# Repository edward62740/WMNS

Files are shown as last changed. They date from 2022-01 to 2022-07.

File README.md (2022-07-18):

# Wireless Mesh Network System (WMNS)

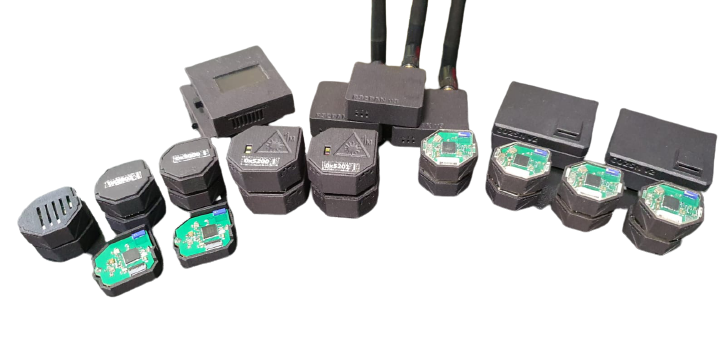
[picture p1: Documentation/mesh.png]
Mesh Devices


## Overview

This is a wireless sensor network system as a part of an ongoing project for smart home sensing and security. The intent is to create easily deployable, low-maintenance (thereby low-power) sensors for real-time collection of non-sensitive data. The various sensors have a battery life typically between 1-4 years off a CR2032 (excl. CO2SN - 4 months, Li-ion).
The data is collected in InfluxDB and can be viewed graphically in Grafana.
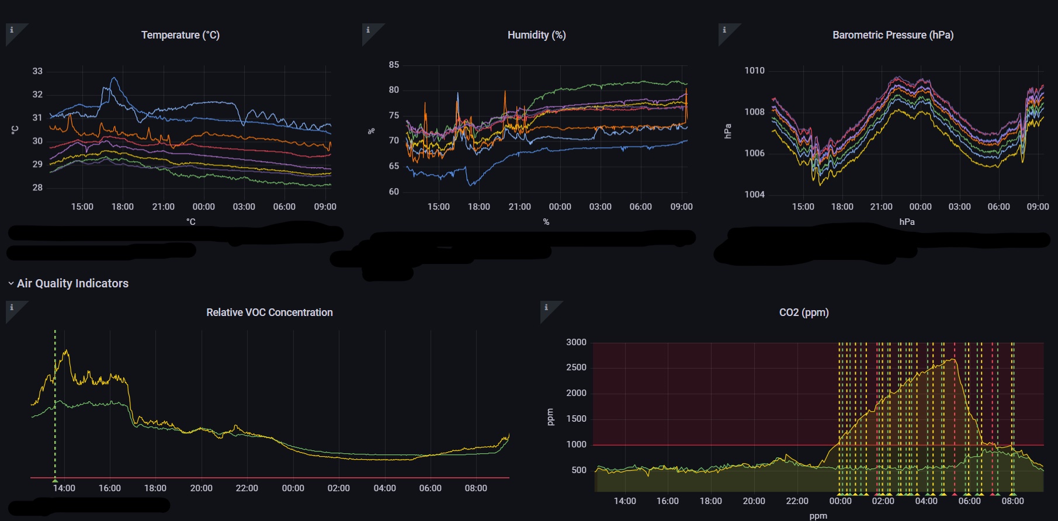
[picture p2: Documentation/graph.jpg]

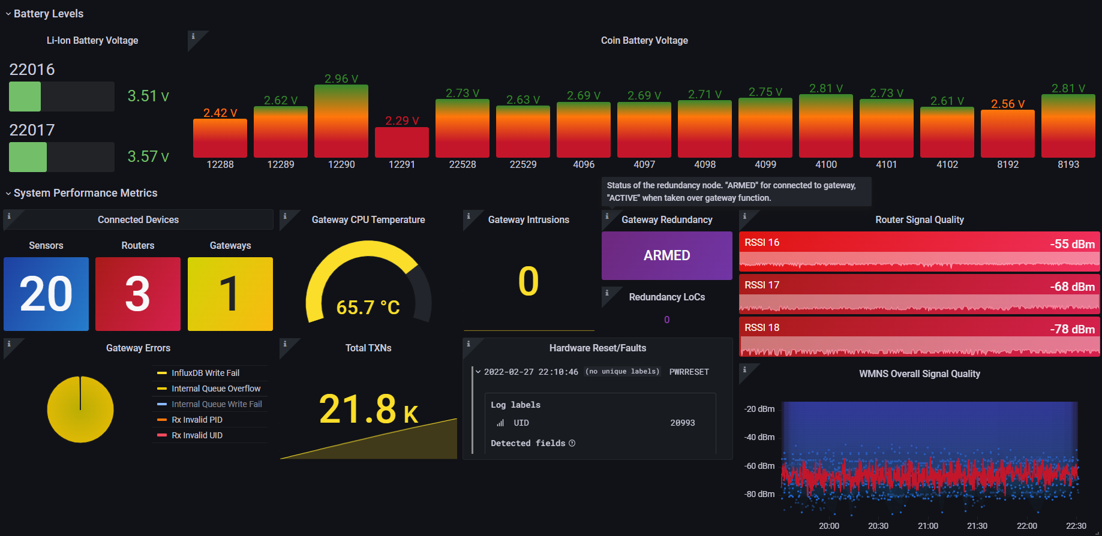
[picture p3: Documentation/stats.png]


## Related Development
_These devices either contribute to the WMNS database or utilize it for their functions._<br>
[PMS](https://github.com/edward62740/wmns-pms) - Particulate matter sensor.<br>
[IN-16 Display](https://github.com/edward62740/wmns-in16) - IN-16 tubes for displaying database information.<br>
[E-Paper Display](https://github.com/edward62740/wmns-epd) - Simple Wi-Fi/BLE enabled e-paper display. Designed for displaying real-time sensor data.<br>
[Lamp](https://github.com/edward62740/wmns-epd) - Mood lamp simulating candle flicker.<br>
[Transposer](https://github.com/edward62740/wmns-transposer) - Python script to transfer data from InfluxDB to Firebase RTDB.<br>

## Network Structure
This wireless mesh network is a proprietary, decentralized flood type network. The network consists of three distinct node types: routers (R), gateways (GT) and low-power end devices (LP).\
Routers retransmit received data to form the backbone of the network.\
Gateways are similar to routers and forward mesh network data to a server/cloud.\
End devices are low-power nodes that sleep for most of the time, periodically transmitting data.

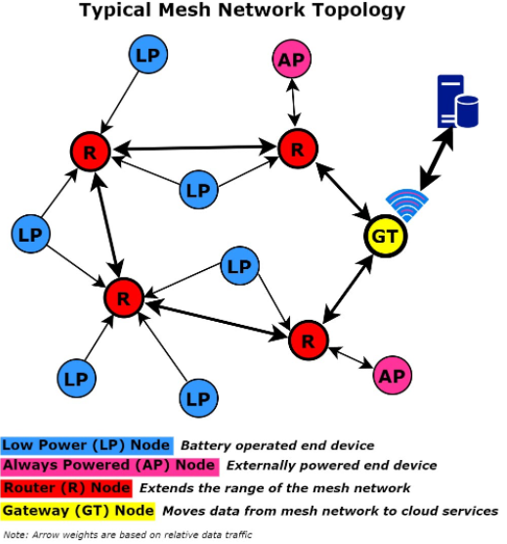
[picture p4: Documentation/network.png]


## Measured data
Currently, the following data is collected by the system through multiple sensor types (sensors in brackets, not necessarily utilized as such):
* Temperature (BME280, BME680, Si7021, SCD41, BMA400, mcu_internal)
* Relative humidity (BME280, BME680, Si7021, SCD41)
* Barometric pressure (BME280, BME680)
* Illuminance (OPT3001, VEML6030, Si1133/5)
* UV levels (Si1133/5)
* Sudden/discontinous motion (BMA400)
* Person counter (VL53L1X)
* CO2 concentration (SCD41)
* VOC concentration (BME680)
* Battery levels (ADC)
* Signal strength (radio)

## Custom Hardware Devices
GPSN             |  LRSN      |  CO2SN  | ALSN
:-------------------------:|:-------------------------:|:-------------------------:|:-------------------------:
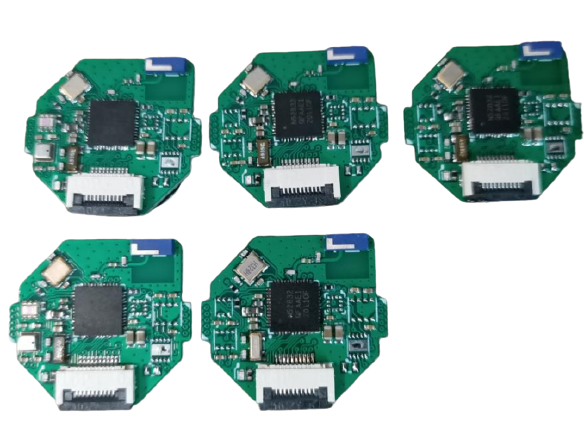
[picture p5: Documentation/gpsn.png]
GPSN
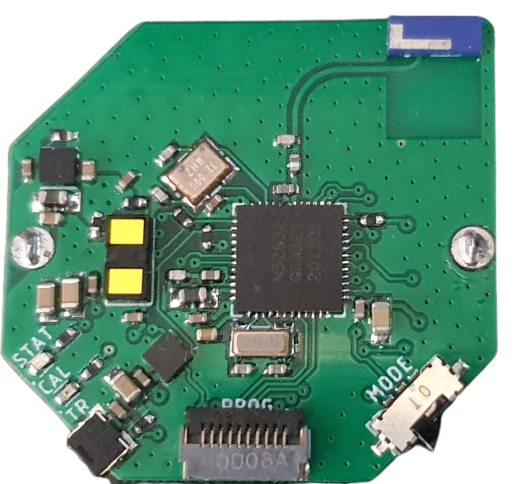
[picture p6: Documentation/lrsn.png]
LRSN
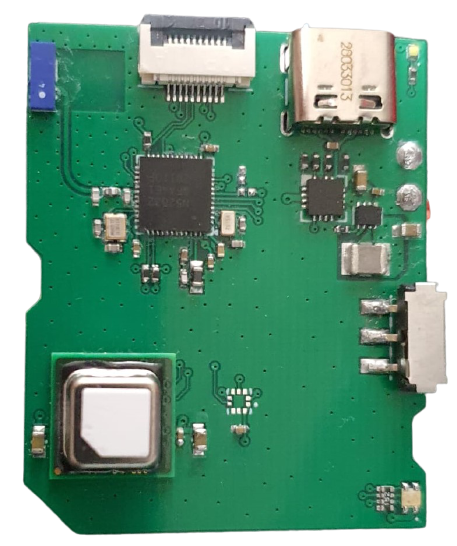
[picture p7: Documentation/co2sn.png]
CO2SN
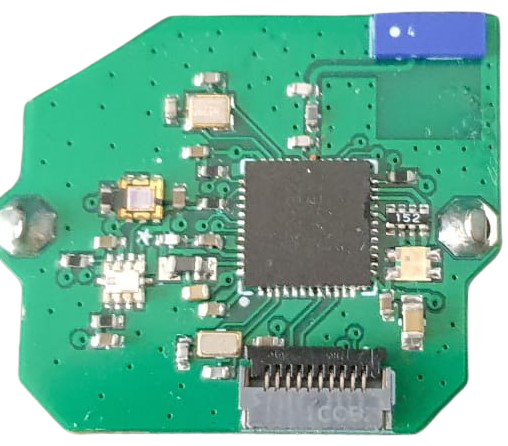
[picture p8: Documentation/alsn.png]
ALSN
<br />General-purpose configurable sensor for: temperature, humidity, air pressure, light, VOCs, motion|<br />Person counter sensor |  <br />Carbon dioxide concentration sensor | <br />Specialized light sensor for visible, UV, IR

GATEWAY             |  ROUTER32PA      |  ROUTER40  | LTSN | TERMINAL
:-------------------------:|:-------------------------:|:-------------------------:|:-------------------------:|:-------------------------:
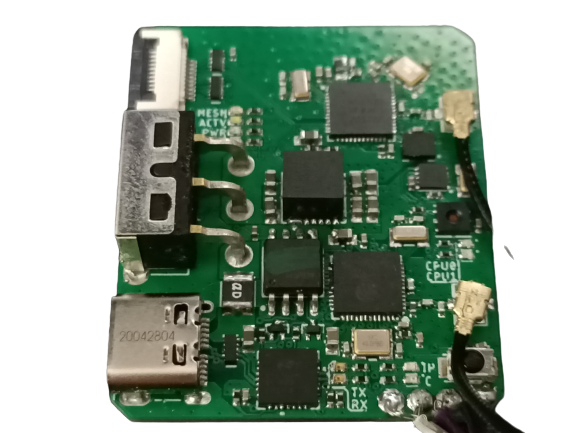
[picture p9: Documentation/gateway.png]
GATEWAY
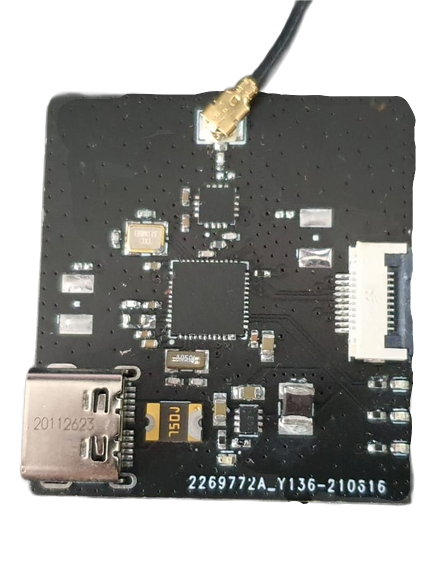
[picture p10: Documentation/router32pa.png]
ROUTER32PA
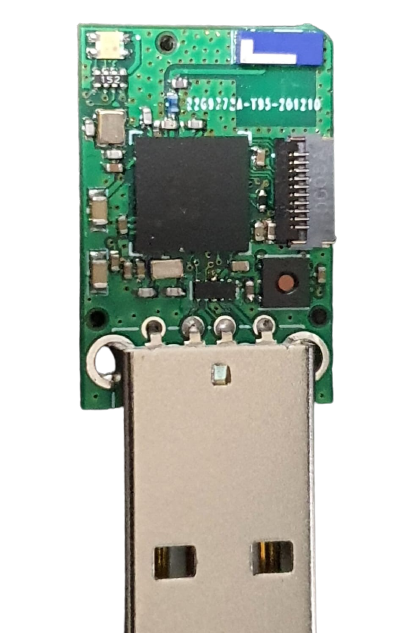
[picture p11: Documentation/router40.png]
ROUTER40
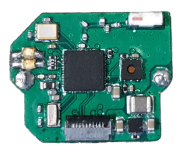
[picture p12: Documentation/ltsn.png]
LTSN
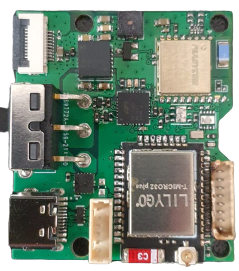
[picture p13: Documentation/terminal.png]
TERMINAL
<br />Internet gateway node  |<br />Power amplified router node |  <br />USB-powered router node |<br />Specialized temp sensor for sub-zero|<br />Security node and gateway redundancy.

## Performance

The following performance factors were considered during the design of the WMNS:
* Low maintenance - essentially long battery life and reliability
</br> _Low power circuit and software design from bottom up. Certain sensors (i.e those expected to face harsher conditions) are conformally coated to increase reliability._
</br> _Network has no central "coordinator" type node which is required to sustain the network. Packets can take multiple paths to the gateway. Gateways can be configured as redundancies._
</br> _Connectionless protocol. No risk of runtime disconnections, failed acks etc. Sensors only need initial positioning in an area with good RSSI and reasonable packet loss from multipath fading._
* Ease of use - able to easily add more sensors (and more types), and modify configurations.
</br> _Easy plug-and-play to add more sensors. Only the gateway needs modifications to add new sensor types (for database side processing)._
</br> _Sensors can easily be configured for different sample rates._
* Range - good wireless range vs power consumption compromise
</br> _Tuned internal antennas allow for lower tx power (and less power consumption)._ 
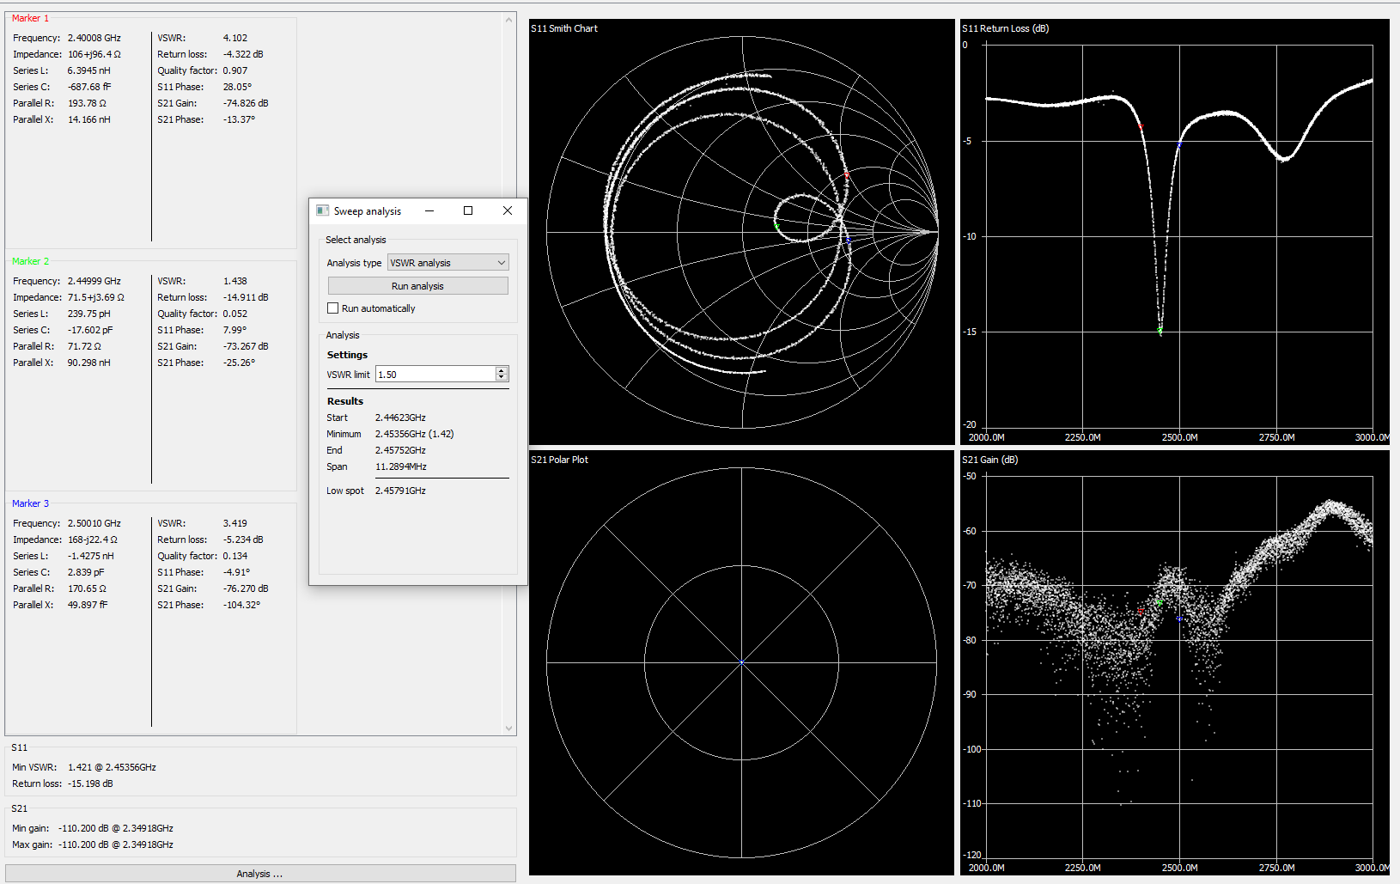
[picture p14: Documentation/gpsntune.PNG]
GPSN Return Loss
</br>
* Low-cost - cheap sensors
</br> _Runs off comparatively low-cost and widely used nRF52 series SoCs. Same design template was used across sensors to drop development time and costs._
</br> _No protocol overhead or IP costs involved._

## Deployment

This system has been deployed in stages since Q1 21 with zero system failures (e.g gateway restarts, sensor malfunctions and drops out of network, hardware failure).
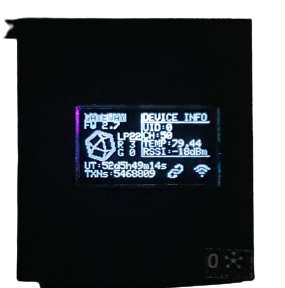
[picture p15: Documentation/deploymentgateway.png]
Gateway Deployment v3.0.1
</br>
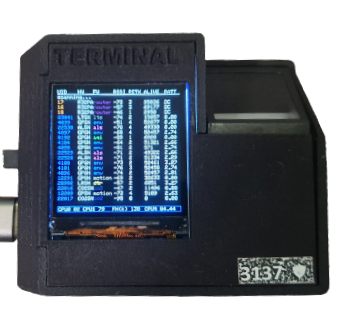
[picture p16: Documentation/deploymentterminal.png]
Terminal Deployment v3.0.1

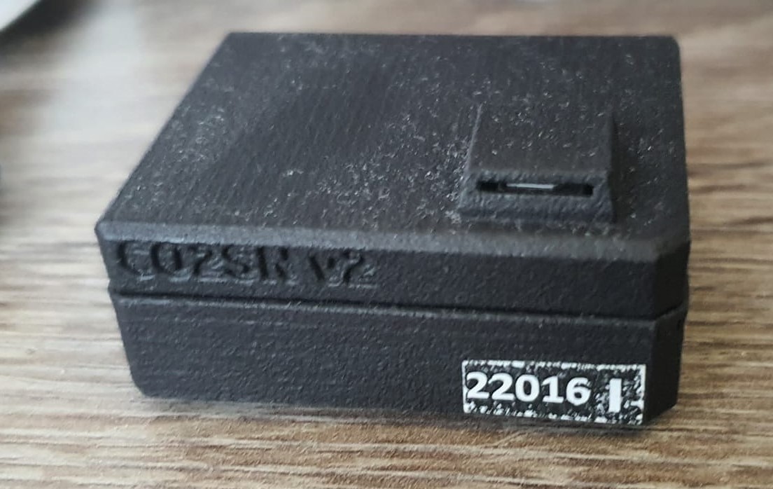
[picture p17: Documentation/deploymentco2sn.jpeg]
CO2SN Deployment v3.0.1

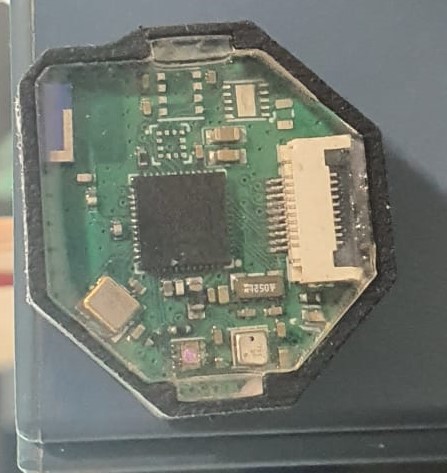
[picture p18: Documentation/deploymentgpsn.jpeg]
GPSN Deployment v3.0.1

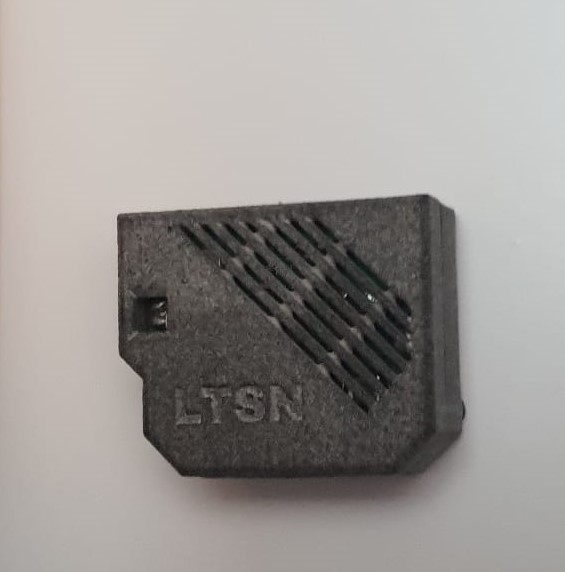
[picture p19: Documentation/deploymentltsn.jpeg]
LTSN Deployment v3.0.1

</br>
Deployed devices: 28

<br>
This repo is released under the GPL-2.0 License. Related repos DO NOT INHERIT licenses.

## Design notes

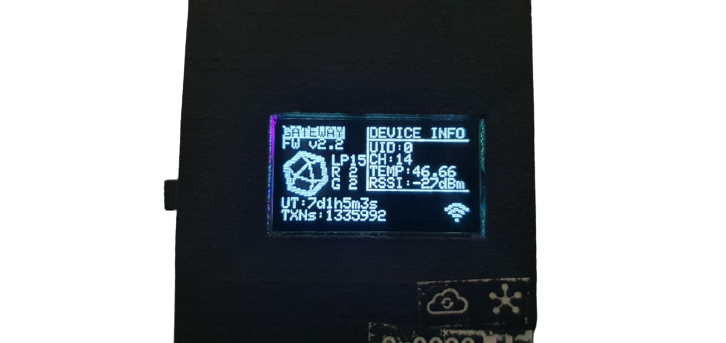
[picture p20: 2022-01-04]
Documentation/gatewayui.png

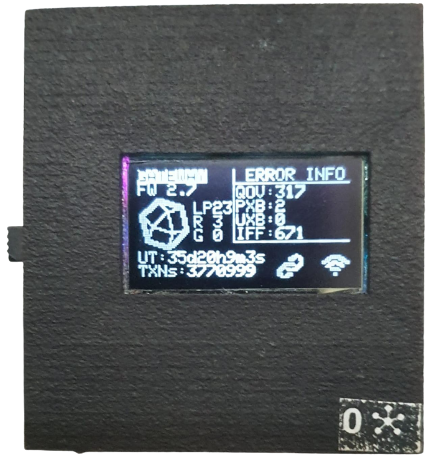
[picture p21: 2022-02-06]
Documentation/deployment.png

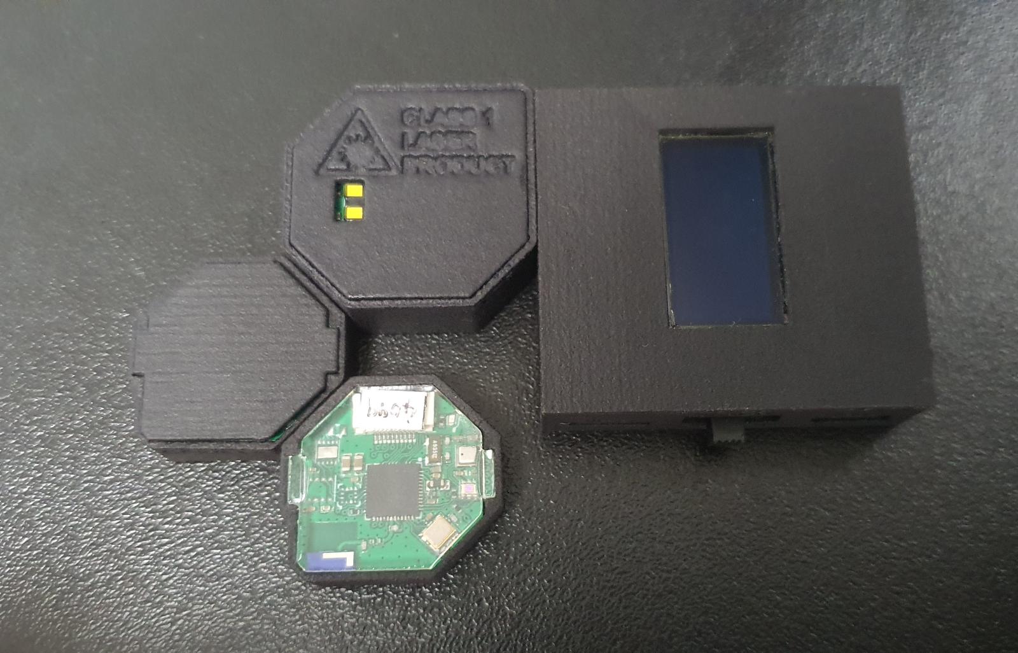
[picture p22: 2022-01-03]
Software Files/nrf_firmware/docu/meshsensorspartial.jpeg

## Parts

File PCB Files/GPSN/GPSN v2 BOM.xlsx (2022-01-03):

Comment | Designator | Footprint
22p | C1 | C0402
22p | C2 | C0402
12p | C3 | C0402
12p | C4 | C0402
10u | C5 | C0402
4.7u | C6 | C0402
100n | C7 | C0603R
0.8p | C8 | C0402
1.2p | C9 | C0402
1u | C10 | C0402
100n | C11 | C0402
1u | C12 | C0402
100n | C13 | C0402
100u | C14 | C0402
100n | C15 | C0402
1u | C16 | C0603R
100n | C17 | C0402
100n | C18 | C0402
100n | C19 | C0402
1u | C29 | C0402
VLMG1500-GS08 | D7 | LEDC1005X35N
3.9u | L1 | INDC0402X26N
10u | L2 | L0603
2.2u | L3 | INDC0402X26N
2.0X1.2 | Q1
10K | R1 | R0402
4.7k | R2 | R0402
4.7k | R3 | R0402
1.5k | R7 | R0402
NRF52832 | U$1 | QFN40P600X600X90-48_N
TI-OPT3001 | U$3 | TI-OPT3001
CHIPANTENNAL2 | U$4 | CHIPANTENNAL2
PCF85063ATL | U1 | SOT1197-1
BME280 | U2 | PSON65P250X250X100-8N
BMA400 | U3 | XDCR_BMA400
52892-1095 | U5 | MOLEX_52892-1095
BME680 | U6 | PSON80P300X300X100-8N
32.768kHz | X1 | ABS07-32.768KHZ-T
32MHz | Y1 | CRYSTAL-SMD-3.2X2.5MM

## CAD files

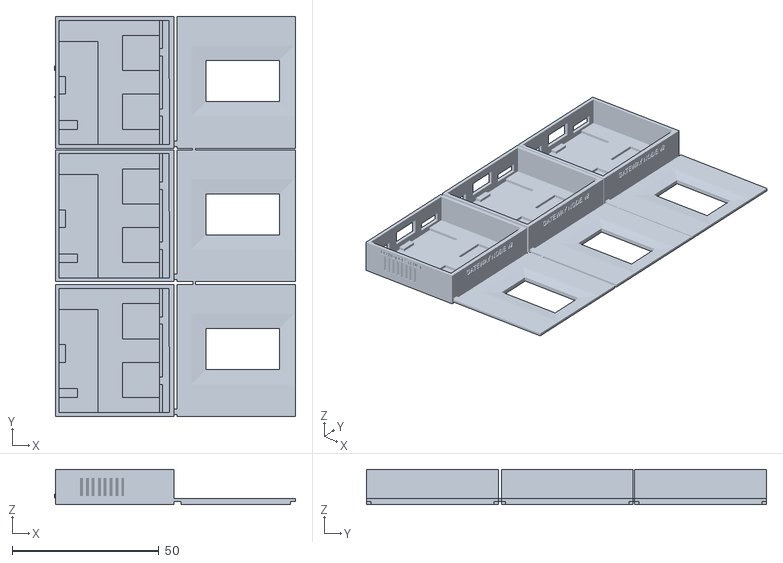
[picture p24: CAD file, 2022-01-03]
Mechanical Files/GATEWAY.stl
82.3 x 136.5 x 12.0

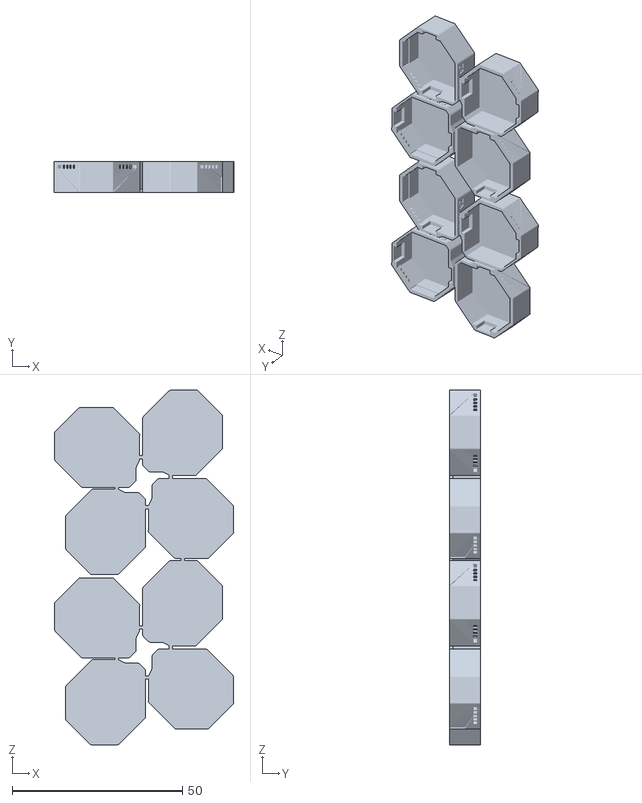
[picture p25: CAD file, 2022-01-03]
Mechanical Files/Final GPSN Enclosure v4.stl
52.7 x 9.00 x 104.2

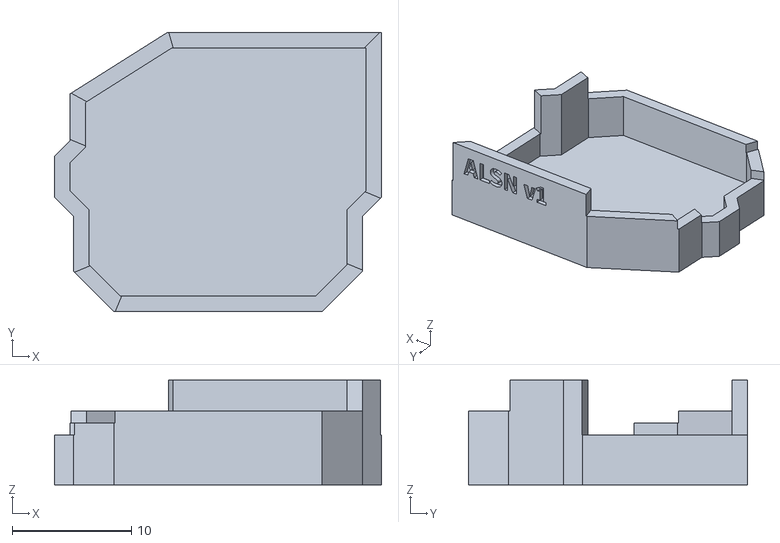
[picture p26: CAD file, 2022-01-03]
Mechanical Files/ALSN BOTTOM.stl
27.4 x 23.4 x 8.79

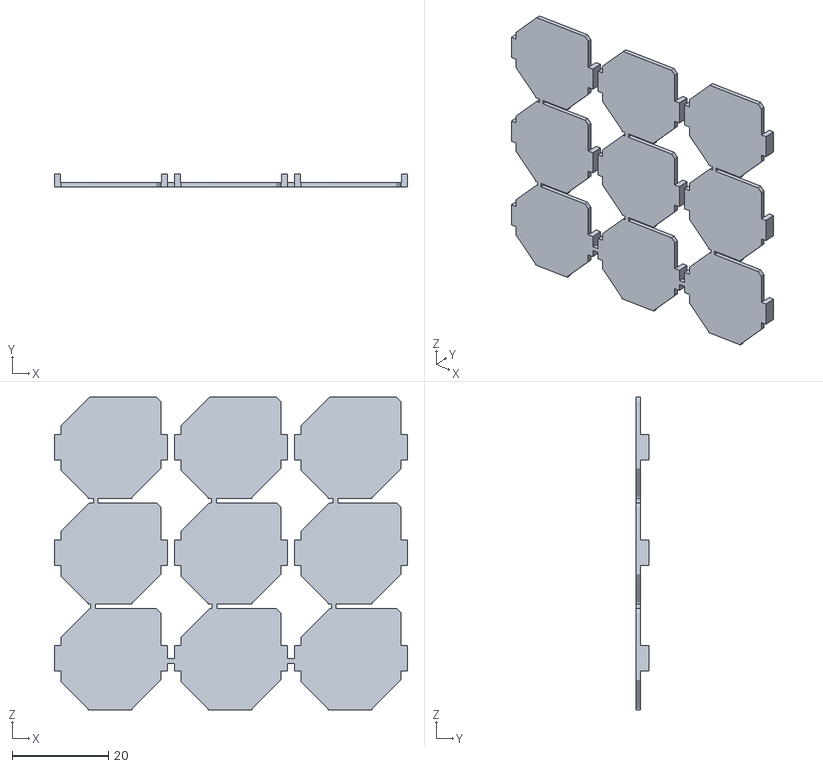
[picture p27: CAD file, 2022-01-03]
Mechanical Files/GPSN TOP.stl
73.5 x 2.80 x 65.1

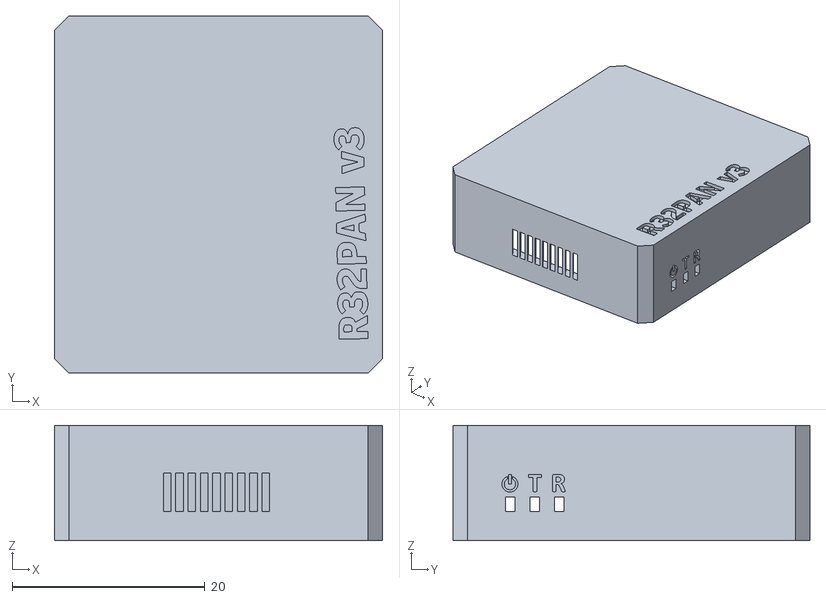
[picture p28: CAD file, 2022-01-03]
Mechanical Files/R32PAN TOP.stl
34.0 x 37.0 x 11.9

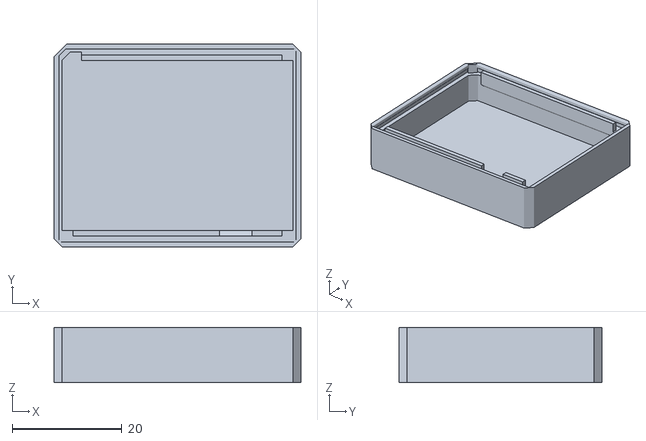
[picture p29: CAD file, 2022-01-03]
Mechanical Files/CO2SN BOTTOM.stl
45.0 x 37.0 x 10.1

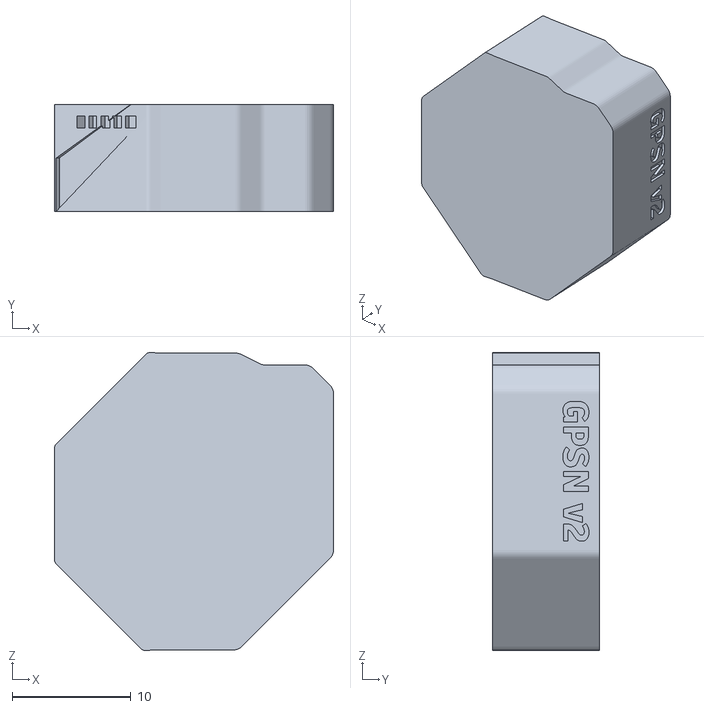
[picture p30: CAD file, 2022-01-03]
Mechanical Files/Final GPSN Enclosure x1.stl
23.5 x 9.00 x 25.1

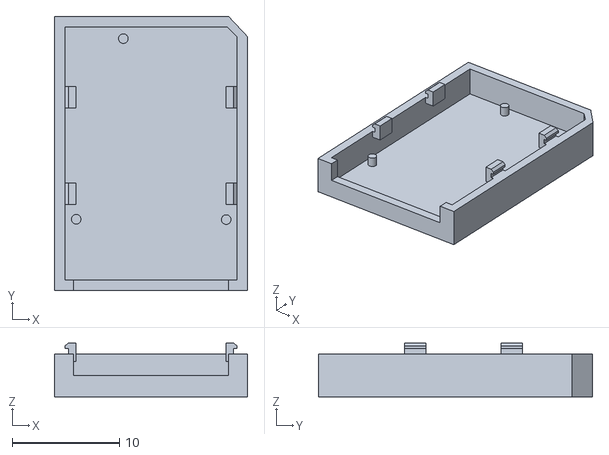
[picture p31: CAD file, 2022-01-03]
Mechanical Files/ROUTER40 BOTTOM.stl
18.0 x 25.5 x 5.00

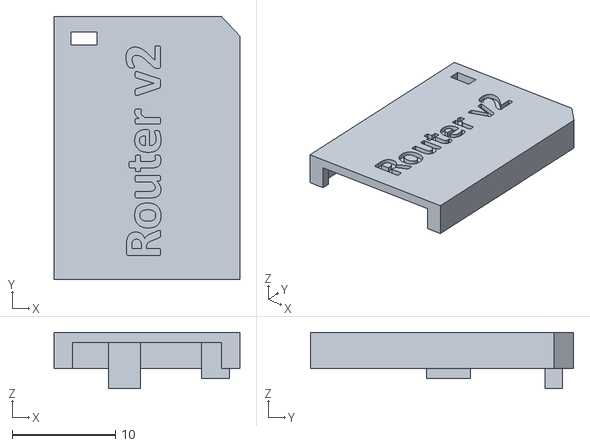
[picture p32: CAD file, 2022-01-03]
Mechanical Files/ROUTER40 TOP.stl
18.0 x 25.5 x 5.45

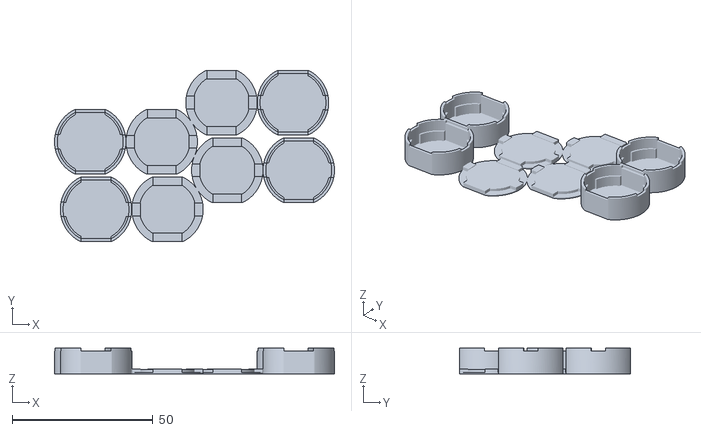
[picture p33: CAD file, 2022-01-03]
Mechanical Files/EFR32 Enclosure.stl
99.4 x 60.8 x 9.20

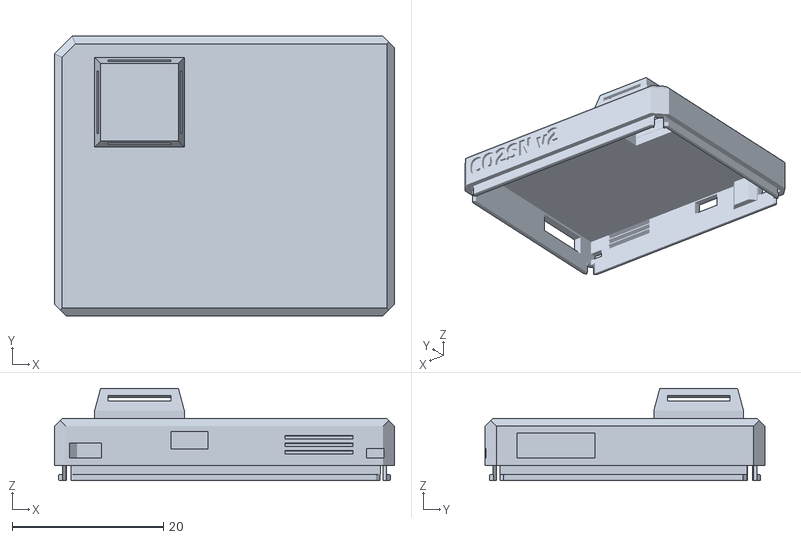
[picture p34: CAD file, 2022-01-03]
Mechanical Files/CO2SN TOP.stl
45.0 x 37.0 x 12.2

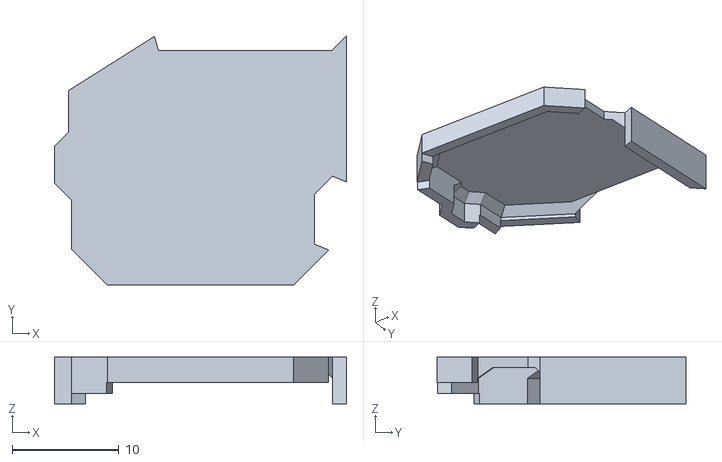
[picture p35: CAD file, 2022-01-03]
Mechanical Files/ALSN TOP.stl
27.4 x 23.4 x 4.41

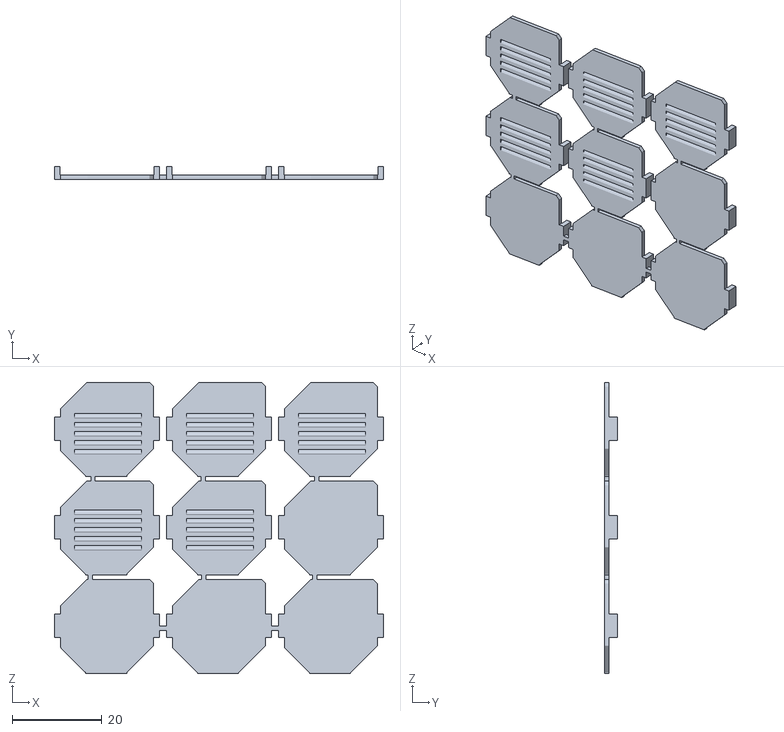
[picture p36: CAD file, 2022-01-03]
Mechanical Files/GPSN TOP VENTS.stl
73.5 x 2.80 x 65.1

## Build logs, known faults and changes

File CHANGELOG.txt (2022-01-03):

CHANGELOG FOR WMNS (nRF) FIRMWARE SINCE Q3 2021 [DEPLOYMENT PHASE]

v1
UNDOCUMENTED; FIRST REVISION OF FIRMWARE

v2.0.1 (15/6/2021)
Added (CO2SN, ALSN) firmware packages, associated board definitions and associated drivers (SCD41_API, lps22hb, si1133, veml6030).

v2.0.2 (29/6/2021)
Modified (CO2SN, ALSN) firmware packages
Cleaned unused/dereferenced.
Changed (ROUTER32PA) alive packet display tx power to 22dBm.
Added reset reason feature to mesh reset packet.
Changed mesh unicast packet function name to mesh_ucast_data().
Changed (GATEWAY) mesh tx power value to 4dBm.

v2.0.3 (8/7/2021)
Enabled mesh cmd function in (GATEWAY) firmware package.

v2.0.4 (14/7/2021)
Disabled (ROUTER32PA) rf-to-serial function.
Changed PID RESET printf value.

v2.0.5 (22/7/2021)
Deleted BME680 API packages.
Deleted (GPSN) airquality firmware, superceded by (GPSN) aqi firmware.
Added sleep mode function and corrections to drivers (bme680).
Modified delay functions in SCD41_API.

v2.0.6 (26/7/2021)
Added (CO2SN) battery voltage monitor.
Added (LRSN) continuous triggering workaround.
Modified (LRSN) packet to transmit warning byte to indicate continuous triggering.
Moved pin name declaration to board definition files.
Imported GATEWAY InfluxDB v2.4 firmware files into {root}/Software Files \.
Refactored (GPSN) iaq firmware to "voc".

v2.0.7 (02/8/2021)
Added TERMINAL v2.sch/.brd to {root}/PCB Files/Terminal \.
Added TERMINAL v1.0 to {root}/Software Files \.

v2.0.8 (14/8/2021)
Added reinitialization for bme280 to reduce power consumption of (GPSN) environment.
Added reinitialization for bme680 to reduce power consumption of (GPSN) voc.
Added intervals.txt to {root}/Software Files/nrf_firmware \.
Refactored (ALSN) alsn firmware to "als".
Moved Gateway_Firebase_v3, Gateway_Firmware_v1.4, Gateway_InfluxDB from {root}/Software Files \ to {root}/Software Files/Depreciated \.
Moved GATEWAY InfluxDB v2.5, TERMINAL v1.0 from {root}/Software Files \ to {root}/Software Files/ESP32 Firmware \.
Modified all devices MESH_PID_xxxx intervals per {root}/Software Files/nrf_firmware/intervals.txt \.

v3.0.0
Changed g_ttl to 3.
Finalized all firmware to intervals.txt.
Changed RF channel from 14 to 50.

v3.0.1 (1/1/2022)
Added (LTSN) branch.

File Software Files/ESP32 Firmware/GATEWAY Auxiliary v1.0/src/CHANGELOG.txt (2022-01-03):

CHANGELOG FOR WMNS (GATEWAY AUXILIARY-ESP32) FIRMWARE SINCE Q3 2021 [DEPLOYMENT PHASE]

v1.0 (30/8/21)
Initial.

v1.1 (31/8/21)
Changed hostname from default to "WMNS GATEWAY AUX".

v1.2 (16/9/21)
Stability update.

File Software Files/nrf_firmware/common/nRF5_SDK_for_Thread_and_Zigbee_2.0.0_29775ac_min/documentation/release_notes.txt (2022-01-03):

nRF5 SDK for Thread and Zigbee v2.0.0
---------------------------
Release Date: Week 39, 2018

This release is the production-ready release of the Thread features available on the nRF52840 chip.
The nRF52840 running the OpenThread stack is Thread 1.1 Certified (https://www.threadgroup.org/What-is-Thread#certifiedproducts).

This release is the production-ready release of the Zigbee features available on the nRF52840 chip.
The nRF52840 running the Zigbee stack conforms to Zigbee PRO R21 + Green Power Proxy specifications. The Zigbee stack provided by the release has been succesfully tested in Zigbee Alliance Authorized Test Laboratory and is pending formal approval from Zigbee Alliance as a Zigbee Compliant Platform. 
The Nordic Zigbee software solution released as part of nRF5 SDK for Thread and Zigbee incorporates the Base Device Behavior 
specification and the latest of the ZCL specification (ver. 7). This enables to build, certify, and ship commercial Zigbee 3.0 Certified Products. 

Software components and application examples for MDK, peripherals, BLE, and NFC
have been inherited from nRF5 SDK v15.2.0. Minor changes to the SDK v15.2.0 are
summarized in the following section.

*** Changes to nRF5 SDK v15.2.0
********************************

- Introduced a new option FDS_VIRTUAL_PAGES_RESERVED to the FDS module to prevent overwriting of persistent data.
- Modified nrf_drv_power driver to prevent double initialization.
- Fixes in the background DFU module.

****** Multiprotocol limitations ******
- Interrupts with IRQ priority 2 and 3 must not be used for multiprotocol examples.
- Limitations of simultaneous operation of the SoftDevice frontend and the 802.15.4 frontend:
	- Do not use the PPI channels reserved by the SoftDevice (17, 18, 19).
	- The SoftDevice and the 802.15.4 driver must use separate sets of PPI channels, for example (1, 2) and (3, 4).
	- The SoftDevice and the 802.15.4 driver must use separate sets of GPIOTE channels, for example 4 and (6, 7).

****** Thread ******

The Thread examples in this SDK are built on top of the OpenThread stack: https://github.com/openthread/openthread.

*** New features
*****************

- Added new examples presenting multiprotocol BLE Scanner and Thread Sleepy End Devices.
- Added new features to the benchmark example: BLE connection and data exchange, and 802.15.4 CSL wake-up sequence simulator.
- Added a new PCA10059 (nRF52840 USB dongle) variant to CLI and NCP examples.

*** Changes
*****************

- Updated pre-built OpenThread libraries for all supported toolchains.
- Updated the Thread Border Router project based on OpenThread's border router project to support the updated OpenThread libraries.
- Updated nRF Thread Topology Monitor with new features, such as:
   - Improved management of serial port, for example adding support for PCA10059.
   - Added indication about number of nodes in the network and TTM node.
   - Added more options for polling time.

*** Limitations
*****************
- Thread initialization must be done outside of the FreeRTOS thread, that is before the FreeRTOS thread is created.

*** Known issues:
*****************
- Nordic OpenThread Border Router occasionally fails to initialize the access point service. Currently,
  a reboot is required in such situations.
- In order to use Ethernet connection on Nordic OpenThread Border Router, the Ethernet cable must be plugged in prior to boot.
- Download and Debug procedure fails under IAR Embedded Workbench with Thread/BLE Dynamic MTD CoAP Client and
  Bluetooth Low Energy Nordic UART Service (NUS) example. To resolve this issue, flash the firmware using nrfjprog directly,
  or proceed as follows:
    - Right-click the project name -> Options -> Linker -> Output -> uncheck "Include debug information in output".
    - Make the project (F7) and repeat the Download and Debug procedure.

*** Compatible tools:
*****************
- nrfutil-4.0.0 (available from https://github.com/NordicSemiconductor/pc-nrfutil)
- nRF Thread Topology Monitor (nRF TTM) v0.12.0-1.alpha
- RaspPi_OT_Border_Router_Demo_v2.0.0-1.alpha.img

These tools are available from https://www.nordicsemi.com/thread#Downloads and https://www.nordicsemi.com/eng/Products/nRF-Thread-Topology-monitor#Downloads

The following OpenThread commit has been used to generate pre-built Thread stack libraries, and for testing and verification:
- https://github.com/openthread/openthread/tree/704511c (with revert of 136a444)

The following nRF IEEE 802.15.4 radio driver has been included in pre-built Thread stack libraries, and used for testing
and verification:
- https://github.com/NordicSemiconductor/nRF-IEEE-802.15.4-radio-driver/tree/68a54db (v1.2.1)

The following wpantund and Border Router commits have been used as part of the
Nordic OpenThread Border Router solution, and for testing and verification:
-	https://github.com/openthread/wpantund/tree/2635e667202577499e04880ed450aae425c72ead
-	https://github.com/openthread/borderrouter/tree/3fd00c00f75c9e7e52f8ced54ddfc7b5fb398b6b

*** Certification
*****************

The OpenThread stack has been officially certified on nRF52840 as Thread Group Certified Component.

The included stack was internally tested using Thread V1.1 Test Harness 1.3.2 R48 and the complete Thread Test Bed.

The DUT device has been tested in the following combinations:

- PCA10056 v1.0.0 - GCC libraries
- PCA10056 v1.0.0 - IAR libraries

All 150 out of 150 tests passed.

The test Router_9_2_10 occasionally fails due to the incorrect test case definition in Thread V1.1 Test Harness 1.3.2 software.
In step 7, the test case checks if unicast MLE Data Response sent to SED includes non-stable data. This problem is being processed
by Thread Group: https://threadgroup.atlassian.net/browse/TSTBED-96. As a workaround, the incorrect step was removed as suggested.

Due to Thread Harness issue and non-compliant implementation of Golden Devices in the Thread Test Bed,
several certification tests fail (https://threadgroup.atlassian.net/browse/TESTPLAN-380) with the default topology config file.
For seven test cases, 5.6.4, 5.6.6, 5.6.9, 7.1.3, 7.1.5, 9.2.6, 9.2.18, an OpenThread device is used as a SED Golden Device.
The modified topology config is available in the release zip. Thread Authorized Test Laboratories
also use OpenThread devices as SED devices in those test cases. The modified topology configuration is available
in the directory \external\openthread\thread_harness\config. This modification is acceptable by Thread Authorized Test
Laboratories until Thread Harness and Golden Device vendors fix the non-compliance issue.

*** Environment
***************

The following toolchains have been used for testing and verification of the examples:
- GCC: GCC ARM Embedded 6.3 2017-q2-update
- IAR: IAR Workbench 7.80.4
- SES: SES 3.40
- ARM: MDK-ARM version 5.18a
- J-Link: 6.34f

Supported SoftDevices for multiprotocol support:
- S140 v6.0.0
- S140 v6.1.0

Supported boards:
- PCA10056 (from version 1.0.0)
- PCA10059

****** Zigbee ******
This release is the first production-ready release of the Zigbee features available on the nRF52840 chip.

*** New features
*****************
- Pre-built Zigbee 3.0 certified (pending formal aproval) stack provided as a library.
- Support for Keil and SES compilers. 
- Support for Zigbee Sleepy End Device role and a light switch example presenting the role.
- Support for Zigbee 3.0 Green Power Proxy feature.
- Support for dynamic memory configuration of the stack.
- Zigbee/Bluetooth LE multiprotocol examples:
  - an example of a Zigbee Sleepy End Device, acting as a BLE Central at the same time.
  - dynamic multiprotocol example template.
- Extended benchmark example with support for Zigbee.
- A Command Line Interface (CLI) example with a support for a subset of the Zigbee stack functionality.
- Added a new PCA10059 (nRF52840 USB dongle) variant to CLI, Zigbee light bulb, Zigbee light bulb + BLE Eddystone beacon, Zigbee Coordinator examples.
- An experimental Zigbee Over-the-Air Device Firmware Update (OTA DFU) example consisting of:
	- Zigbee 3.0/Bluetooth 5.0 multiprotocol Zigbee OTA Upgrade Server which disseminates Zigbee images received over Bluetooth Low Energy,
	- Zigbee OTA Upgrade Client which uses Secure DFU.

*** Changes
*****************
- Updated Zigbee stack pre-built libraries.
- Removed support for touchlink commissioning and associated examples.
- Examples have been power optimized.

*** Limitations
*****************

*** Known issues:
*****************
- Multiprotocol devices: Match Descriptor Response message might not be propagated to the application layer.
- Bluetooth Low Energy Central/Zigbee Sleepy End Device example: Long press of BSP_BUTTON_0 and BSP_BUTTON_1 might be ignored.
- Bluetooth Low Energy Central/Zigbee OTA Server: Self-upgrade might be unsuccessful. Bluetooth Low Energy connection is right after the DFU transfer.
- Bluetooth Low Energy Central/Zigbee OTA Server: Image transfer from iOS requires increasing NRF_FSTORAGE_SD_QUEUE_SIZE to 205.

*** Compatible tools:
*****************
- nrfutil-4.0.0 (available from https://github.com/NordicSemiconductor/pc-nrfutil)
- production config generator tool (available in the SDK package)

The following nRF IEEE 802.15.4 radio driver has been included in the pre-built Zigbee stack libraries, and used for testing
and verification:
- https://github.com/NordicSemiconductor/nRF-IEEE-802.15.4-radio-driver/tree/68a54db (v1.2.1)

*** Environment
***************

The following toolchains have been used for testing and verification of the examples:
- GCC: GCC ARM Embedded 6.3 2017-q2-update
- IAR: IAR Workbench 7.80.4
- SES: SES 3.40
- ARM: MDK-ARM version 5.18a
- J-Link: 6.34f

Supported SoftDevices for multiprotocol support:
- S140 v6.0.0
- S140 v6.1.0

Supported boards:
- PCA10056 (from version 1.0.0)
- PCA10059

========================================================

nRF5 SDK for Thread and Zigbee v1.0.0
---------------------------
Release Date: Week 16, 2018

This release is the first production-ready release of the Thread features available on the nRF52840 chip.
The nRF52840 running the OpenThread stack is Thread 1.1 Certified (https://www.threadgroup.org/What-is-Thread#certifiedproducts).

Zigbee features included in this release are experimental and should only be used to explore and try out on the nRF52840 chip.
The provided Zigbee solution is not Zigbee Alliance Certified. A production release of the Zigbee 3.0 certified stack is scheduled for mid-2018.

Software components and application examples for MDK, peripherals, BLE, and NFC
have been inherited from nRF5 SDK v15.0.0. Minor changes to the SDK v15.0.0 are
summarized in the following section.

*** Changes to nRF5 SDK v15.0.0
********************************
 - USBD BLE UART FreeRTOS example is not working when combined with Nordic UART Service Client example.

- Introduced a new option FDS_VIRTUAL_PAGES_RESERVED to the FDS module to prevent
  overwriting of persistent data.
- Modified the advertising interval of the BLE Eddystone Beacon Example to work with Timeslot API.
- Modified nrf_drv_power driver to prevent double initialization.
- Modified NFC HAL library to fix race condition in HFCLK requesting procedure.
- Modified the way of handling SoftDevice events in the nrf_sdh_freertos module.

****** Thread ******

The Thread examples in this SDK are built on top of the OpenThread stack: https://github.com/openthread/openthread

*** New features
*****************

- Added support for SPI as a transport for NCP.
- Added a new example for benchmarking the Thread network.
- Added new examples presenting MQTT-SN Sleepy End Devices.
- Added a new USB variant to multiprotocol BLE Proximity & Thread CoAP Server example.

*** Changes
*****************

- Updated pre-built OpenThread libraries for all supported toolchains.
- The Thread Border Router project based on OpenWRT and released in previous releases of nRF5 SDK for Thread was
  discontinued and replaced by Nordic OpenThread Border Router based on OpenThread's borderrouter project (Raspbian OS).
- Hardware acceleration using CryptoCell has become the default option in OpenThread repository.

Limitations:
- Interrupts with IRQ priority 2 and 3 should not be used for multiprotocol Thread/Bluetooth LE examples.
- Thread initialization should be done outside of FreeRTOS thread, i.e. before the FreeRTOS thread is created.
- Support for MDK-ARM should be considered as experimental.

Known issues:
- Nordic OpenThread Border Router occasionally fails to initialize access point service. Currently,
  a reboot is required in such situations.
- nRF IEEE 802.15.4 radio driver does not implement a workaround for Anomaly 78 (TIMER: High current consumption when
  using timer STOP task only). The fix has been applied in the SDK inside the thread_sleep() function.
- Download and Debug procedure fails under IAR Embedded Workbench with Thread/BLE Dynamic MTD CoAP Client and
  Bluetooth Low Energy Nordic UART Service (NUS) example. To resolve this issue, flash the firmware using nrfjprog directly,
  or proceed as follows:
    - Right-click the project name -> Options -> Linker -> Output -> uncheck "Include debug information in output".
    - Make the project (F7) and repeat Download and Debug procedure.
- Due to a bug detected in OpenThread libraries for Keil, they have been rebuilt with a specific patch applied
  to the OpenThread repository (it can be found in OpenThread project directory).

Compatible tools:
- nrfutil-3.5.0
- nRF Thread Topology Monitor (nRF TTM) v0.11.0-1.alpha
- RaspPi_OT_Border_Router_Demo_v1.0.0-1.alpha.img
These tools are available from https://www.nordicsemi.com/thread#Downloads

The following OpenThread commit has been used to generate pre-built Thread
stack libraries, and for testing and verification:
- https://github.com/openthread/openthread/commit/ec59d7e

The following nRF IEEE 802.15.4 radio driver has been included in pre-built
Thread stack libraries, and used for testing and verification:
- https://github.com/NordicSemiconductor/nRF-IEEE-802.15.4-radio-driver/commit/d6fc602 (v1.1.0)

The following wpantund and Border Router commits have been used as part of the
Nordic OpenThread Border Router solution, and for testing and verification:
-	https://github.com/openthread/wpantund/commit/1d3e127
-	https://github.com/openthread/borderrouter/commit/d8cb0f0c

*** Certification
*****************

The OpenThread stack has been officially certified on nRF52840 as Thread Group Certified Component.

The included stack was internally tested using Thread V1.1 Test Harness 1.3.0 R48 and the complete Thread Test Bed.

The DUT device has been tested in the following combinations:

- PCA10056 v0.11.0 and PCA10056 v0.9.0 - GCC libraries
- PCA10056 v0.11.0 - IAR libraries

All 150 out of 150 tests passed.

The test Router_9_2_10 occasionally fails due to the incorrect test case definition in Thread V1.1 Test Harness 1.3.0 software.
In step 7, the test case checks if unicast MLE Data Response sent to SED includes non-stable data.

Due to Thread Harness issue and non-compliant implementation of Golden Devices in the Thread Test Bed,
several certification tests fail (https://threadgroup.atlassian.net/browse/TESTPLAN-380) with default topology
config file. For seven test cases, 5.6.4, 5.6.6, 5.6.9, 7.1.3, 7.1.5, 9.2.6, 9.2.18, an OpenThread device is
used as a SED Golden Device. The modified topology config is available in the release zip. Thread Certification Laboratories
also use OpenThread devices as SED devices in those test cases. The modified topology configuration is available
in the directory \external\openthread\thread_harness\config. This modification is acceptable by Thread Certification
Laboratories until Thread Harness and Golden Device vendors fix the non-compliance issue.

*** Environment
***************

The following toolchains have been used for testing and verification of the examples:
- GCC: GCC ARM Embedded 6.3 2017-q2-update
- IAR: IAR Workbench 7.80.4
- SES: SES 3.34
- ARM: MDK-ARM version 5.18a (experimental)
- Jlink: 6.20i

Supported SoftDevices for multiprotocol support:
- S140 v6.0.0

Supported boards:
- PCA10056 (from version 0.9.0)

****** Zigbee ******

*** New features
*****************
- Pre-built Zigbee 3.0 stack provided as a library.
- A light control example demonstrating how to implement a basic Zigbee device
  using one of the three device types: Coordinator, Router, or End Device.
- A light control example with touchlink commissioning support.
- Zigbee/Bluetooth LE multiprotocol examples:
  - an example of a Zigbee Router, acting as a Zigbee dimmable light bulb and Eddystone beacon at the same time.
  - an example of a Zigbee End Device, acting as a light switch and Bluetooth Low Energy Nordic UART Service (NUS) at the same time.
    A variant of this example with support for touchlink Initiator role is also provided.

The following commit of nRF-IEEE-802.15.4-radio-driver has been used for
building the Zigbee stack radio driver:
- https://github.com/NordicSemiconductor/nRF-IEEE-802.15.4-radio-driver/commit/d6fc602 (v1.1.0)

Limitations:
- The provided examples are not power, speed, and size optimized.
- Touchlink support is not certification compliant and has the following limitations:
   - The current Zigbee stack is not resilient to sending out of order commands during touchlink commissioning.
   - Zigbee End Device can be a touchlink Initiator, but not a target.
   - The user callback for the touchlink identify request is not implemented.
   - There is no application signal between Scan Response and Network Start/Network Join Router. This also means that neither
     touchlink identify request nor reset to factory defaults can be sent during the commissioning process.
   - It is impossible to commission the target if it was already commissioned and put into factory default state afterwards.
     The Initiator remembers which devices are included in the network and ignores target responses.
   - It is impossible for the touchlink Initiator to commission devices if the device has joined a centralized network.
   - The touchlink target does not send direct join requests.
- Interrupts with IRQ priority 2 and 3 should not be used for multiprotocol Zigbee/Bluetooth LE examples.
- Zigbee Sleepy End Device role is not supported.
- Zigbee 3.0 Green Power Proxy feature is not supported.
- MDK-ARM IDE and SES IDE are not supported.

*** Environment
***************

The following toolchains have been used for testing and verification of the examples:
- IAR: IAR Workbench 7.80.2 (stack); 7.80.4 (examples)
- GCC: GCC ARM Embedded 6.3 2017-q2-update
- Jlink: 6.20i

Supported SoftDevices for multiprotocol support:
- S140 v6.0.0

Supported boards:
- PCA10056 (from version 0.11.0)

========================================================

nRF5 SDK for Thread v0.11.0
---------------------------
Release Date: Week 47, 2017

This release is an experimental release and should only be used to explore
and try out the Thread features available on the nRF52840 chip.

The Thread examples in this pack are built on top of the OpenThread stack:
https://github.com/openthread/openthread

Software components and application examples for MDK, peripherals, BLE and NFC
have been inherited from nRF5 SDK v14.1.0.

New features:
- Added Segger Embedded Studio (SES) IDE support.
- Added Keil MDK-ARM IDE support.
- Added new examples demonstrating:
  - MQTT-SN Publisher and Subscriber
  - Measurements of packet error rate (PER)
  - NFC pairing in BLE NUS (Nordic UART Service) with Thread MTD running CoAP Client
- Added support for Multicast DFU.
- Added USB transport for CLI and NCP examples.
- Added support for Thread Sleepy End Device role in dynamic multiprotocol solution.
- Added support for Thread sniffer using NCP software.

Changes:
- Updated SDK codebase to nRF5 SDK v14.1.0.
- Updated pre-built OpenThread libraries for all supported toolchains.
- Updated Thread Border Router.
- Introduced Thread and CoAP utils common for all examples.
- Power-optimized all Thread examples.
- Modified the advertising interval of the BLE Eddystone Beacon Example to work with Timeslot API.

Limitations:
- Interrupts with priority 0-4 shall not be used for multiprotocol Thread/BLE examples.
- Due to Thread Harness issue and non-compliant implementation of Golden Devices in the Thread Test Bed,
  several certification tests fail (https://threadgroup.atlassian.net/browse/TESTPLAN-380).
- MQTT-SN client does not support SED role.
- Multiprotocol example ble_thread_dyn_hrs_coap_srv_freertos does not work without optimization.
  For GCC, SES and Keil, the application running with no optimization has undefined behavior.

nRF5 SDK modification:
- Modified the nrf_drv_clock module to set HFCLK state correctly with the SoftDevice.
- Introduced a new option FDS_VIRTUAL_PAGES_RESERVED to the FDS module to prevent
  overwriting of OpenThread's persistent data.
- Added Block2 option support and minor fixes to the IoT CoAP library.
- Modified the Secure DFU library to enable compilation without linking to BLE transport.

Compatible tools:
- nrfutil-3.4.0
- nRF Thread Topology Monitor (nRF TTM) v0.11.0-1.alpha
- RaspPi-Thread-Border-Router-Demo v0.11.0-1.alpha
These tools are available from https://www.nordicsemi.com/thread#Downloads

Supported SoftDevices for multiprotocol support:
- S140 v5.0.0-2.alpha

The following OpenThread commit has been used to generate pre-built Thread
stack libraries, and for testing and verification:
- https://github.com/openthread/openthread/commit/a89eb887

The following wpantund commit has been used as part of the Thread
Border Router solution, and for testing and verification:
https://github.com/openthread/wpantund/commit/418ff17

Certification:
The OpenThread stack has been officially certified on nRF52840 as Thread Group Certified Component.

For certification, the following Thread Harness version has been used:
- Thread V1.1 Test Harness Release 1.1.0 R45

The following OpenThread commit has been used to generate stack libraries:
- https://github.com/openthread/openthread/commit/cfc84c02
- With revert of https://github.com/openthread/openthread/commit/9d66542e commit

The above commit has been reverted because of a known issue in Thread Harness and Thread Test Bed:
 - https://threadgroup.atlassian.net/browse/TESTPLAN-380

While performing Thread Certification tests for Nordic Semiconductor's nRF52840 multiprotocol SoC,
the chip was constantly connected as a Bluetooth low energy 5 peripheral device to a Bluetooth low energy central node,
in addition to performing the Device Under Test (DUT) role for Thread Test Bed. The Bluetooth low energy bit rate was 1 Mbit/s,
and the connection interval was 200 ms. Each node transmitted 18-19 ATT payload bytes to the peer in average 1 s interval.

The following toolchains have been used for testing and verification of the
Thread examples:
- SES: SES 3.30
- ARM: MDK-ARM version 5.18a
- GCC: GCC ARM Embedded 4.9 2015q3
- IAR: IAR Workbench 7.80.4

Supported boards:
- PCA10056

========================================================
nRF5 SDK for Thread v0.10.0
------------------------
Release Date: Week 27, 2017

This release is an experimental release and should only be used to explore
and try out the Thread features available on the nRF52840 chip.

The Thread examples in this pack are built on top of the OpenThread stack:
https://github.com/openthread/openthread

Software components and application examples for MDK, peripherals, BLE, and NFC
have been inherited from nRF5 SDK v.13.0.0.

New features:
- Initial release of Thread/BLE dynamic multiprotocol solution which allows for concurrent operation of
  Thread and BLE utilizing OpenThread and SoftDevice stacks.
- Examples demonstrating dynamic multiprotocol operation of Thread and BLE:
	- BLE NUS (Nordic UART Service) + Thread MTD running CoAP Client
	- BLE Proximity Profile + Thread FTD running CoAP Server
	- BLE Eddystone + Thread FTD running CoAP Server
	- BLE HRS Profile + Thread FTD running CoAP Server + FreeRTOS
	- BLE/Thread dynamic multiprotocol template application
- Example demonstrating the use of FreeRTOS with OpenThread.
- Support for IAR compiler for OpenThread stack and all example applications.

Changes:
- Updated pre-built OpenThread libraries. The update includes support for Thread/BLE dynamic multiprotocol solution and implements workaround for nRF52840 Anomaly no.110:  		  http://infocenter.nordicsemi.com/topic/com.nordic.infocenter.nrf52840.EngA.errata/anomaly_840_110.html
- Updated Thread Border Router.
- Advertising interval of BLE Eddystone Beacon Example has been modified to work with Timeslot API.

Limitations:
- Thread/BLE dynamic multiprotocol solution does not support Thread Sleepy End Device role.
- FreeRTOS does not support tickless mode.

Compatible tools:
- nrfutil-3.0.0 or newer
- nRF Thread Topology Monitor (nRF TTM) v0.8.0-1.alpha
- RaspPi-Thread-Border-Router-Demo v0.10.0-1.alpha
These tools are available from https://www.nordicsemi.com/thread#Downloads

Supported SoftDevices for multiprotocol support:
- S140 v5.0.0-2.alpha

The following OpenThread commit has been used to generate pre-built Thread
stack libraries, and for testing and verification:
- https://github.com/openthread/openthread/commit/6a15261b

The following wpantund commit has been used as part of the Thread
Border Router solution, and for testing and verification:
https://github.com/openthread/wpantund/commit/d8259642

The following toolchains have been used for testing and verification of the
Thread examples:
- GCC: GCC ARM Embedded 4.9 2015q3
- IAR: IAR Workbench 7.60.2

Supported boards:
- PCA10056

========================================================

nRF5 SDK for Thread v0.9.0
------------------------
Release Date: Week 19, 2017

This release is an experimental release and should only be used to explore
and try out the Thread features available on the nRF52840 chip.

The Thread examples in this pack are built on top of the OpenThread stack
https://github.com/openthread/openthread

Software components and application examples for MDK, peripherals, BLE, and NFC
have been inherited from nRF5 SDK v.13.0.0.

New features:
- Examples demonstrating multiprotocol support and switching between BLE peripheral
  and Thread FTD and MTD roles.
- Thread Border Router has been updated to support Wi-Fi link connectivity.
- Support for DNS64 in Thread Border Router.
- Support for DNSv6 client for Thread nodes.
- Added hardware acceleration for SHA256 and AES-ECB cryptographic procedures
  using ARM CryptoCell (hardware acceleration for ECC was already introduced in v0.8.0).

Changes:
- Updated Thread Cloud CoAP Client example to use DNS instead of hardcoded IPv6 address of the
  cloud.
- Updated pre-built OpenThread libraries.

Compatible tools:
- nrfutil-2.1.0dev2
- nRF Thread Topology Monitor (nRF TTM) v0.8.0-1.alpha
- RaspPi-Thread-Border-Router-Demo v0.9.0-1.alpha
These tools are available from https://www.nordicsemi.com/thread#Downloads

Supported SoftDevices for multiprotocol support:
- S140 v5.0.0-2.alpha

The following OpenThread commit has been used to generate pre-built Thread
stack libraries, and for testing and verification:
https://github.com/openthread/openthread/commit/030efba

The following wpantund commit has been used as part of the Thread
Border Router solution, and for testing and verification:
- https://github.com/openthread/wpantund/commit/c2cf75a

The following wpantund patch has been applied to add native commissioner
functionality:
- https://github.com/NordicSemiconductor/thread_border_router_feeds/blob/master/wpantund/patches

The following toolchains have been used for testing and verification of the
Thread examples:
- GCC: GCC ARM Embedded 4.9 2015q3

Supported boards:
- PCA10056

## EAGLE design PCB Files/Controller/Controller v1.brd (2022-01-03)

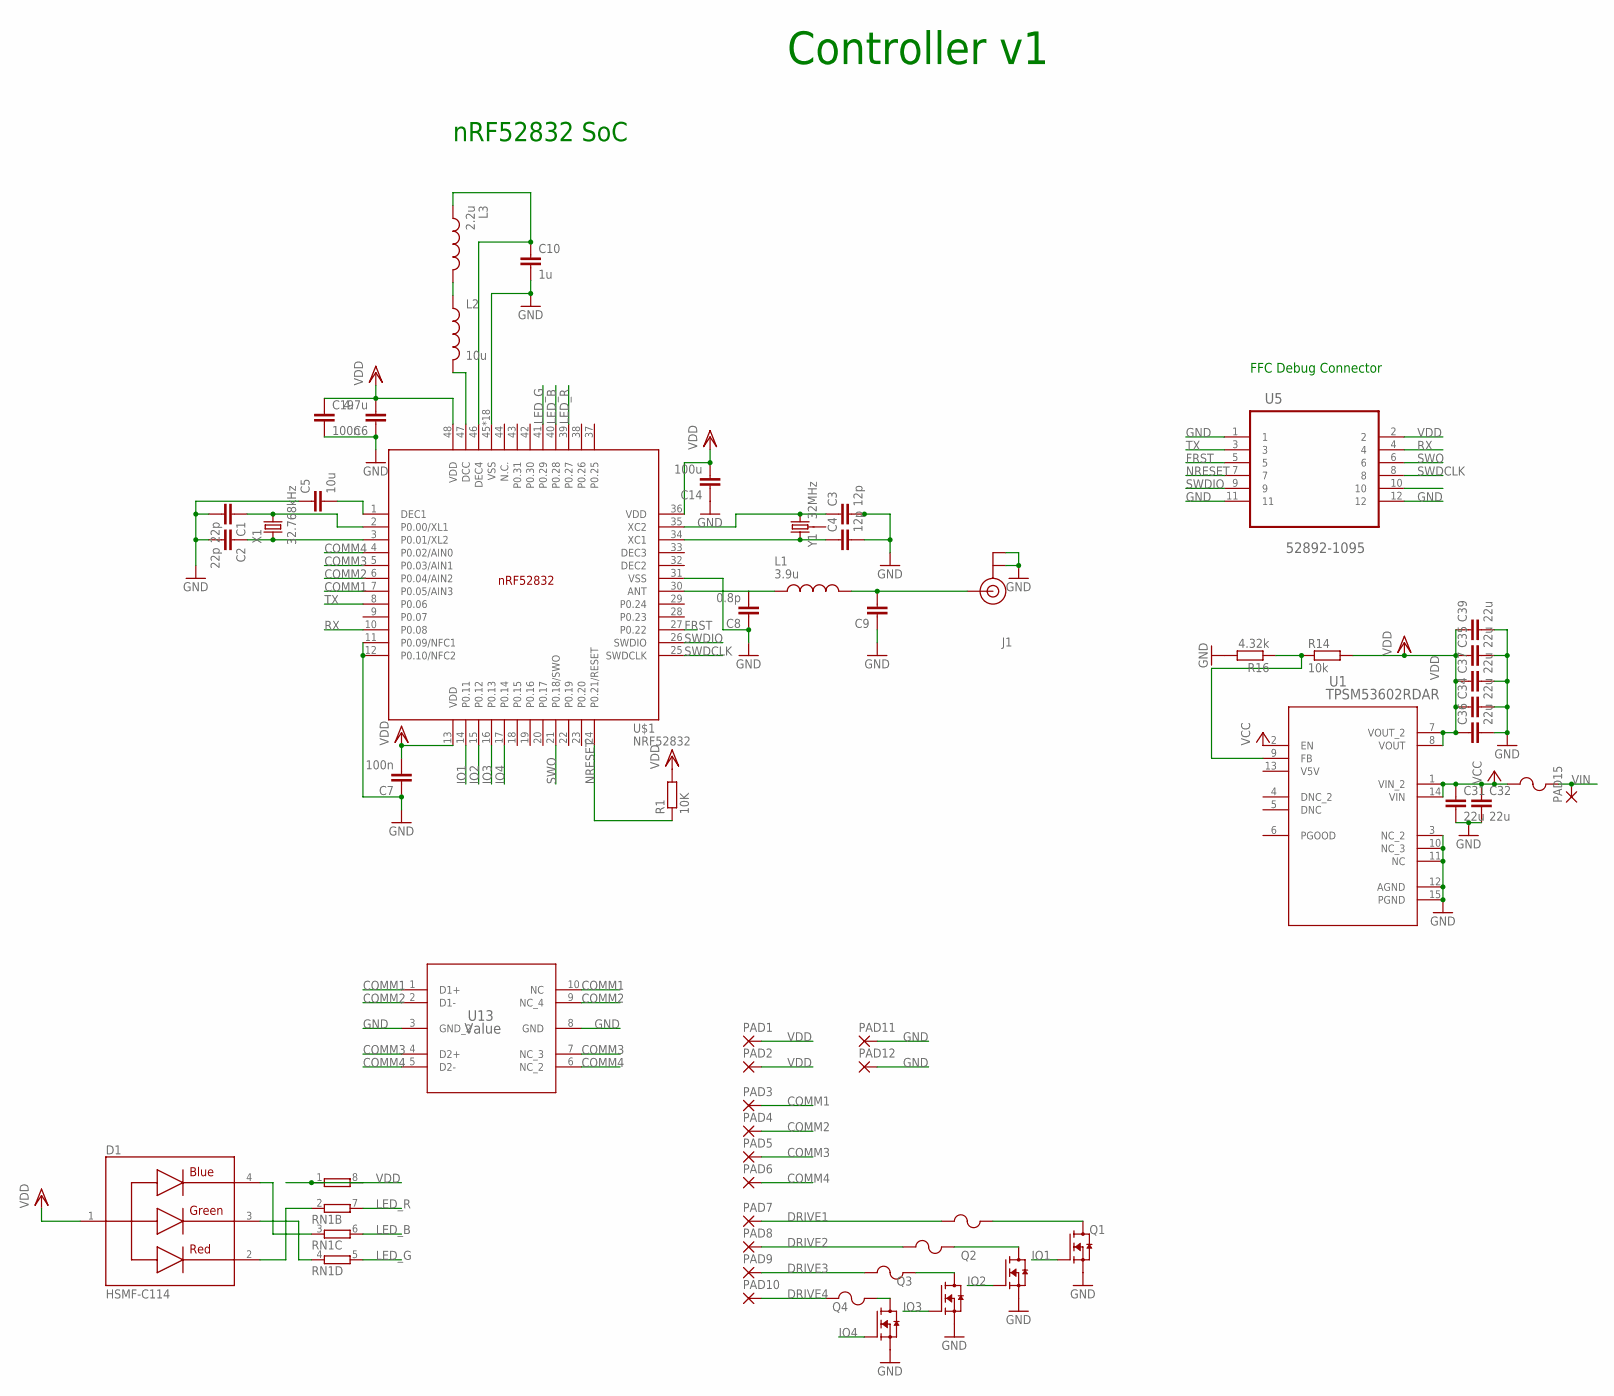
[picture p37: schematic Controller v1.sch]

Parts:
C1, C2: 22p; C0402
C3, C4: 12p; C0402
C5: 10u; C0402
C6: 4.7u; C0402
C7: 100n; C0603R
C8: 0.8p; C0402
C9: 1.2p; C0402
C10: 1u; C0402
C14: 100u; C0402
C19: 100n; C0402
C31, C32, C34, C35, C36, C37, C39: 22u; C0603R
D1: HSMF-C114; DIOSC160X150X35-4N
F1, F2, F3, F4, F5: 1210L050YR1210LSERIES_LTF-L; 1210LSERIES_LTF-L
J1: U.FL
L1: 3.9u; INDC0402X26N
L2: 10u; L0603
L3: 2.2u; INDC0402X26N
PAD1, PAD2, PAD3, PAD4, PAD5, PAD6, PAD7, PAD8, PAD9, PAD10, PAD11, PAD12, PAD15: 2,54/1,1
Q1, Q2, Q3, Q4: CSD16301Q2; TRANS_CSD16301Q2
R1: 10K; R0402
R14: 10k; R0402
R16: 4.32k; R0402
RN1: 4R-N0402ARV341; 4X0402ARV341
U1: TPSM53602RDAR; B3QFN15_RDA_TEX
U5: 52892-1095; MOLEX_52892-1095
U13: Value; DQA0010A
U$1: NRF52832; QFN40P600X600X90-48_N
X1: 32.768kHz; ABS07-32.768KHZ-T
Y1: 32MHz; CRYSTAL-SMD-3.2X2.5MM

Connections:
COMM1: PAD3.1, U13.1 (D1+), U13.10 (NC), U$1.7 (P0.05/AIN3)
COMM2: PAD4.1, U13.2 (D1-), U13.9 (NC_4), U$1.6 (P0.04/AIN2)
COMM3: PAD5.1, U13.4 (D2+), U13.7 (NC_3), U$1.5 (P0.03/AIN1)
COMM4: PAD6.1, U13.5 (D2-), U13.6 (NC_2), U$1.4 (P0.02/AIN0)
DRIVE1: F5.1, PAD7.1
DRIVE2: F4.1, PAD8.1
DRIVE3: F2.1, PAD9.1
DRIVE4: F3.1, PAD10.1
FRST: U5.5, U$1.27 (P0.22)
GND: C1.2, C2.2, C3.2, C4.2, C5.1, C6.1, C7.1, C8.1, C9.1, C10.2, C14.1, C19.2, C31.2, C32.2, C34.2, C35.2, C36.2, C37.2, C39.2, J1.1 (GND), J1.2 (GND), PAD11.1, PAD12.1, Q1.4 (S), Q1.7 (S), Q2.4 (S), Q2.7 (S), Q3.4 (S), Q3.7 (S), Q4.4 (S), Q4.7 (S), R16.2, U1.3 (NC_2), U1.10 (NC_3), U1.11 (NC), U1.12 (AGND), U1.15 (PGND), U5.1, U5.11, U5.12, U13.3 (GND_2), U13.8 (GND), U$1.11 (P0.09/NFC1), U$1.12 (P0.10/NFC2), U$1.31 (VSS), U$1.45 (VSS), U$1.PAD (VSS), U$1.PAD@VIA01 (VSS), U$1.PAD@VIA02 (VSS), U$1.PAD@VIA03 (VSS), U$1.PAD@VIA04 (VSS), U$1.PAD@VIA05 (VSS), U$1.PAD@VIA06 (VSS), U$1.PAD@VIA07 (VSS), U$1.PAD@VIA08 (VSS), U$1.PAD@VIA09 (VSS), U$1.PAD@VIA10 (VSS), U$1.PAD@VIA11 (VSS), U$1.PAD@VIA12 (VSS), U$1.PAD@VIA13 (VSS), U$1.PAD@VIA14 (VSS), U$1.PAD@VIA15 (VSS), U$1.PAD@VIA16 (VSS)
IO1: Q1.3 (G), U$1.14 (P0.11)
IO2: Q2.3 (G), U$1.15 (P0.12)
IO3: Q3.3 (G), U$1.16 (P0.13)
IO4: Q4.3 (G), U$1.17 (P0.14)
LED_B: RN1.6 (2), U$1.40 (P0.28)
LED_G: RN1.5 (2), U$1.41 (P0.29)
LED_R: RN1.7 (2), U$1.39 (P0.27)
unnamed: C1.1, U$1.2 (P0.00/XL1), X1.2
unnamed: C2.1, U$1.3 (P0.01/XL2), X1.1
unnamed: C3.1, U$1.35 (XC2), Y1.3 (2)
unnamed: C4.1, U$1.34 (XC1), Y1.1
unnamed: C5.2, U$1.1 (DEC1)
unnamed: C8.2, L1.1, U$1.30 (ANT)
unnamed: F2.2, Q3.1 (D), Q3.2 (D), Q3.5 (D), Q3.6 (D), Q3.8 (D)
unnamed: F3.2, Q4.1 (D), Q4.2 (D), Q4.5 (D), Q4.6 (D), Q4.8 (D)
unnamed: L2.2, U$1.47 (DCC)
unnamed: L2.1, L3.2
unnamed: C10.1, L3.1, U$1.46 (DEC4)
unnamed: D1.2, RN1.2 (1)
unnamed: D1.3, RN1.4 (1)
unnamed: D1.4, RN1.3 (1)
unnamed: F4.2, Q2.1 (D), Q2.2 (D), Q2.5 (D), Q2.6 (D), Q2.8 (D)
unnamed: F5.2, Q1.1 (D), Q1.2 (D), Q1.5 (D), Q1.6 (D), Q1.8 (D)
unnamed: R14.1, R16.1, U1.9 (FB)
NRESET: R1.1, U5.7, U$1.24 (P0.21/RESET)
RF: C9.2, J1.FEED (SIGNAL), L1.2
RX: U5.4, U$1.10 (P0.08)
SWDCLK: U5.8, U$1.25 (SWDCLK)
SWDIO: U5.9, U$1.26 (SWDIO)
SWO: U5.6, U$1.21 (P0.18/SWO)
TX: U5.3, U$1.8 (P0.06)
VCC: C31.1, C32.1, F1.1, U1.1 (VIN_2), U1.2 (EN), U1.14 (VIN)
VDD: C6.2, C7.2, C14.2, C19.1, C34.1, C35.1, C36.1, C37.1, C39.1, D1.1, PAD1.1, PAD2.1, R1.2, R14.2, RN1.1, RN1.8 (2), U1.7 (VOUT_2), U1.8 (VOUT), U5.2, U$1.13 (VDD), U$1.36 (VDD), U$1.48 (VDD)
VIN: F1.2, PAD15.1

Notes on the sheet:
nRF52832 SoC
FFC Debug Connector
Controller v1

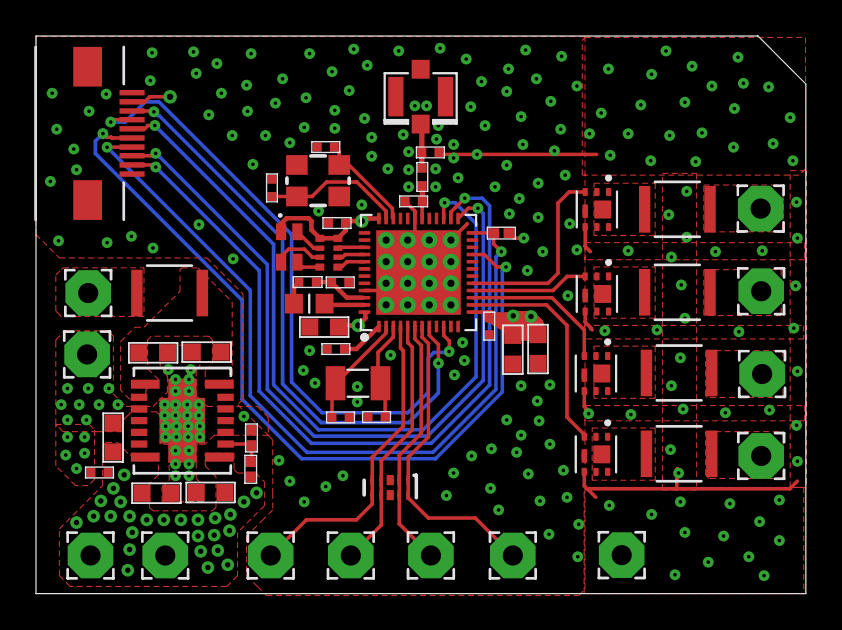
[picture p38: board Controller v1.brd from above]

Board: 4 copper layers, 42.8 x 31.0 mm, 56 parts (0 on the bottom side), 44 nets.

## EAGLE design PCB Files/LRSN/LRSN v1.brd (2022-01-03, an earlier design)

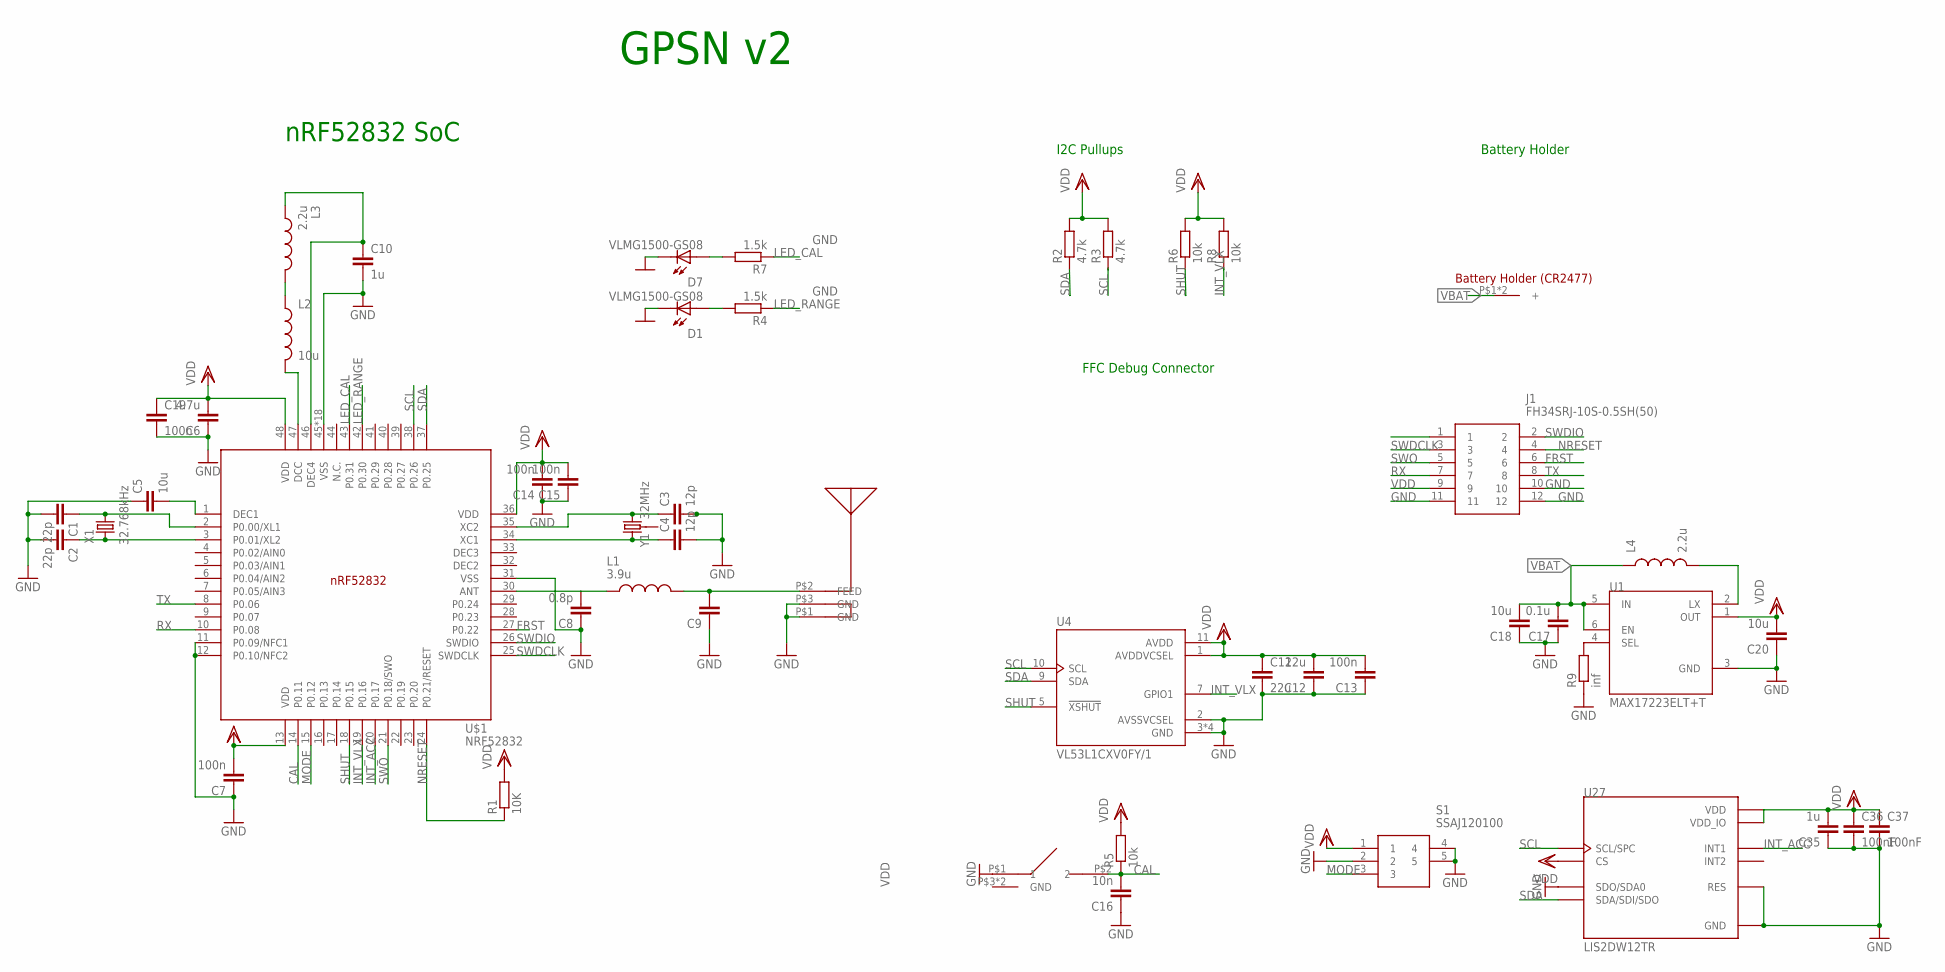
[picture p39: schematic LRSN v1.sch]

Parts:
C1, C2: 22p; C0402
C3, C4: 12p; C0402
C5, C18, C20: 10u; C0402
C6: 4.7u; C0402
C7: 100n; C0603R
C8: 0.8p; C0402
C9: 1.2p; C0402
C10: 1u; C0402
C11, C12: 22u; C0603R
C13, C14, C15, C19: 100n; C0402
C16: 10n; C0402
C17: 0.1u; C0402
C35: 1u; C0603R
C36, C37: 100nF; C0402
D1, D7: VLMG1500-GS08; LEDC1005X35N
J1: FH34SRJ-10S-0.5SH(50); FH34SRJ10S05SH50
L1: 3.9u; INDC0402X26N
L2: 10u; L0603
L3: 2.2u; INDC0402X26N
L4: 2.2u; L0603
R1: 10K; R0402
R2, R3: 4.7k; R0402
R4, R7: 1.5k; R0402
R5, R6, R8: 10k; R0402
R9: inf; R0402
S1: SSAJ120100
U1: MAX17223ELT+T; PSON65P200X200X80-6N
U4: VL53L1CXV0FY/1; SENSOR_VL53L1CXV0FY/1
U27: LIS2DW12TR; LGA12R50P4X4_200X200X70
U$1: NRF52832; QFN40P600X600X90-48_N
U$3: T1C2QR
U$4: CHIPANTENNAL2
VBAT: CR2477HOLDER
X1: 32.768kHz; ABS07-32.768KHZ-T
Y1: 32MHz; CRYSTAL-SMD-3.2X2.5MM

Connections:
CAL: C16.2, R5.1, U$1.14 (P0.11), U$3.P$2 (2)
FRST: J1.6, U$1.27 (P0.22)
GND: C1.2, C2.2, C3.2, C4.2, C5.1, C6.1, C7.1, C8.1, C9.1, C10.2, C11.2, C12.1, C13.1, C14.1, C15.1, C16.1, C17.1, C18.1, C19.2, C20.1, C35.1, C36.2, C37.2, D1.2, D7.2, J1.10, J1.11, J1.12, R9.1, S1.2, S1.4, S1.5, U1.3 (GND), U4.2 (AVSSVCSEL), U4.3 (GND), U4.4 (GND), U4.6 (GND), U4.12 (GND), U27.3 (SDO/SDA0), U27.6 (GND), U27.7 (RES), U27.8 (GND), U$1.11 (P0.09/NFC1), U$1.12 (P0.10/NFC2), U$1.31 (VSS), U$1.45 (VSS), U$1.PAD (VSS), U$1.PAD@VIA01 (VSS), U$1.PAD@VIA02 (VSS), U$1.PAD@VIA03 (VSS), U$1.PAD@VIA04 (VSS), U$1.PAD@VIA05 (VSS), U$1.PAD@VIA06 (VSS), U$1.PAD@VIA07 (VSS), U$1.PAD@VIA08 (VSS), U$1.PAD@VIA09 (VSS), U$1.PAD@VIA10 (VSS), U$1.PAD@VIA11 (VSS), U$1.PAD@VIA12 (VSS), U$1.PAD@VIA13 (VSS), U$1.PAD@VIA14 (VSS), U$1.PAD@VIA15 (VSS), U$1.PAD@VIA16 (VSS), U$3.P$1 (1), U$4.P$1 (GND), U$4.P$3 (GND)
INT_ACC: U27.12 (INT1), U$1.20 (P0.17)
INT_VLX: R8.1, U4.7 (GPIO1), U$1.19 (P0.16)
LED_CAL: R7.1, U$1.43 (P0.31)
LED_RANGE: R4.1, U$1.42 (P0.30)
MODE: S1.3, U$1.15 (P0.12)
unnamed: C1.1, U$1.2 (P0.00/XL1), X1.2
unnamed: C2.1, U$1.3 (P0.01/XL2), X1.1
unnamed: C3.1, U$1.35 (XC2), Y1.3 (2)
unnamed: C4.1, U$1.34 (XC1), Y1.1
unnamed: C5.2, U$1.1 (DEC1)
unnamed: C8.2, L1.1, U$1.30 (ANT)
unnamed: D1.1, R4.2
unnamed: R9.2, U1.4 (SEL)
unnamed: L2.2, U$1.47 (DCC)
unnamed: L2.1, L3.2
unnamed: C10.1, L3.1, U$1.46 (DEC4)
unnamed: L4.2, U1.2 (LX)
unnamed: D7.1, R7.2
NRESET: J1.4, R1.1, U$1.24 (P0.21/RESET)
RF: C9.2, L1.2, U$4.P$2 (FEED)
RX: J1.7, U$1.10 (P0.08)
SCL: R3.1, U4.10 (SCL), U27.1 (SCL/SPC), U$1.38 (P0.26)
SDA: R2.1, U4.9 (SDA), U27.4 (SDA/SDI/SDO), U$1.37 (P0.25)
SHUT: R6.1, U4.5 (!XSHUT), U$1.18 (P0.15)
SWDCLK: J1.3, U$1.25 (SWDCLK)
SWDIO: J1.2, U$1.26 (SWDIO)
SWO: J1.5, U$1.21 (P0.18/SWO)
TX: J1.8, U$1.8 (P0.06)
VBAT: C17.2, C18.2, L4.1, U1.5 (IN), U1.6 (EN), VBAT.P$1, VBAT.P$2
VDD: C6.2, C7.2, C11.1, C12.2, C13.2, C14.2, C15.2, C19.1, C20.2, C35.2, C36.1, C37.1, J1.9, R1.2, R2.2, R3.2, R5.2, R6.2, R8.2, S1.1, U1.1 (OUT), U4.1 (AVDDVCSEL), U4.11 (AVDD), U27.2 (CS), U27.9 (VDD), U27.10 (VDD_IO), U$1.13 (VDD), U$1.36 (VDD), U$1.48 (VDD)

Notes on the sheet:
nRF52832 SoC
I2C Pullups
Battery Holder
FFC Debug Connector
GPSN v2

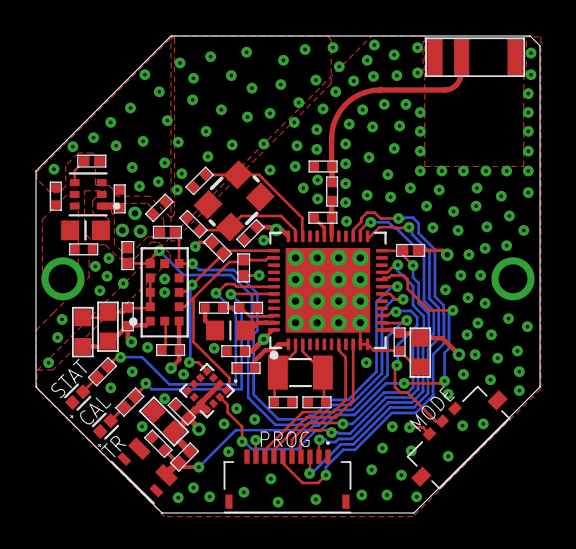
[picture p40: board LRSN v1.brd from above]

Board: 4 copper layers, 28.0 x 26.5 mm, 49 parts (0 on the bottom side), 33 nets.

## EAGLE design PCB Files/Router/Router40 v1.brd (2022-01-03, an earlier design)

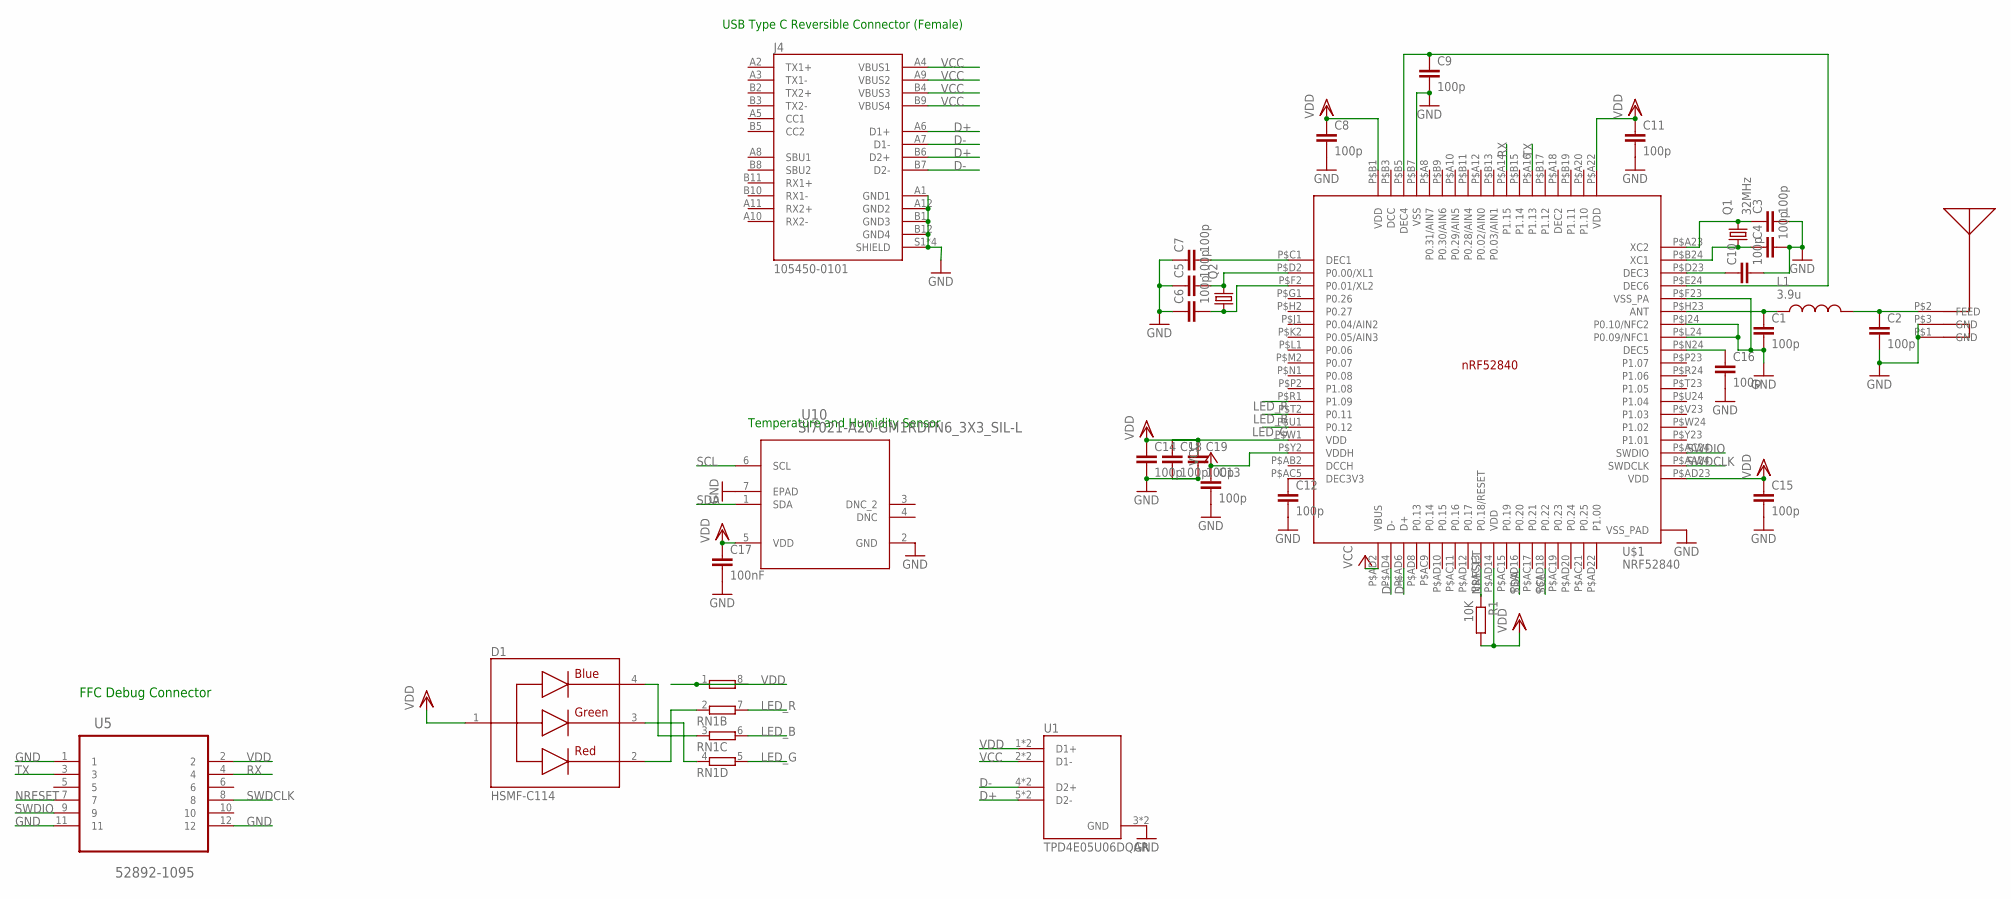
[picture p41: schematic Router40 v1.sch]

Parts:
C1, C2, C3, C4, C5, C6, C7, C8, C9, C10, C11, C12, C13, C14, C15, C16, C18, C19: 100p; C0402
C17: 100nF; C0402
D1: HSMF-C114; DIOSC160X150X35-4N
J4: 105450-0101; MOLEX_105450-0101
L1: 3.9u; INDC0402X26N
Q1: 32MHz; 2.0X1.6_KX-5
Q2: KX-327-RT; 2.0X1.2
R1: 10K; R0402
RN1: 4R-N0402ARV341; 4X0402ARV341
U1: TPD4E05U06DQAR; TI_TPD4E05U06DQAR
U5: 52892-1095; MOLEX_52892-1095
U10: SI7021-A20-GM1RDFN6_3X3_SIL-L; DFN6_3X3_SIL-L
U$1: NRF52840; AQFN50P700X700X85_HS-74N
U$4: CHIPANTENNAL2

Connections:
D+: J4.A6 (D1+), J4.B6 (D2+), U1.5 (D2-), U1.6 (D2-), U$1.P$AD6 (D+)
D-: J4.A7 (D1-), J4.B7 (D2-), U1.4 (D2+), U1.7 (D2+), U$1.P$AD4 (D-)
GND: C1.2, C2.2, C3.2, C4.2, C5.1, C6.1, C7.1, C8.2, C9.2, C10.2, C11.2, C12.2, C13.2, C14.2, C15.2, C16.2, C17.2, C18.2, C19.2, J4.A1 (GND1), J4.A12 (GND2), J4.B1 (GND3), J4.B12 (GND4), J4.S1 (SHIELD), J4.S2 (SHIELD), J4.S3 (SHIELD), J4.S4 (SHIELD), U1.3 (GND), U1.8 (GND), U5.1, U5.11, U5.12, U10.2 (GND), U10.7 (EPAD), U$1.P$74 (VSS_PAD), U$1.P$75 (VSS_PAD), U$1.P$76 (VSS_PAD), U$1.P$77 (VSS_PAD), U$1.P$78 (VSS_PAD), U$1.P$79 (VSS_PAD), U$1.P$80 (VSS_PAD), U$1.P$81 (VSS_PAD), U$1.P$82 (VSS_PAD), U$1.P$83 (VSS_PAD), U$1.P$84 (VSS_PAD), U$1.P$85 (VSS_PAD), U$1.P$86 (VSS_PAD), U$1.P$87 (VSS_PAD), U$1.P$88 (VSS_PAD), U$1.P$89 (VSS_PAD), U$1.P$90 (VSS_PAD), U$1.P$B7 (VSS), U$1.P$F23 (VSS_PA), U$1.P$J24 (P0.10/NFC2), U$1.P$L24 (P0.09/NFC1), U$4.P$1 (GND), U$4.P$3 (GND)
LED_B: RN1.6 (2), U$1.P$T2 (P0.11)
LED_G: RN1.5 (2), U$1.P$U1 (P0.12)
LED_R: RN1.7 (2), U$1.P$R1 (P1.09)
unnamed: C1.1, L1.1, U$1.P$H23 (ANT)
unnamed: C2.1, L1.2, U$4.P$2 (FEED)
unnamed: C3.1, Q1.3 (2), U$1.P$A23 (XC2)
unnamed: C4.1, Q1.1, U$1.P$B24 (XC1)
unnamed: C5.2, Q2.2, U$1.P$D2 (P0.00/XL1)
unnamed: C6.2, Q2.1, U$1.P$F2 (P0.01/XL2)
unnamed: C7.2, U$1.P$C1 (DEC1)
unnamed: C9.1, U$1.P$B5 (DEC4), U$1.P$E24 (DEC6)
unnamed: C10.1, U$1.P$D23 (DEC3)
unnamed: C12.1, U$1.P$AC5 (DEC3V3)
unnamed: C16.1, U$1.P$N24 (DEC5)
unnamed: D1.2, RN1.2 (1)
unnamed: D1.3, RN1.4 (1)
unnamed: D1.4, RN1.3 (1)
NRESET: R1.1, U5.7, U$1.P$AC13 (P0.18/RESET)
RX: U5.4, U$1.P$A14 (P1.15)
SCL: U10.6 (SCL), U$1.P$AD18 (P0.22)
SDA: U10.1 (SDA), U$1.P$AD16 (P0.20)
SWDCLK: U5.8, U$1.P$AA24 (SWDCLK)
SWDIO: U5.9, U$1.P$AC24 (SWDIO)
TX: U5.3, U$1.P$A16 (P1.13)
VCC: C13.1, J4.A4 (VBUS1), J4.A9 (VBUS2), J4.B4 (VBUS3), J4.B9 (VBUS4), U1.2 (D1-), U1.9 (D1-), U$1.P$AD2 (VBUS), U$1.P$Y2 (VDDH)
VDD: C8.1, C11.1, C14.1, C15.1, C17.1, C18.1, C19.1, D1.1, R1.2, RN1.1, RN1.8 (2), U1.1 (D1+), U1.10 (D1+), U5.2, U10.5 (VDD), U$1.P$A22 (VDD), U$1.P$AD14 (VDD), U$1.P$AD23 (VDD), U$1.P$B1 (VDD), U$1.P$W1 (VDD)

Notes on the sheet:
FFC Debug Connector
USB Type C Reversible Connector (Female)
Temperature and Humidity Sensor

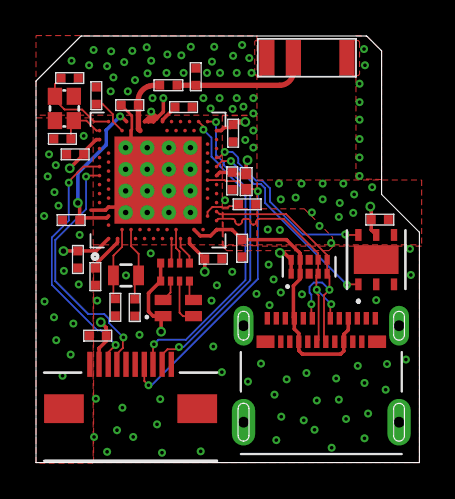
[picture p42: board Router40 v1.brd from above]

Board: 4 copper layers, 21.3 x 23.7 mm, 31 parts (0 on the bottom side), 29 nets.

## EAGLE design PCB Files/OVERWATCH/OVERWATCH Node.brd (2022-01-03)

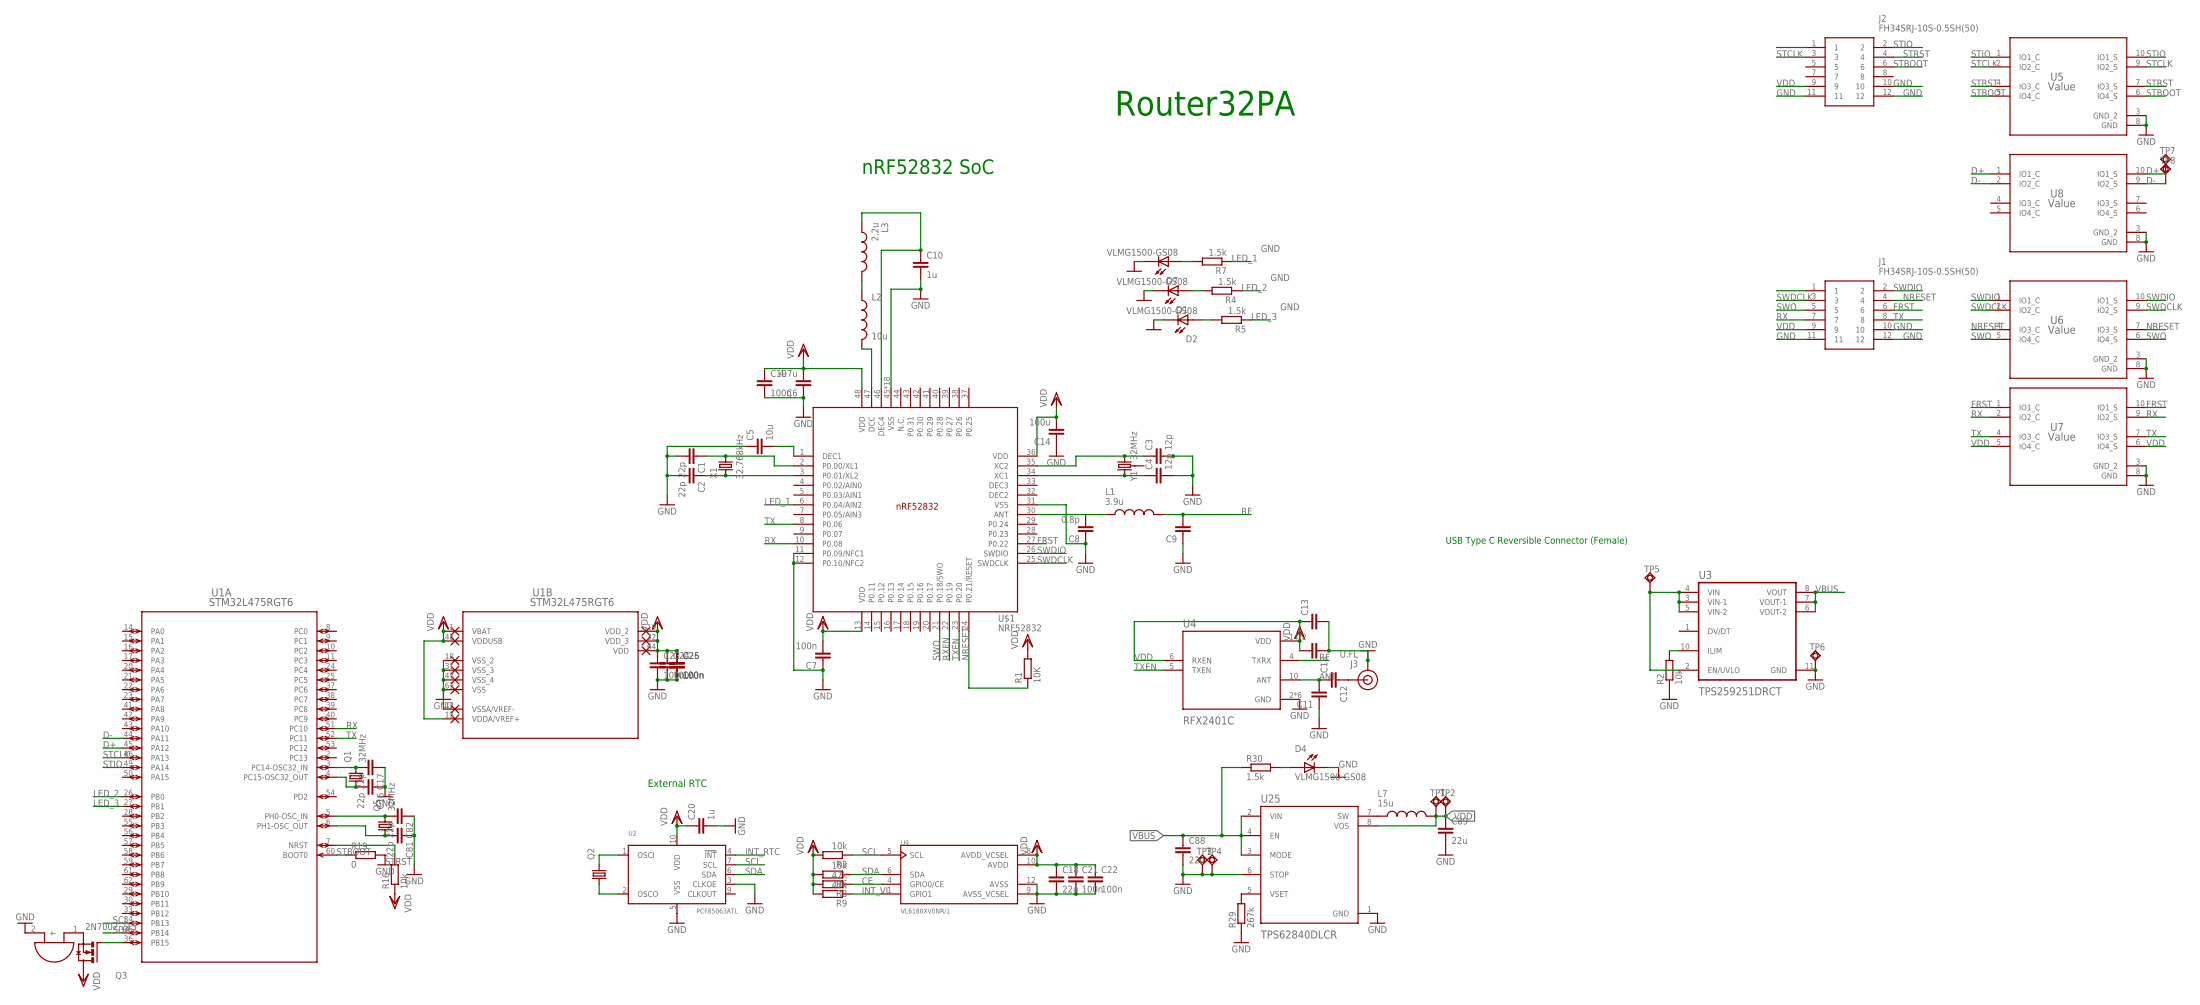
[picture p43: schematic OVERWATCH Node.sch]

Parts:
C1, C2, C16, C17, C81, C82: 22p; C0402
C3, C4: 12p; C0402
C5: 10u; C0402
C6: 4.7u; C0402
C7: 100n; C0603R
C8: 0.8p; C0402
C9, C11, C12, C13, C15: 1.2p; C0402
C10: 1u; C0402
C14: 100u; C0402
C18, C88, C89: 22u; C0603R
C19, C21, C22, C23, C24, C25, C26: 100n; C0402
C20: 1u; C0603R
D1, D2, D4, D7: VLMG1500-GS08; LEDC1005X35N
J1, J2: FH34SRJ-10S-0.5SH(50); FH34SRJ10S05SH50
J3: U.FL
L1: 3.9u; INDC0402X26N
L2: 10u; L0603
L3: 2.2u; INDC0402X26N
L7: 15u; INDC3225X120N
Q1, Q5: 32MHz; 2.0X1.6_KX-5
Q2: KX-327-RT; 2.0X1.2
Q3: 2N7002,215; SOT23-3
R1: 10K; R0402
R2, R3, R6, R16: 10k; R0402
R4, R5, R7, R30: 1.5k; R0402
R8, R9: 47k; R0402
R19: 0; R0402
R29: 267k; R0402
TP1, TP2, TP3, TP4, TP5, TP6, TP7, TP8: TESTPAD_TPSQTP20SQ; TESTPAD_TP20SQ
U1: STM32L475RGT6; LQFP64-10X10MM
U2: PCF85063ATL; SOT1197-1
U3: TPS259251DRCT; VREG_V62/16624-01YE
U4: RFX2401C; QFN50P300X300X60-17N
U5, U6, U7, U8: Value; DQA0010A
U9: VL6180XV0NR/1; LGA12R75P2X6_280X480X110
U25: TPS62840DLCR; SON50P200X150X100-8N
U$1: NRF52832; QFN40P600X600X90-48_N
U$2: SMD_BUZZER
X1: 32.768kHz; ABS07-32.768KHZ-T
Y1: 32MHz; CRYSTAL-SMD-3.2X2.5MM

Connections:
ANT: C11.2, C12.2, U4.10 (ANT)
CE: R8.1, U9.4 (GPIO0/CE)
D+: TP7.TP, U1.45 (PA12), U8.1 (IO1_C), U8.10 (IO1_S)
D-: TP8.TP, U1.44 (PA11), U8.2 (IO2_C), U8.9 (IO2_S)
FRST: J1.6, U7.1 (IO1_C), U7.10 (IO1_S), U$1.27 (P0.22)
GND: C1.2, C2.2, C3.2, C4.2, C5.1, C6.1, C7.1, C8.1, C9.1, C10.2, C11.1, C13.2, C14.1, C15.1, C16.1, C17.1, C18.2, C19.2, C20.2, C21.2, C22.2, C23.2, C24.2, C25.2, C26.2, C81.1, C82.1, C88.2, C89.2, D1.2, D2.2, D4.2, D7.2, J1.10, J1.11, J1.12, J2.10, J2.11, J2.12, J3.1 (GND), J3.2 (GND), R2.1, R19.2, R29.1, TP3.TP, TP4.TP, TP6.TP, U1.12 (VSSA/VREF-), U1.18 (VSS_2), U1.31 (VSS_3), U1.47 (VSS_4), U1.63 (VSS), U2.3 (CLKOE), U2.5 (VSS), U3.11 (GND), U4.2 (GND), U4.3 (GND), U4.8 (GND), U4.9 (GND), U4.11 (GND), U4.17 (GND), U5.3 (GND_2), U5.8 (GND), U6.3 (GND_2), U6.8 (GND), U7.3 (GND_2), U7.8 (GND), U8.3 (GND_2), U8.8 (GND), U9.9 (AVSS_VCSEL), U9.12 (AVSS), U25.1 (GND), U25.6 (STOP), U$1.11 (P0.09/NFC1), U$1.12 (P0.10/NFC2), U$1.31 (VSS), U$1.45 (VSS), U$1.PAD (VSS), U$1.PAD@VIA01 (VSS), U$1.PAD@VIA02 (VSS), U$1.PAD@VIA03 (VSS), U$1.PAD@VIA04 (VSS), U$1.PAD@VIA05 (VSS), U$1.PAD@VIA06 (VSS), U$1.PAD@VIA07 (VSS), U$1.PAD@VIA08 (VSS), U$1.PAD@VIA09 (VSS), U$1.PAD@VIA10 (VSS), U$1.PAD@VIA11 (VSS), U$1.PAD@VIA12 (VSS), U$1.PAD@VIA13 (VSS), U$1.PAD@VIA14 (VSS), U$1.PAD@VIA15 (VSS), U$1.PAD@VIA16 (VSS), U$2.2 (-)
INT_RTC: U2.4 (!INT!)
INT_VL: R9.1, U9.1 (GPIO1)
LED_1: R7.1, U$1.6 (P0.04/AIN2)
LED_2: R4.1, U1.26 (PB0)
LED_3: R5.1, U1.27 (PB1)
unnamed: C1.1, U$1.2 (P0.00/XL1), X1.2
unnamed: C2.1, U$1.3 (P0.01/XL2), X1.1
unnamed: C3.1, U$1.35 (XC2), Y1.3 (2)
unnamed: C4.1, U$1.34 (XC1), Y1.1
unnamed: C5.2, U$1.1 (DEC1)
unnamed: C8.2, L1.1, U$1.30 (ANT)
unnamed: D1.1, R4.2
unnamed: D2.1, R5.2
unnamed: L2.2, U$1.47 (DCC)
unnamed: L2.1, L3.2
unnamed: C10.1, L3.1, U$1.46 (DEC4)
unnamed: Q3.2 (S), U$2.1 (+)
unnamed: C16.2, Q1.1, U1.4 (PC15-OSC32_OUT)
unnamed: C12.1, J3.FEED (SIGNAL)
unnamed: C17.2, Q1.3 (2), U1.3 (PC14-OSC32_IN)
unnamed: Q2.2, U2.1 (OSCI)
unnamed: Q2.1, U2.2 (OSCO)
unnamed: D7.1, R7.2
unnamed: R2.2, U3.10 (ILIM)
unnamed: TP5.TP, U3.2 (EN/UVLO), U3.3 (VIN-1), U3.4 (VIN), U3.5 (VIN-2)
unnamed: Q3.1 (G), U1.36 (PB15)
unnamed: C81.2, Q5.1, U1.6 (PH1-OSC_OUT)
unnamed: C82.2, Q5.3 (2), U1.5 (PH0-OSC_IN)
unnamed: L7.1, U25.7 (SW)
unnamed: R29.2, U25.5 (VSET)
unnamed: D4.1, R30.2
NRESET: J1.4, R1.1, U6.4 (IO3_C), U6.7 (IO3_S), U$1.24 (P0.21/RESET)
RF: C9.2, L1.2, U4.4 (TXRX)
RX: J1.7, U1.51 (PC10), U7.2 (IO2_C), U7.9 (IO2_S), U$1.10 (P0.08)
RXEN: U$1.22 (P0.19)
SCL: R3.1, U1.34 (PB13), U2.7 (SCL), U9.5 (SCL)
SDA: R6.1, U1.35 (PB14), U2.6 (SDA), U9.6 (SDA)
STBOOT: J2.6, R19.1, U1.60 (BOOT0), U5.5 (IO4_C), U5.6 (IO4_S)
STCLK: J2.3, U1.46 (PA13), U5.2 (IO2_C), U5.9 (IO2_S)
STIO: J2.2, U1.49 (PA14), U5.1 (IO1_C), U5.10 (IO1_S)
STRST: J2.4, R16.2, U1.7 (NRST), U5.4 (IO3_C), U5.7 (IO3_S)
SWDCLK: J1.3, U6.2 (IO2_C), U6.9 (IO2_S), U$1.25 (SWDCLK)
SWDIO: J1.2, U6.1 (IO1_C), U6.10 (IO1_S), U$1.26 (SWDIO)
SWO: J1.5, U6.5 (IO4_C), U6.6 (IO4_S), U$1.21 (P0.18/SWO)
TX: J1.8, U1.52 (PC11), U7.4 (IO3_C), U7.7 (IO3_S), U$1.8 (P0.06)
TXEN: U4.5 (TXEN), U$1.23 (P0.20)
VBUS: C88.1, R30.1, U3.6 (VOUT-2), U3.7 (VOUT-1), U3.8 (VOUT), U25.2 (VIN), U25.3 (MODE), U25.4 (EN)
VDD: C6.2, C7.2, C13.1, C14.2, C15.2, C18.1, C19.1, C20.1, C21.1, C22.1, C23.1, C24.1, C25.1, C26.1, C89.1, J1.9, J2.9, L7.2, Q3.3 (D), R1.2, R3.2, R6.2, R8.2, R9.2, R16.1, TP1.TP, TP2.TP, U1.1 (VBAT), U1.13 (VDDA/VREF+), U1.19 (VDD_2), U1.32 (VDD_3), U1.48 (VDDUSB), U1.64 (VDD), U2.10 (VDD), U4.6 (RXEN), U4.14 (VDD), U4.16 (VDD), U7.5 (IO4_C), U7.6 (IO4_S), U9.8 (AVDD_VCSEL), U9.10 (AVDD), U25.8 (VOS), U$1.13 (VDD), U$1.36 (VDD), U$1.48 (VDD)

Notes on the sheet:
nRF52832 SoC
Router32PA
USB Type C Reversible Connector (Female)
External RTC

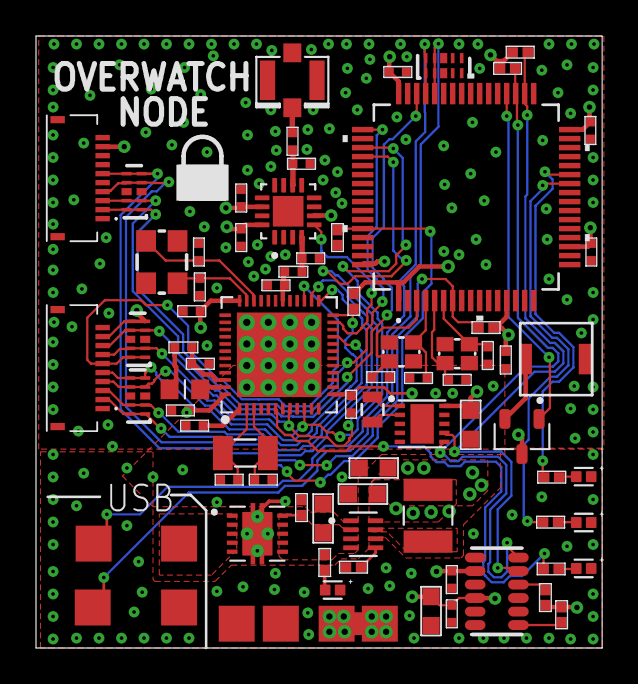
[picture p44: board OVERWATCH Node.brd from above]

Board: 4 copper layers, 31.4 x 34.0 mm, 80 parts (0 on the bottom side), 52 nets.

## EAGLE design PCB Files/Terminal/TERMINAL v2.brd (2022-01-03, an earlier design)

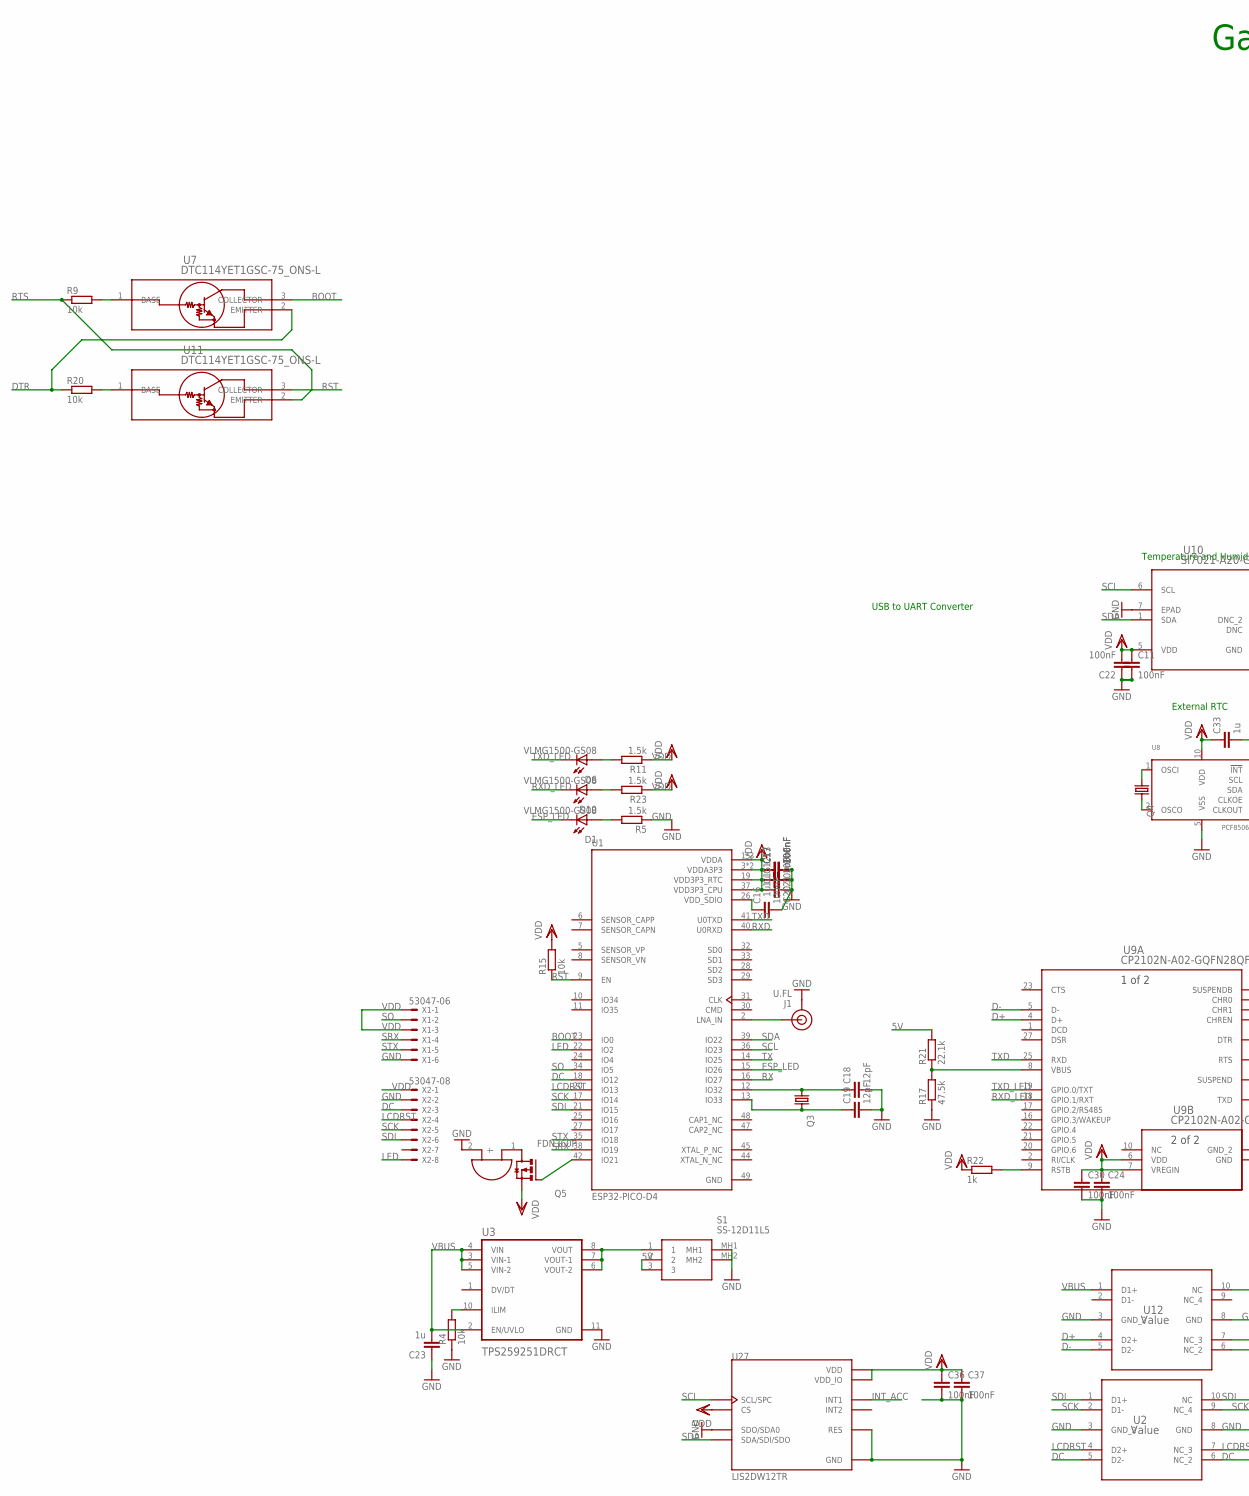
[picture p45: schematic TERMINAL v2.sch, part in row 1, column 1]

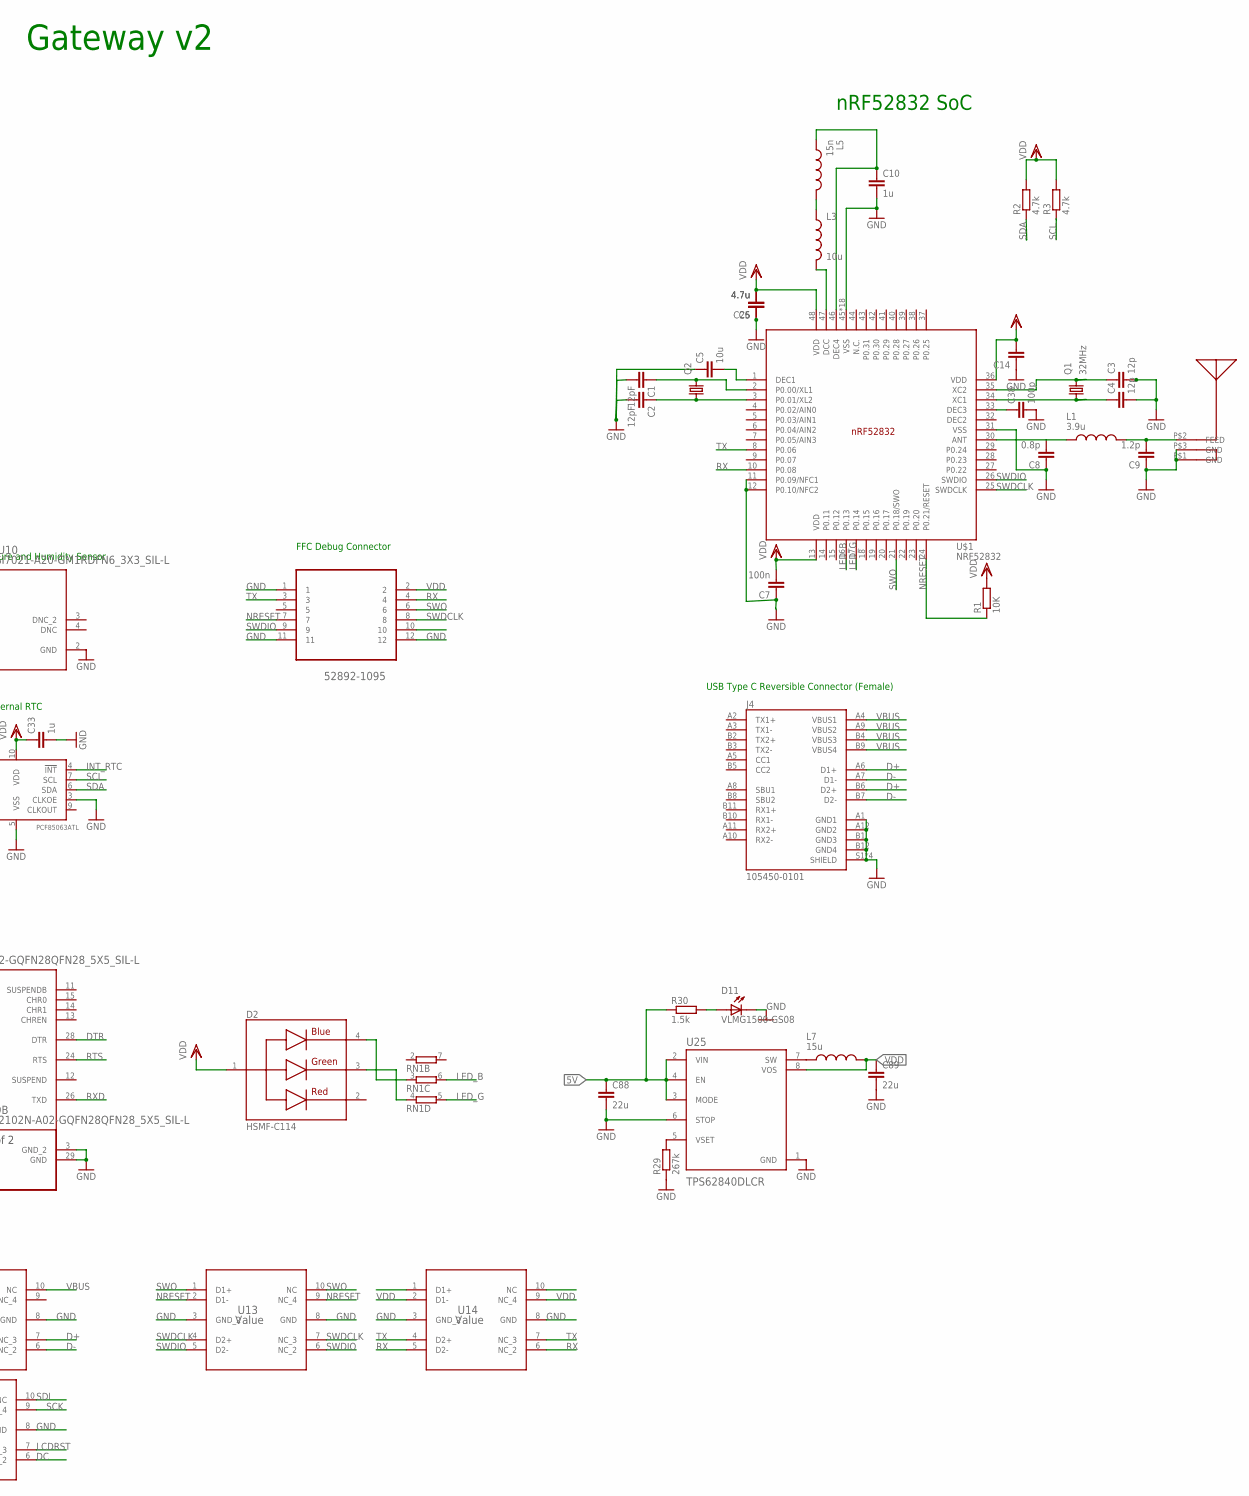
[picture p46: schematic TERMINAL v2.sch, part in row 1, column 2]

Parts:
C1, C2, C18, C19: 12pF; C0402
C3, C4: 12p; C0402
C5: 10u; C0402
C6, C25: 4.7u; C0402
C7: 100n; C0402
C8: 0.8p; C0402
C9: 1.2p; C0402
C10: 1u; C0402
C11, C12, C13, C15, C16, C17, C22, C24, C30, C36, C37: 100nF; C0402
C14: 100u; C0402
C20, C21, C23, C33: 1u; C0603R
C38: 100p; C0402
C88, C89: 22u; C0603R
D1, D6, D10, D11: VLMG1500-GS08; LEDC1005X35N
D2: HSMF-C114; DIOSC160X150X35-4N
J1: U.FL
J4: 105450-0101; MOLEX_105450-0101
L1: 3.9u; INDC0402X26N
L3: 10u; L0603
L5: 15n; INDC0402X26N
L7: 15u; INDC3225X120N
Q1: 32MHz; 2.0X1.6_KX-5
Q2, Q3, Q4: KX-327-RT; 2.0X1.2
Q5: FDN360P; SUPER-SOT3
R1: 10K; R0402
R2, R3: 4.7k; R0402
R4, R9, R15, R20: 10k; R0402
R5, R11, R23, R30: 1.5k; R0402
R17: 47.5k; R0402
R21: 22.1k; R0402
R22: 1k; R0402
R29: 267k; R0402
RN1: 4R-N0402ARV341; 4X0402ARV341
S1: SS-12D11L5; SS12D11L5
U1: ESP32-PICO-D4; PQFN50P700X700X104-49N
U2, U12, U13, U14: Value; DQA0010A
U3: TPS259251DRCT; VREG_V62/16624-01YE
U5: 52892-1095; MOLEX_52892-1095
U7, U11: DTC114YET1GSC-75_ONS-L; SC-75_ONS-L
U8: PCF85063ATL; SOT1197-1
U9: CP2102N-A02-GQFN28QFN28_5X5_SIL-L; QFN28_5X5_SIL-L
U10: SI7021-A20-GM1RDFN6_3X3_SIL-L; DFN6_3X3_SIL-L
U25: TPS62840DLCR; SON50P200X150X100-8N
U27: LIS2DW12TR; LGA12R50P4X4_200X200X70
U$1: NRF52832; QFN40P600X600X90-48_N
U$2: SMD_BUZZER
U$4: CHIPANTENNAL2
X1: 53047-06
X2: 53047-08

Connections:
5V: C88.1, R21.2, R30.1, S1.2, S1.3, U25.2 (VIN), U25.3 (MODE), U25.4 (EN)
BOOT: U1.23 (IO0), U7.3 (COLLECTOR)
D+: J4.A6 (D1+), J4.B6 (D2+), U9.4 (D+), U12.4 (D2+), U12.7 (NC_3)
D-: J4.A7 (D1-), J4.B7 (D2-), U9.5 (D-), U12.5 (D2-), U12.6 (NC_2)
DC: U1.18 (IO12), U2.5 (D2-), U2.6 (NC_2), X2.3
DTR: R20.1, U7.2 (EMITTER), U9.28 (DTR)
ESP_LED: D1.2, U1.15 (IO26)
GND: C1.2, C2.2, C3.2, C4.2, C5.1, C6.1, C7.1, C8.1, C9.1, C10.2, C11.2, C12.2, C13.2, C14.1, C15.2, C16.2, C17.2, C18.2, C19.2, C20.1, C21.1, C22.1, C23.1, C24.2, C25.1, C30.2, C33.2, C36.2, C37.2, C38.2, C88.2, C89.2, D11.2, J1.1 (GND), J1.2 (GND), J4.A1 (GND1), J4.A12 (GND2), J4.B1 (GND3), J4.B12 (GND4), J4.S1 (SHIELD), J4.S2 (SHIELD), J4.S3 (SHIELD), J4.S4 (SHIELD), R4.1, R5.1, R17.1, R29.1, S1.MH1, S1.MH2, U1.49 (GND), U2.3 (GND_2), U2.8 (GND), U3.11 (GND), U5.1, U5.11, U5.12, U8.3 (CLKOE), U8.5 (VSS), U9.3 (GND_2), U9.29 (GND), U10.2 (GND), U10.7 (EPAD), U12.3 (GND_2), U12.8 (GND), U13.3 (GND_2), U13.8 (GND), U14.3 (GND_2), U14.8 (GND), U25.1 (GND), U25.6 (STOP), U27.3 (SDO/SDA0), U27.6 (GND), U27.7 (RES), U27.8 (GND), U$1.11 (P0.09/NFC1), U$1.12 (P0.10/NFC2), U$1.31 (VSS), U$1.45 (VSS), U$1.PAD (VSS), U$1.PAD@VIA01 (VSS), U$1.PAD@VIA02 (VSS), U$1.PAD@VIA03 (VSS), U$1.PAD@VIA04 (VSS), U$1.PAD@VIA05 (VSS), U$1.PAD@VIA06 (VSS), U$1.PAD@VIA07 (VSS), U$1.PAD@VIA08 (VSS), U$1.PAD@VIA09 (VSS), U$1.PAD@VIA10 (VSS), U$1.PAD@VIA11 (VSS), U$1.PAD@VIA12 (VSS), U$1.PAD@VIA13 (VSS), U$1.PAD@VIA14 (VSS), U$1.PAD@VIA15 (VSS), U$1.PAD@VIA16 (VSS), U$2.2 (-), U$4.P$1 (GND), U$4.P$3 (GND), X1.6, X2.2
INT_ACC: U27.12 (INT1)
INT_RTC: U8.4 (!INT!)
LCDRST: U1.20 (IO13), U2.4 (D2+), U2.7 (NC_3), X2.4
LED: U1.22 (IO2), X2.8
LED_B: RN1.6 (2), U$1.16 (P0.13)
LED_G: RN1.5 (2), U$1.17 (P0.14)
unnamed: C1.1, Q2.2, U$1.2 (P0.00/XL1)
unnamed: C2.1, Q2.1, U$1.3 (P0.01/XL2)
unnamed: C3.1, Q1.3 (2), U$1.35 (XC2)
unnamed: C4.1, Q1.1, U$1.34 (XC1)
unnamed: C5.2, U$1.1 (DEC1)
unnamed: C8.2, L1.1, U$1.30 (ANT)
unnamed: J1.FEED (SIGNAL), U1.2 (LNA_IN)
unnamed: C16.1, U1.26 (VDD_SDIO)
unnamed: L3.2, U$1.47 (DCC)
unnamed: L3.1, L5.2
unnamed: C10.1, L5.1, U$1.46 (DEC4)
unnamed: C19.1, Q3.2, U1.13 (IO33)
unnamed: C18.1, Q3.1, U1.12 (IO32)
unnamed: Q5.3 (D), U$2.1 (+)
unnamed: C38.1, U$1.33 (DEC3)
unnamed: Q5.1 (G), U1.42 (IO21)
unnamed: S1.1, U3.6 (VOUT-2), U3.7 (VOUT-1), U3.8 (VOUT)
unnamed: D1.1, R5.2
unnamed: R4.2, U3.10 (ILIM)
unnamed: D2.3, RN1.4 (1)
unnamed: R17.2, R21.1, U9.8 (VBUS)
unnamed: D2.4, RN1.3 (1)
unnamed: R20.2, U11.1 (BASE)
unnamed: R9.2, U7.1 (BASE)
unnamed: Q4.1, U8.1 (OSCI)
unnamed: Q4.2, U8.2 (OSCO)
unnamed: R22.2, U9.9 (RSTB)
unnamed: D6.1, R11.2
unnamed: D10.1, R23.2
unnamed: L7.1, U25.7 (SW)
unnamed: R29.2, U25.5 (VSET)
unnamed: D11.1, R30.2
NRESET: R1.1, U5.7, U13.2 (D1-), U13.9 (NC_4), U$1.24 (P0.21/RESET)
RFP1: C9.2, L1.2, U$4.P$2 (FEED)
RST: R15.1, U1.9 (EN), U11.3 (COLLECTOR)
RTS: R9.1, U9.24 (RTS), U11.2 (EMITTER)
RX: U1.16 (IO27), U5.4, U14.5 (D2-), U14.6 (NC_2), U$1.10 (P0.08)
RXD: U1.40 (U0RXD), U9.26 (TXD)
RXD_LED: D10.2, U9.18 (GPIO.1/RXT)
SCK: U1.17 (IO14), U2.2 (D1-), U2.9 (NC_4), X2.5
SCL: R3.1, U1.36 (IO23), U8.7 (SCL), U10.6 (SCL), U27.1 (SCL/SPC)
SDA: R2.1, U1.39 (IO22), U8.6 (SDA), U10.1 (SDA), U27.4 (SDA/SDI/SDO)
SDI: U1.21 (IO15), U2.1 (D1+), U2.10 (NC), X2.6
SO: U1.34 (IO5), X1.2
SRX: U1.38 (IO19), X1.4
STX: U1.35 (IO18), X1.5
SWDCLK: U5.8, U13.4 (D2+), U13.7 (NC_3), U$1.25 (SWDCLK)
SWDCLK1: U14.1 (D1+)
SWDIO: U5.9, U13.5 (D2-), U13.6 (NC_2), U$1.26 (SWDIO)
SWO: U5.6, U13.1 (D1+), U13.10 (NC), U$1.21 (P0.18/SWO)
TX: U1.14 (IO25), U5.3, U14.4 (D2+), U14.7 (NC_3), U$1.8 (P0.06)
TXD: U1.41 (U0TXD), U9.25 (RXD)
TXD_LED: D6.2, U9.19 (GPIO.0/TXT)
VBUS: C23.2, J4.A4 (VBUS1), J4.A9 (VBUS2), J4.B4 (VBUS3), J4.B9 (VBUS4), U3.2 (EN/UVLO), U3.3 (VIN-1), U3.4 (VIN), U3.5 (VIN-2), U12.1 (D1+), U12.10 (NC)
VDD: C6.2, C7.2, C11.1, C12.1, C13.1, C14.2, C15.1, C17.1, C20.2, C21.2, C22.2, C24.1, C25.2, C30.1, C33.1, C36.1, C37.1, C89.1, D2.1, L7.2, Q5.2 (S), R1.2, R2.2, R3.2, R11.1, R15.2, R22.1, R23.1, U1.1 (VDDA), U1.3 (VDDA3P3), U1.4 (VDDA3P3), U1.19 (VDD3P3_RTC), U1.37 (VDD3P3_CPU), U1.43 (VDDA), U1.46 (VDDA), U5.2, U8.10 (VDD), U9.6 (VDD), U9.7 (VREGIN), U10.5 (VDD), U14.2 (D1-), U14.9 (NC_4), U25.8 (VOS), U27.2 (CS), U27.9 (VDD), U27.10 (VDD_IO), U$1.13 (VDD), U$1.36 (VDD), U$1.48 (VDD), X1.1, X1.3, X2.1

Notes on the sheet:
USB to UART Converter
External RTC
Temperature and Humidity Sensor
FFC Debug Connector
USB Type C Reversible Connector (Female)
nRF52832 SoC
Gateway v2

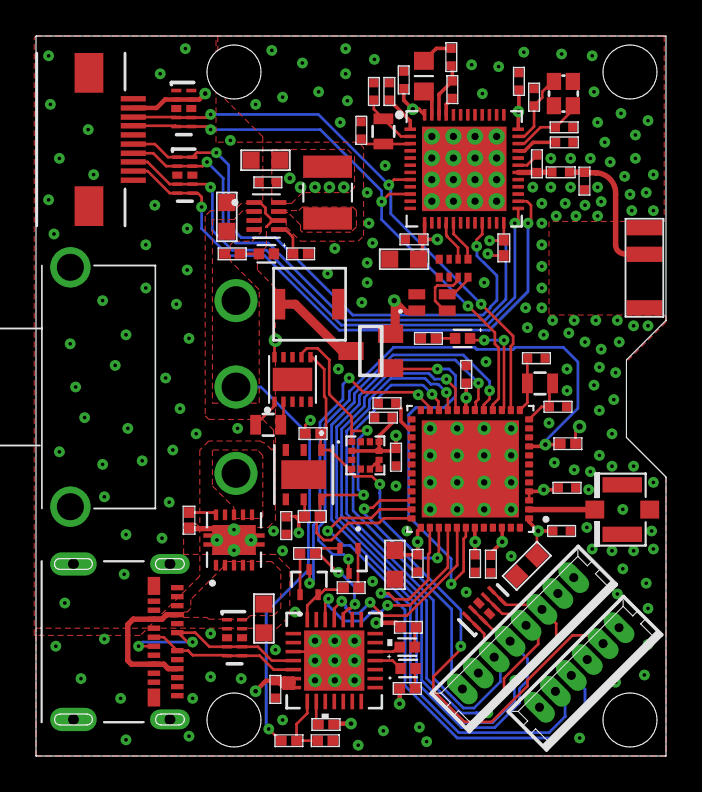
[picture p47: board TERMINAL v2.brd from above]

Board: 4 copper layers, 35.0 x 40.0 mm, 84 parts (0 on the bottom side), 66 nets.

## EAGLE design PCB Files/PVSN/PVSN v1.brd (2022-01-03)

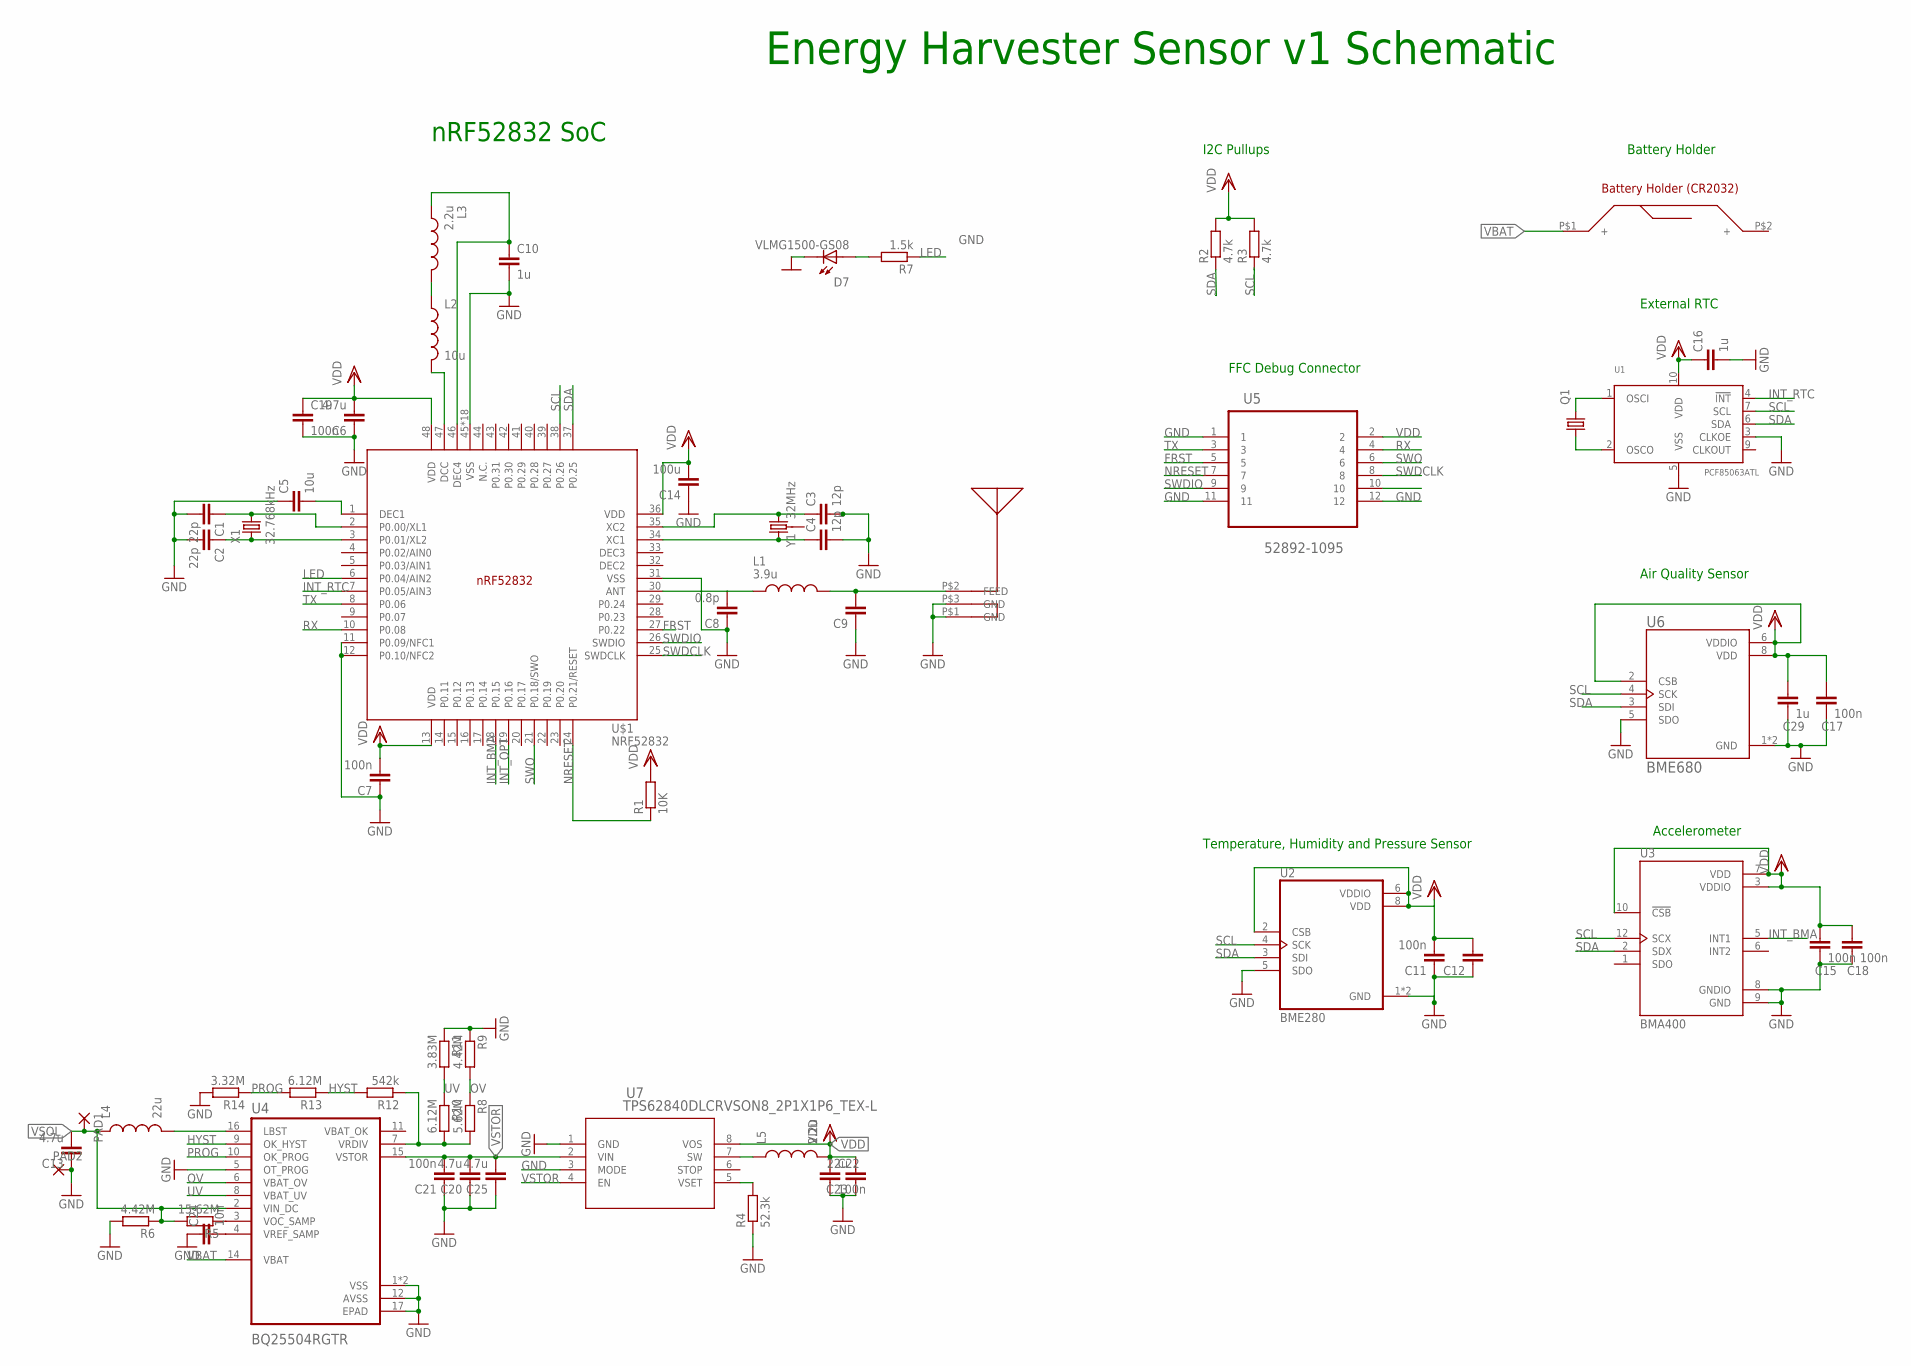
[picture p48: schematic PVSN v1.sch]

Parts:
C1, C2: 22p; C0402
C3, C4: 12p; C0402
C5: 10u; C0402
C6, C20, C25: 4.7u; C0402
C7: 100n; C0603R
C8: 0.8p; C0402
C9: 1.2p; C0402
C10, C12, C29: 1u; C0402
C11, C15, C17, C18, C19, C21, C22: 100n; C0402
C13: 4.7u; C0603R
C14: 100u; C0402
C16: 1u; C0603R
C23: 22u; C0603R
C24: 10n; C0402
D7: VLMG1500-GS08; LEDC1005X35N
L1: 3.9u; INDC0402X26N
L2: 10u; L0603
L3: 2.2u; INDC0402X26N
L4: 22u; L0603
L5: 2.2u; L0603
PAD1, PAD2: SMD2; SMD1,27-2,54
Q1: KX-327-RT; 2.0X1.2
R1: 10K; R0402
R2, R3: 4.7k; R0402
R4: 52.3k; R0402
R5: 15.62M; R0402
R6, R9: 4.42M; R0402
R7: 1.5k; R0402
R8: 5.62M; R0402
R10, R13: 6.12M; R0402
R11: 3.83M; R0402
R12: 542k; R0402
R14: 3.32M; R0402
U1: PCF85063ATL; SOT1197-1
U2: BME280; PSON65P250X250X100-8N
U3: BMA400; XDCR_BMA400
U4: BQ25504RGTR; QFN50P300X300X100-17N
U5: 52892-1095; MOLEX_52892-1095
U6: BME680; PSON80P300X300X100-8N
U7: TPS62840DLCRVSON8_2P1X1P6_TEX-L; VSON8_2P1X1P6_TEX-L
U$1: NRF52832; QFN40P600X600X90-48_N
U$2: HOLDER
U$4: CHIPANTENNAL2
X1: 32.768kHz; ABS07-32.768KHZ-T
Y1: 32MHz; CRYSTAL-SMD-3.2X2.5MM

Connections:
FRST: U5.5, U$1.27 (P0.22)
GND: C1.2, C2.2, C3.2, C4.2, C5.1, C6.1, C7.1, C8.1, C9.1, C10.2, C11.1, C12.1, C13.1, C14.1, C15.2, C16.2, C17.2, C18.2, C19.2, C20.1, C21.1, C22.2, C23.1, C24.1, C25.1, C29.2, D7.2, PAD2.1, R4.1, R6.2, R9.1, R11.1, R14.2, U1.3 (CLKOE), U1.5 (VSS), U2.1 (GND), U2.5 (SDO), U2.7 (GND), U3.8 (GNDIO), U3.9 (GND), U4.1 (VSS), U4.5 (OT_PROG), U4.12 (AVSS), U4.13 (VSS), U4.17 (EPAD), U5.1, U5.11, U5.12, U6.1 (GND), U6.5 (SDO), U6.7 (GND), U7.1 (GND), U7.3 (MODE), U$1.11 (P0.09/NFC1), U$1.12 (P0.10/NFC2), U$1.31 (VSS), U$1.45 (VSS), U$1.PAD (VSS), U$1.PAD@VIA01 (VSS), U$1.PAD@VIA02 (VSS), U$1.PAD@VIA03 (VSS), U$1.PAD@VIA04 (VSS), U$1.PAD@VIA05 (VSS), U$1.PAD@VIA06 (VSS), U$1.PAD@VIA07 (VSS), U$1.PAD@VIA08 (VSS), U$1.PAD@VIA09 (VSS), U$1.PAD@VIA10 (VSS), U$1.PAD@VIA11 (VSS), U$1.PAD@VIA12 (VSS), U$1.PAD@VIA13 (VSS), U$1.PAD@VIA14 (VSS), U$1.PAD@VIA15 (VSS), U$1.PAD@VIA16 (VSS), U$4.P$1 (GND), U$4.P$3 (GND)
HYST: R12.2, R13.1, U4.9 (OK_HYST)
INT_BMA: U3.5 (INT1), U$1.18 (P0.15)
INT_OPT: U$1.19 (P0.16)
INT_RTC: U1.4 (!INT!), U$1.7 (P0.05/AIN3)
LED: R7.1, U$1.6 (P0.04/AIN2)
unnamed: C1.1, U$1.2 (P0.00/XL1), X1.2
unnamed: C2.1, U$1.3 (P0.01/XL2), X1.1
unnamed: C3.1, U$1.35 (XC2), Y1.3 (2)
unnamed: C4.1, U$1.34 (XC1), Y1.1
unnamed: C5.2, U$1.1 (DEC1)
unnamed: C8.2, L1.1, U$1.30 (ANT)
unnamed: Q1.2, U1.1 (OSCI)
unnamed: Q1.1, U1.2 (OSCO)
unnamed: L2.2, U$1.47 (DCC)
unnamed: L2.1, L3.2
unnamed: C10.1, L3.1, U$1.46 (DEC4)
unnamed: L4.2, U4.16 (LBST)
unnamed: R8.2, R10.2, R12.1, U4.7 (VRDIV)
unnamed: L5.1, U7.7 (SW)
unnamed: R4.2, U7.5 (VSET)
unnamed: C24.2, U4.4 (VREF_SAMP)
unnamed: D7.1, R7.2
unnamed: R5.1, U4.3 (VOC_SAMP)
NRESET: R1.1, U5.7, U$1.24 (P0.21/RESET)
OV: R8.1, R9.2, U4.6 (VBAT_OV)
PROG: R13.2, R14.1, U4.10 (OK_PROG)
RF: C9.2, L1.2, U$4.P$2 (FEED)
RX: U5.4, U$1.10 (P0.08)
SCL: R3.1, U1.7 (SCL), U2.4 (SCK), U3.12 (SCX), U6.4 (SCK), U$1.38 (P0.26)
SDA: R2.1, U1.6 (SDA), U2.3 (SDI), U3.2 (SDX), U6.3 (SDI), U$1.37 (P0.25)
SWDCLK: U5.8, U$1.25 (SWDCLK)
SWDIO: U5.9, U$1.26 (SWDIO)
SWO: U5.6, U$1.21 (P0.18/SWO)
TX: U5.3, U$1.8 (P0.06)
UV: R10.1, R11.2, U4.8 (VBAT_UV)
VBAT: U4.14 (VBAT), U$2.P$1
VDD: C6.2, C7.2, C11.2, C12.2, C14.2, C15.1, C16.1, C17.1, C18.1, C19.1, C22.1, C23.2, C29.1, L5.2, R1.2, R2.2, R3.2, U1.10 (VDD), U2.2 (CSB), U2.6 (VDDIO), U2.8 (VDD), U3.3 (VDDIO), U3.7 (VDD), U3.10 (!CSB), U5.2, U6.2 (CSB), U6.6 (VDDIO), U6.8 (VDD), U7.8 (VOS), U$1.13 (VDD), U$1.36 (VDD), U$1.48 (VDD)
VSOL: C13.2, L4.1, PAD1.1, R5.2, R6.1, U4.2 (VIN_DC)
VSTOR: C20.2, C21.2, C25.2, U4.15 (VSTOR), U7.2 (VIN), U7.4 (EN)

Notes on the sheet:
nRF52832 SoC
I2C Pullups
Battery Holder
FFC Debug Connector
External RTC
Air Quality Sensor
Temperature, Humidity and Pressure Sensor
Accelerometer
Energy Harvester Sensor v1 Schematic


Board: 4 copper layers, 23.4 x 23.0 mm, 61 parts (1 on the bottom side), 40 nets.

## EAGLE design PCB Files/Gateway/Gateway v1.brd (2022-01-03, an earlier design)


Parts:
C1, C2: 12pF; C0402
C3, C4: 12p; C0402
C5: 10u; C0402
C6: 4.7u; C0402
C7: 100n; C0402
C8: 0.8p; C0402
C9: 1.2p; C0402
C10, C11, C21: 1u; C0402
C12, C13, C15, C16: 22p; C0402
C14: 100u; C0402
C17: 10n; C0402
C18: 3.3n; C0402
C19: 3.9p; C0402
C20: 2.4p; C0402
C22, C23, C24, C33, C39: 1u; C0603R
C25, C26, C27, C28, C29, C30: 100nF; C0402
D1, D2, D3, D4, D5, D7, D8, D9: VLMG1500-GS08; LEDC1005X35N
J1, J3: U.FL
J4: 105450-0101; MOLEX_105450-0101
L1: 3.9u; INDC0402X26N
L2: 2.7n; INDC0402X26N
L4: 10u; INDC0402X26N
L5: 15n; INDC0402X26N
R1: 10K; R0402
R2, R3: 4.7k; R0402
R4: 20k; R0402
R5, R6, R7, R8, R10, R12, R13, R18: 1.5k; R0402
R9, R11, R15, R19, R20: 10k; R0402
RESET: SMDSWITCH; RESC4217X170
S1: SS-12D11L5; SS12D11L5
T1, T2, T3: -NPN-SOT23-BEC; SOT23-BEC
U1: ESP32; QFN48-0.4MM
U2: CP2102; QFN50P500X500X100-29N
U3: SHT20; DFN300X300X110-7N
U4: W25Q32FVSSIQ; SOIC127P790X216-8N
U5: 52892-1095; MOLEX_52892-1095
U6: 3.3V; SOT23-5
U7: PCF85063ATL; SOT1197-1
U$1: NRF52832; QFN40P600X600X90-48_N
U$2: ADAFRUIT_JD-T1800
X1, X2, X4: ABS07-32.768KHZ-T
Y1, Y2: CRYSTAL-26MHZSMD-3.2X2.5; CRYSTAL-SMD-3.2X2.5MM

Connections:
5VUSB: C30.1, C39.2, J4.A4 (VBUS1), J4.A9 (VBUS2), J4.B4 (VBUS3), J4.B9 (VBUS4), U2.7 (REGIN), U2.8 (VBUS), U6.1 (IN), U6.3 (EN)
BLK: R11.2, U1.24 ((ADC2:0/TOUCH0/RTC10/SPIHD)GPIO4)
BOOT: T1.C, U1.23 ((ADC2:1/TOUCH1/RTC11/CLK_OUT1)GPIO0)
CLK: U1.17 ((GPIO14/ADC2:6/TOUCH6/RTC16/SPICLK)MTMS), U$2.9 (CLOCK)
CS: U1.21 ((GPIO15/ADC2:3/TOUCH3/RTC13/SPICSO/U0RT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), U$2.12 (CS)
D+: J4.A6 (D1+), J4.B6 (D2+), U2.4 (D+)
D-: J4.A7 (D1-), J4.B7 (D2-), U2.5 (D-)
DTR: R20.1, T1.E, U2.28 (DTR)
GND: C1.2, C2.2, C3.2, C4.2, C5.1, C6.1, C7.1, C8.1, C9.1, C10.2, C11.2, C12.2, C13.2, C14.1, C15.2, C16.2, C17.1, C20.1, C21.2, C22.1, C23.1, C24.1, C25.2, C26.2, C27.2, C28.2, C29.2, C30.2, C33.2, C39.1, D1.2, D2.2, D3.2, D4.2, D5.2, D7.2, D8.2, D9.2, J1.1 (GND), J1.2 (GND), J3.1 (GND), J3.2 (GND), J4.A1 (GND1), J4.A12 (GND2), J4.B1 (GND3), J4.B12 (GND4), J4.S1 (SHIELD), J4.S2 (SHIELD), J4.S3 (SHIELD), J4.S4 (SHIELD), L2.2, RESET.1, S1.MH1, S1.MH2, T3.E, U1.EP (GND), U2.3 (GND), U2.29 (GND), U3.2 (VSS), U3.7 (EXP), U4.4 (GND), U5.1, U5.11, U5.12, U6.2 (GND), U7.3 (CLKOE), U7.5 (VSS), U$1.11 (P0.09/NFC1), U$1.12 (P0.10/NFC2), U$1.31 (VSS), U$1.45 (VSS), U$1.PAD (VSS), U$1.PAD@VIA01 (VSS), U$1.PAD@VIA02 (VSS), U$1.PAD@VIA03 (VSS), U$1.PAD@VIA04 (VSS), U$1.PAD@VIA05 (VSS), U$1.PAD@VIA06 (VSS), U$1.PAD@VIA07 (VSS), U$1.PAD@VIA08 (VSS), U$1.PAD@VIA09 (VSS), U$1.PAD@VIA10 (VSS), U$1.PAD@VIA11 (VSS), U$1.PAD@VIA12 (VSS), U$1.PAD@VIA13 (VSS), U$1.PAD@VIA14 (VSS), U$1.PAD@VIA15 (VSS), U$1.PAD@VIA16 (VSS), U$2.2 (GND), U$2.5 (GND1), U$2.13 (GND2)
INT_BMI: U$1.18 (P0.15)
INT_OPT: U$1.19 (P0.16)
INT_RTC: U7.4 (!INT!)
LED1: R8.1, U1.42 ((VSPIHD/HS2_CMD)GPIO21)
LED2: R7.1, U1.39 ((VSPIWP/HS2_CLK)GPIO22)
LED3: R5.1, U1.36 (GPIO23)
LED4: R6.1, U1.15 ((DAC2/ADC2:9/RTC7)GPIO26)
LED5: R12.1, U$1.16 (P0.13)
LED6: R13.1, U$1.17 (P0.14)
MISO: U1.18 ((GPIO12/ADC2:5/TOUCH5/RTC15/SPIQ)MTDI)
MOSI: U1.20 ((GPIO13/ADC2:4/TOUCH4/RTC14/SPID/U0CTS)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), U$2.8 (DATA)
unnamed: C1.1, U$1.2 (P0.00/XL1), X1.2
unnamed: C2.1, U$1.3 (P0.01/XL2), X1.1
unnamed: C3.1, U$1.35 (XC2), Y1.3 (2)
unnamed: C4.1, U$1.34 (XC1), Y1.1
unnamed: C5.2, U$1.1 (DEC1)
unnamed: C8.2, L1.1, U$1.30 (ANT)
unnamed: C13.1, U1.44 (XTAL_N), Y2.3 (2)
unnamed: C12.1, U1.45 (XTAL_P), Y2.1
unnamed: L4.2, U$1.47 (DCC)
unnamed: L4.1, L5.2
unnamed: C10.1, L5.1, U$1.46 (DEC4)
unnamed: C15.1, U1.12 (32K_XP(GPIO32/ADC1:4/TOUCH9/RTC9)), X2.2
unnamed: C16.1, U1.13 (32K_XN(GPIO33/ADC1:5/TOUCH8/RTC8)), X2.1
unnamed: C18.1, R4.1, U1.47 (CAP2)
unnamed: R19.2, T1.B
unnamed: C17.2, C18.2, R4.2, U1.48 (CAP1)
unnamed: R20.2, T2.B
unnamed: D3.1, R5.2
unnamed: D7.1, R7.2
unnamed: D8.1, R8.2
unnamed: C19.1, L2.1, U1.2 (LNA_IN)
unnamed: D2.1, R6.2
unnamed: D4.1, R10.2
unnamed: D1.1, R12.2
unnamed: D5.1, R13.2
unnamed: C19.2, C20.2, J1.FEED (SIGNAL)
unnamed: R9.1, U$2.3 (LEDK)
unnamed: C23.2, S1.1, U6.5 (OUT)
unnamed: D9.1, R18.2
unnamed: U7.1 (OSCI), X4.2
unnamed: U7.2 (OSCO), X4.1
unnamed: R11.1, T3.B
unnamed: R9.2, T3.C
NRESET: R1.1, U5.7, U$1.24 (P0.21/RESET)
RFP1: C9.2, J3.FEED (SIGNAL), L1.2
RST: C25.1, R15.1, RESET.2, T2.C, U1.9 (CHIP_PU)
RTS: R19.1, T2.E, U2.24 (RTS)
RX: U1.16 ((ADC2:7/TOUCH7/RTC17)GPIO27), U5.4, U$1.10 (P0.08)
RXD: U1.40 ((GPIO3/CLK_OUT2/HS2_DATA0)U0RXD), U2.26 (TXD)
SCK/CLK: U1.31 ((GPIO6/SPICLK/HS1_CLK/U1CTS)SD_CLK), U4.6 (CLK)
SCL: R3.1, U1.35 ((VSPICLK/HS1_DATA7)GPIO18), U3.6 (SCL), U7.7 (SCL)
SCS/CMD: U1.30 ((GPIO11/SPICSO/HS1_CMD/U1RTS)SD_CMD), U4.1 (!CS)
SDA: R2.1, U1.38 ((VSPIQ/HS2_DATA2)GPIO19), U3.1 (SDA), U7.6 (SDA)
SDI/SD1: U1.33 ((GPIO8/SPID/HS1_DATA1)SD_DATA1), U4.5 (DI(IO0))
SDO/SD0: U1.32 ((GPIO7/SPI1/HS1_DATA0)SD_DATA0), U4.2 (DO(IO1))
SHD/SD2: U1.28 ((GPIO9/SPIHD/HS1_DATA2/U1RX)SD_DATA2), U4.7 (!HOLD!/!RESET!(IO3))
SWDCLK: U5.8, U$1.25 (SWDCLK)
SWDIO: U5.9, U$1.26 (SWDIO)
SWO: U5.6, U$1.21 (P0.18/SWO)
SWP/SD3: U1.29 ((GPIO10/SPIWP/HS1_DATA3/U1TX)SD_DATA3), U4.3 (!WP!(IO2))
TFTDC: U1.27 ((HS1_DATA5)GPIO17), U$2.7 (RS/DC)
TFTRESET: U1.25 ((HS1_DATA4)GPIO16), U$2.6 (RESET)
TX: U1.14 ((DAC1/ADC2:8/RTC6)GPIO25), U5.3, U$1.8 (P0.06)
TXD: U1.41 ((GPIO1/CLK_OUT3/HS2_DATA1)U0TXD), U2.25 (RXD)
VDD: C6.2, C7.2, C11.1, C14.2, C22.2, C24.2, C26.1, C27.1, C28.1, C29.1, C33.1, R1.2, R2.2, R3.2, R10.1, R15.2, S1.2, U1.1 (VDDA), U1.3 (VDDA3P3), U1.4 (VDDA3P3), U1.19 (VDD3P3_RTC), U1.37 (VDD3P3_CPU), U1.43 (VDDA), U1.46 (VDDA), U2.6 (VDD), U3.5 (VDD), U5.2, U7.10 (VDD), U$1.13 (VDD), U$1.36 (VDD), U$1.48 (VDD), U$2.4 (LEDA), U$2.10 (VCC), U$2.11 (VCC2)
VDD_SDIO: C21.1, R18.1, U1.26 (VDD3P3_SDIO), U4.8 (VCC)

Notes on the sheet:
USB & Reset/Boot Circuits
Indicator LEDs
SPI Flash
USB to UART Converter
External RTC
Temperature and Humidity Sensor
FFC Debug Connector
TFT LCD
USB Type C Reversible Connector (Female)
USB Voltage Regulator
nRF52832 SoC
ESP32
Gateway v1


Board: 4 copper layers, 34.0 x 42.0 mm, 83 parts (0 on the bottom side), 72 nets.

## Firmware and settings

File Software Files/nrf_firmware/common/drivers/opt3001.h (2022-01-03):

#ifndef __OPT3001_h__
#define __OPT3001_h__
#define __OPT3001_h__

#include <stdint.h>
#include "nrf_drv_twi.h"

#define DEFAULT_CONFIG_800    0b1100110000010000 // 800ms
#define DEFAULT_CONFIG_800_OS 0b1100101000010000 // 800ms, one shot

#define DEFAULT_CONFIG_100    0b1100010000010000 // 100ms
#define DEFAULT_CONFIG_100_OS 0b1100001000010000 // 100ms, one shot

#define DEFAULT_CONFIG_SHDWN  0xc810 // Shut down converter

/* 	CONFIG REGISTER BITS: RN3 RN2 RN1 RN0 CT M1 M0 OVF CRF FH FL L Pol ME FC1 FC0
	RN3 to RN0 = Range select:
                    1100 by default, enables auto-range 
	CT = Conversion time bit
                    0 = 100ms conversion time
                    1 = 800ms conversion time (default)
	M1 to M0 = Mode bits
                    00 = Shutdown mode
                    01 = Single shot mode
                    10 = Continuous conversion (default)
                    11 = Continuous conversion
	OVF (Bit 8)     Overflow flag. When set the conversion result is overflown.
	CRF (Bit 7)     Conversion ready flag. Sets at end of conversion. Clears by read or write of the Configuration register.
	FH (Bit 6)      Flag high bit. Read only. Sets when result is higher that TH register. Clears when Config register is 
					read or when Latch bit is 0 and the result goes bellow TH register.
	FL (Bit 5)      Flag low bit. Read only. Sets when result is lower that TL register. Clears when Config register is read 
                    or when Latch bit is 0 and the result goes above TL register.
	L (Bit 4)       Latch bit. Read/write bit. Default 1, Controls Latch/transparent functionality of FH and FL bits. When 
                    L = 1 the Alert pin works in window comparator mode with Latched functionality When L = 0 the Alert pin 
                    works in transparent mode and the two limit registers provide the hysteresis.
	Pol (Bit 3)     Polarity. Read/write bit. Default 0, Controls the active state of the Alert pin. Pol = 0 means Alert 
                    active low.
	ME (Bit 2)      Exponent mask. In fixed range modes masks the exponent bits in the result register to 0000.
	FC1 to FC0  -   Fault count bits. Read/write bits. Default 00 - the first fault will trigger the alert pin.
*/

uint16_t opt3001_read_reg(uint8_t reg);
void opt3001_write_reg(uint8_t reg, uint8_t dataL, uint8_t dataH);
void opt3001_init(const nrf_drv_twi_t *l_twi);
uint16_t opt3001_read(void);
float opt3001_conv(uint16_t raw);
void opt3001_deinit(void);
int opt3001_is_measuring(void);



#define OPT3001_CFG_FL          (1 << 5)
#define OPT3001_CFG_FH          (1 << 6)
#define OPT3001_CFG_CRF         (1 << 7)
#define OPT3001_CFG_OVF         (1 << 8)
#define OPT3001_CFG_L           (1 << 4)
#define OPT3001_CFG_POL         (1 << 3)
#define OPT3001_CFG_ME          (1 << 2)
#define OPT3001_CFG_CT          (1 << 11)
#define OPT3001_CFG_FC_SHIFT    0
#define OPT3001_CFG_FC_MASK     (0x03 << OPT3001_CFG_FC_SHIFT)
#define OPT3001_CFG_M_SHIFT     9
#define OPT3001_CFG_M_MASK      (0x03 << OPT3001_CFG_M_SHIFT)
#define OPT3001_CFG_RN_SHIFT    12
#define OPT3001_CFG_RN_MASK     (0xf << OPT3001_CFG_RN_SHIFT)




#endif // __OPT3001_h__

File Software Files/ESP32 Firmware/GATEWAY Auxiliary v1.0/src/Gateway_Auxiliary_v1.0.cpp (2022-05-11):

/*Includes */
#include <Arduino.h>
#include <WiFi.h>
#include <NTPClient.h>
#include <WiFiUdp.h>
#include <PCF85063A.h>
#include <Wire.h>
#include "DFRobot_SHT20.h"
#include <Adafruit_GFX.h>
#include <Adafruit_SSD1306.h>
#include <Fonts/FreeMonoBold9pt7b.h>
#include <Fonts/FreeSans9pt7b.h>
#include <Adafruit_I2CDevice.h>
#include <WiFiMulti.h>
#include <TimeLib.h>
WiFiMulti wifiMulti;
#define DEVICE "ESP32"
#include <InfluxDbClient.h>
#include <InfluxDbCloud.h>
#include <BMI160Gen.h>
#include <Adafruit_I2CDevice.h>
#include <esp_now.h>

#ifdef __cplusplus
extern "C"
{
#endif

  uint8_t temprature_sens_read();

#ifdef __cplusplus
}
#endif

//uint8_t bc_addr[] = {0x4c, 0x11, 0xae, 0x78, 0xea, 0x10};
uint8_t bc_addr[] = {0x30, 0xae, 0xa4, 0x05, 0x4c, 0x0c};
uint8_t espnow_in = 0;
bool espnowrefresh = false;
bool no_fail = false;
int connection = 1;
/* Functions */
void motiontriggered();
void scandevices();
void influxDB(void *pvParameters);
void serialparser(void *pvParameters);
void displayui(void *pvParameters);
void tempdisp(void *pvParameters);

/* InfluxDB Connection Parameters */
#define WIFI_SSID ""
#define WIFI_PASSWORD ""
#define INFLUXDB_URL ""
#define INFLUXDB_TOKEN ""
#define INFLUXDB_ORG ""
#define INFLUXDB_BUCKET ""
#define TZ_INFO ""

String hostname = "";
/* InfluxDB Data Points */
Point Reset("Reset");
Point Status("Status");
Point Battery("Battery");
Point Environment("Environment");
Point Motion("Motion");
Point VOC("VOC");
Point Detector("Detector");
Point CO2("CO2");
Point ALS("ALS");
Point GATEWAY("GATEWAY");
Point NC("NC");

/* Queue Handles */
static int queue_len = 10;
static QueueHandle_t rst_queue;
static QueueHandle_t stat_queue;
static QueueHandle_t batt_queue;
static QueueHandle_t env_queue;
static QueueHandle_t mot_queue;
static QueueHandle_t det_queue;
static QueueHandle_t co2_queue;
static QueueHandle_t als_queue;
static QueueHandle_t voc_queue;

/* Task Handles */
static TaskHandle_t ifdb;
static TaskHandle_t serp;
static TaskHandle_t disp;
static TaskHandle_t tmp;

/* Timer Handles */
TimerHandle_t displaySubTimer;
TimerHandle_t gatewayUpdateTimer;
TimerHandle_t scanDeviceIntTimer;
TimerHandle_t scanDeviceDurTimer;
TimerHandle_t espnowRefreshTimer;

#define DISPLAY_UPDATE_RATE_MS 2500
#define SELF_REPORT_INTERVAL_MS 5000
#define DEVICE_SCAN_INTERVAL 1800000
#define DEVICE_SCAN_DURATION 600000
#define MAXIMUM_NO_REPLY_FROM_MAIN 30000

/* Data Structures */
struct rst_struct
{
  String uid;
  uint32_t rst;
};
struct stat_struct
{
  String uid;
  float alive;
  float rssi;
  float retx;
};
struct batt_struct
{
  String uid;
  float volt;
};
struct env_struct
{
  String uid;
  float light;
  float temp;
  float press;
  float hum;
};
struct mot_struct
{
  String uid;
  float x;
  float y;
  float z;
  float shock_dur;
  float shock_count;
  float step_count;
};
struct det_struct
{
  String uid;
  float distance;
  float cal_point;
  float cal_tolerance;
  float range_mode;
  float count;
  float warning;
};
struct co2_struct
{
  String uid;
  float temp;
  float hum;
  float press;
  float co2;
  float stat;
};
struct als_struct
{
  String uid;
  float lux;
  float lux2;
  float w;
  float uvi;
};
struct voc_struct
{
  String uid;
  float light;
  float temp;
  float press;
  float hum;
  float voc;
};

/* WMNS Alive Packet Device-Specific TXN Rate/h */
float alive_rate_r = 0.0083;  // for routers
float alive_rate_lp = 0.0833; // for all other LP nodes

/* GATEWAY Status Information */
#define SELF_UID 1
#define SELF_CH 50
struct self_struct
{
  String uid = (String)SELF_UID;
  String ch = (String)SELF_CH;
  float temp;
  float hum;
  int rssi;
  uint32_t COUNT_INTRUSIONTRIG = 0;
  uint32_t COUNT_QUEUEOVERFLOW = 0;     //QOV
  uint32_t COUNT_QUEUEWRITEFAIL = 0;    //QWF
  uint32_t COUNT_RXPIDOUTOFBOUNDS = 0;  //PXB
  uint32_t COUNT_RXUIDOUTOFBOUNDS = 0;  //UXB
  uint32_t COUNT_IFDBWRITEFAIL = 0;     //IFF
  uint32_t COUNT_TOTALTXNFROMSTART = 0; //TXN
  uint8_t COUNT_NUM_LP = 0;
  uint8_t COUNT_NUM_R = 0;
  uint8_t COUNT_NUM_G = 0;
} self;

/* Strings to store incoming UART data */
String uart_recv_buffer;

/* Global variables for serial parser */
String uart_recv_pid;
String uart_recv_uid;
int pid;
int uid;

/* Global variables for display UI */
bool s_timer = true;
long int startup_time_rtc;

/* Global variables for device counter */
int uid_lp[255] = {};
int uid_r[255] = {};
int uid_g[255] = {};
int uid_lp_pos = 1;
int uid_r_pos = 1;
int uid_g_pos = 1;
int uid_temp[3] = {};
bool scan = false;

/* Global variables for intrusion protection */
bool motion = false;

/* Global variables for self update */
bool update_self = false;

/* Pin configuration */
#define UART2_TX 27
#define UART2_RX 25
#define LED1 2
#define LED2 4
#define LED3 23
#define LED4 26
#define SDA2 19
#define SCL2 18
#define SDA1 17
#define SCL1 16

/* Comms configuration */
#define UART_BAUDRATE 115200
#define I2C_CLK_RATE 100000

/* Registered PIDs in the mesh network */
typedef enum
{
  PID_RESET = 0,
  PID_STATUS,
  PID_BATTERY,
  PID_ENVIRONMENT = 176,
  PID_MOTION,
  PID_VOC,
  PID_DETECTOR,
  PID_CO2,
  PID_ALS,
} dev_pid_t;

/* Bitmaps for display */
const unsigned char symbol[] PROGMEM = {
    0x00, 0x00, 0x00, 0x00, 0x00, 0x1f, 0x00, 0x00, 0x00, 0x3f, 0xe0, 0x00, 0x00, 0x7f, 0xfc, 0x00,
    0x00, 0xf6, 0xff, 0xc0, 0x01, 0xe3, 0x1f, 0xf0, 0x03, 0xc1, 0x83, 0xf0, 0x0f, 0x80, 0xc7, 0xf0,
    0x1f, 0x00, 0x7c, 0x38, 0x3c, 0x00, 0xe0, 0x38, 0x78, 0x01, 0xa0, 0x38, 0x70, 0x03, 0x20, 0x38,
    0x78, 0x06, 0x30, 0x1c, 0x7c, 0x0c, 0x10, 0x1c, 0x7e, 0x18, 0x10, 0x1c, 0x3a, 0x30, 0x10, 0x1c,
    0x39, 0xe0, 0x18, 0x1c, 0x38, 0xe0, 0x18, 0x0e, 0x38, 0xfc, 0x08, 0x0e, 0x1d, 0x87, 0x88, 0x1e,
    0x1d, 0x00, 0xff, 0xfe, 0x1d, 0x00, 0x1e, 0x3c, 0x1f, 0x00, 0x08, 0x78, 0x0e, 0x00, 0x08, 0xf0,
    0x0e, 0x00, 0x19, 0xe0, 0x0f, 0x80, 0x13, 0xc0, 0x0f, 0xf0, 0x17, 0x80, 0x03, 0xff, 0x3f, 0x00,
    0x00, 0x7f, 0xfe, 0x00, 0x00, 0x0f, 0xfc, 0x00, 0x00, 0x01, 0xf0, 0x00, 0x00, 0x00, 0x00, 0x00};

const unsigned char wifi[] PROGMEM = {
    0x00, 0x00, 0x07, 0xe0, 0x1f, 0xf8, 0x38, 0x3c, 0xf3, 0x8f, 0xcf, 0xf3, 0x1e, 0x78, 0x38, 0x18,
    0x07, 0xc0, 0x07, 0xe0, 0x00, 0x00, 0x01, 0x80, 0x01, 0x80, 0x00, 0x00};

const unsigned char aux_linked[] PROGMEM = {
    0x00, 0x10, 0x00, 0x7c, 0x01, 0xe6, 0x01, 0xc6, 0x00, 0x02, 0x0f, 0xc6, 0x1f, 0xee, 0x38, 0x1c,
    0x77, 0x78, 0xe3, 0xf0, 0xc0, 0x00, 0xe3, 0x80, 0xe7, 0x80, 0x3e, 0x00, 0x00, 0x00};

/* Objects */
DFRobot_SHT20 sht20;
PCF85063A rtc;
WiFiServer server(80);
Adafruit_SSD1306 display(128, 64, &Wire, 4);
WiFiUDP ntpUDP;
NTPClient timeClient(ntpUDP);
InfluxDBClient client(INFLUXDB_URL, INFLUXDB_ORG, INFLUXDB_BUCKET, INFLUXDB_TOKEN, InfluxDbCloud2CACert);

void IRAM_ATTR MOTION_ISR(void)
{
  motion = true;
  Serial.println("[M_ISR] MOTION DETECTED");
}
void vTimerCallback1(TimerHandle_t displaySubTimer)
{
  s_timer = !s_timer;
}
void vTimerCallback2(TimerHandle_t gatewayUpdateTimer)
{
  update_self = true;
}

void vTimerCallback3(TimerHandle_t scanDeviceIntTimer)
{
  Serial.println("[VTIMERCALLBACK3] SCAN INITIATED");
  scan = true;
  uid_temp[0] = uid_lp_pos - 1;
  uid_temp[1] = uid_r_pos - 1;
  uid_temp[2] = uid_g_pos - 1;
  for (int i = 0; i < 255; i++)
  {
    uid_lp[i] = 0;
    uid_r[i] = 0;
    uid_g[i] = 0;
  }
  uid_lp_pos = 1;
  uid_r_pos = 1;
  uid_g_pos = 1;
}
void vTimerCallback4(TimerHandle_t scanDeviceDurTimer)
{
  Serial.println("[VTIMERCALLBACK4] SCAN TERMINATED");
  scan = false;
  uid_temp[0] = 0;
  uid_temp[1] = 0;
  uid_temp[2] = 0;
  xTimerStop(scanDeviceDurTimer, 10);
}

void vTimerCallback5(TimerHandle_t espnowRefreshTimer)
{
  espnowrefresh = true;
}

// Callback when data is received
void OnDataRecv(const uint8_t *mac, const uint8_t *incomingData, int len)
{
  Serial.print(*incomingData);
  memcpy(&espnow_in, incomingData, sizeof(espnow_in));
}
/*! setup() :: TASK
   @brief initializes peripherals, database connection and starts tasks influxDB() and serialparser()

   @note TASK no pin

   @param void
*/
void setup()
{

  Serial.begin(UART_BAUDRATE);
  Serial2.begin(UART_BAUDRATE, SERIAL_8N1, UART2_RX, UART2_TX); // initialize comms with nRF52
  Wire.begin(SDA1, SCL1, (uint32_t)I2C_CLK_RATE);                         // initialize I2C for display (I2C0)
  Wire1.begin(SDA2, SCL2, (uint32_t)I2C_CLK_RATE);                        // initialize I2C for RTC and temp/hum sensor

  pinMode(LED1, OUTPUT);
  pinMode(LED2, OUTPUT);
  pinMode(LED3, OUTPUT);
  pinMode(LED4, OUTPUT);
  display.begin(SSD1306_SWITCHCAPVCC, 0x3C);
  display.ssd1306_command(SSD1306_SETCONTRAST);
  display.ssd1306_command(50);
  display.clearDisplay();
  display.setTextColor(WHITE);
  display.setCursor(10, 30);
  display.print("initializing ...");
  display.display();

  Serial.println("[INIT] STARTUP INITIALIZATION OK");
  WiFi.mode(WIFI_AP_STA);
  WiFi.begin(WIFI_SSID, WIFI_PASSWORD);
  WiFi.config(INADDR_NONE, INADDR_NONE, INADDR_NONE, INADDR_NONE);
  WiFi.setHostname(hostname.c_str()); //define hostname
  while (WiFi.status() != WL_CONNECTED)
  {
    Serial.println("[INIT] ERROR CONNECTING TO WIFI");
    WiFi.disconnect();
    WiFi.begin(WIFI_SSID, WIFI_PASSWORD);
    vTaskDelay(2000);
  }
  Serial.println("[INIT] WIFI CONNECTION OK");
  rtc.reset();
  Serial.println("[INIT] RTC OK");
  delay(10);
  tmElements_t tm;
  timeClient.begin();
  timeClient.setTimeOffset(28800);
  while (!timeClient.update())
  {
    timeClient.forceUpdate();
  }
  breakTime(timeClient.getEpochTime(), tm);
  rtc.time_set(&tm);
  delay(50);
  tmElements_t t;
  rtc.time_get(&t);
  startup_time_rtc = makeTime(t);
  Serial.println("[INIT] TIME SYNC OK");
  // Accurate time is necessary for certificate validation and writing in batches
  // For the fastest time sync find NTP servers in your area: https://www.pool.ntp.org/zone/
  // Syncing progress and the time will be printed to Serial.
  timeSync(TZ_INFO, "pool.ntp.org", "time.nis.gov");

  client.setHTTPOptions(HTTPOptions().httpReadTimeout(200));
  client.setHTTPOptions(HTTPOptions().connectionReuse(true));
  // Check server connection
  if (client.validateConnection())
  {
    Serial.print("Connected to InfluxDB: ");
    Serial.println(client.getServerUrl());
  }
  else
  {
    Serial.print("InfluxDB connection failed: ");
    Serial.println(client.getLastErrorMessage());
  }
  Serial.println("[INIT] IFDB CONNECTION OK");
  // Init ESP-NOW
  if (esp_now_init() != ESP_OK)
  {
    Serial.println("Error initializing ESP-NOW");
    return;
  }

  // Once ESPNow is successfully Init, we will register for recv CB to
  // get recv packer info
  esp_now_register_recv_cb(OnDataRecv);

  /***************************************************************************************************************/

  display.clearDisplay();
  display.setTextSize(2);
  espnowRefreshTimer = xTimerCreate("Timer5", MAXIMUM_NO_REPLY_FROM_MAIN, pdTRUE, (void *)0, vTimerCallback5);
  xTimerStart(espnowRefreshTimer, 0);
  /* String query = "from(bucket: \"MESH\") |> range(start: -30s) |> filter(fn: (r) => r._measurement == \"GATEWAY\") |> filter(fn: (r) => r._field == \"RF Channel\") |> max()";

  while (blocker == 50)
  {

    FluxQueryResult result = client.query(query);
    blocker = 0;
    Serial.print(blocker);

    // code to print serial terminal data and additional stats
    while (result.next())
    {

      blocker = result.getValueByName("_value").getDouble();
      Serial.print("DATA");
    }
    Serial.print(result.getError());
    if (result.getError() != "")
    {
      blocker = 50;
      Serial.print("ERROR");
    }
*/

  xTaskCreate(     // Use xTaskCreate()
      tempdisp,    // Function to be called
      "Temp disp", // Name of task
      16384,       // Stack size
      NULL,        // Parameter to pass
      1,           // Task priority
      &tmp);
  while (!no_fail)
  {

    if (espnowrefresh == true)
    {
      if (espnow_in != 201)
      {
        Serial.print("MAIN GATEWAY FAILED");
        no_fail = true;
      }
      else
      {
        espnow_in = 0;
      }
      espnowrefresh = false;
    }
  }
  vTaskDelete(tmp);
  xTimerDelete(espnowRefreshTimer, 0);

  sht20.initSHT20(Wire1);
  Serial.println("[INIT] TEMP SENSOR OK");

  BMI160.begin(BMI160GenClass::I2C_MODE, 0x68, 5);
  BMI160.attachInterrupt(MOTION_ISR);
  BMI160.setIntMotionEnabled(true);
  Serial.println("[INIT] MOTION SENSOR OK");

  rst_queue = xQueueCreate(queue_len, sizeof(struct rst_struct));
  stat_queue = xQueueCreate(queue_len, sizeof(struct stat_struct));
  batt_queue = xQueueCreate(queue_len, sizeof(struct batt_struct));
  env_queue = xQueueCreate(queue_len, sizeof(struct env_struct));
  mot_queue = xQueueCreate(queue_len, sizeof(struct mot_struct));
  det_queue = xQueueCreate(queue_len, sizeof(struct det_struct));
  co2_queue = xQueueCreate(queue_len, sizeof(struct co2_struct));
  als_queue = xQueueCreate(queue_len, sizeof(struct als_struct));
  voc_queue = xQueueCreate(queue_len, sizeof(struct voc_struct));
  Serial.println("[INIT] IFDB QUEUES CREATED");

  gatewayUpdateTimer = xTimerCreate("Timer2", SELF_REPORT_INTERVAL_MS, pdTRUE, (void *)0, vTimerCallback2);
  xTimerStart(gatewayUpdateTimer, 0);

  Serial.println("[INIT] IFDB TIMERS STARTED");

  xTaskCreatePinnedToCore( // Use xTaskCreate()
      influxDB,            // Function to be called
      "Influx DB",         // Name of task
      32768,               // Stack size
      NULL,                // Parameter to pass
      1,                   // Task priority
      &ifdb,               // Task handle
      0);                  // CPU Core

  Serial.println("[INIT] TASK IFDB CREATED");
  xTaskCreatePinnedToCore( // Use xTaskCreate()
      serialparser,        // Function to be called
      "Serial Parser",     // Name of task
      16384,               // Stack size
      NULL,                // Parameter to pass
      1,                   // Task priority
      &serp,               // Task handle
      1);                  // CPU Core
  Serial.println("[INIT] TASK SERP CREATED");
  vTaskDelete(NULL);
  Serial.println("[INIT] TASK INIT TERMINATED");
}

/*! influxDB() :: TASK
   @brief receives data structs from queues and posts data to InfluxDB.

   @note HIGHEST PRIORITY TASK pinned to core 0

   @param pvParameters task structure
*/
void influxDB(void *pvParameters)
{

  xTaskCreatePinnedToCore( // Use xTaskCreate()
      displayui,           // Function to be called
      "Display UI",        // Name of task
      4096,                // Stack size
      NULL,                // Parameter to pass
      0,                   // Task priority
      &disp,               // Task handle
      0);                  // CPU Core*/

  Serial.println("[IFDB] STARTED TASK");
  while (true)
  {
    if (WiFi.status() != WL_CONNECTED)
    {
      Serial.println("[IFDB] WIFI RECONNECTION ATTEMPTED");
      WiFi.disconnect();
      WiFi.begin(WIFI_SSID, WIFI_PASSWORD);
      vTaskDelay(2000);
    }

    if (uxQueueMessagesWaiting(rst_queue) > 0)
    {
      struct rst_struct RST_OUT;
      if (xQueueReceive(rst_queue, (void *)&RST_OUT, 1) == pdPASS)
      {
        Serial.print(RST_OUT.rst);
        Reset.clearFields();
        Reset.clearTags();
        Reset.addTag("UID", (RST_OUT.uid));
        if (RST_OUT.rst == 0)
        {
          Reset.addField("Reset", "PWRRESET");
        }
        else if (RST_OUT.rst == 1)
        {
          Reset.addField("Reset", "SWRESET");
        }
        else if (RST_OUT.rst == 2)
        {
          Reset.addField("Reset", "WATCHDOG");
        }
        else if (RST_OUT.rst == 4)
        {
          Reset.addField("Reset", "LOCKUP");
        }
        else if (RST_OUT.rst == 65536)
        {
          Reset.addField("Reset", "GPIOWAKE");
        }
        else if (RST_OUT.rst == 131072)
        {
          Reset.addField("Reset", "COMPWAKE");
        }
        else if (RST_OUT.rst == 262144)
        {
          Reset.addField("Reset", "DEBUGWAKE");
        }
        else if (RST_OUT.rst == 524288)
        {
          Reset.addField("Reset", "NFCWAKE");
        }
        if (!client.writePoint(Reset))
        {
          self.COUNT_IFDBWRITEFAIL++;
        }
        self.COUNT_TOTALTXNFROMSTART++;
        Serial.print("[IFDB] TXN ");
        Serial.print(self.COUNT_TOTALTXNFROMSTART);
        Serial.println(" RST COMPLETED");
      }
    }

    if (uxQueueMessagesWaiting(stat_queue) > 0)
    {
      struct stat_struct STAT_OUT;
      if (xQueueReceive(stat_queue, (void *)&STAT_OUT, 1) == pdPASS)
      {
        Status.clearFields();
        Status.clearTags();
        Status.addTag("UID", (STAT_OUT.uid));
        float mul;
        if (((STAT_OUT.uid.toInt()) >= 0 && (STAT_OUT.uid.toInt()) <= 255))
        {
          mul = alive_rate_r;
        }
        else
        {
          mul = alive_rate_lp;
        }
        Status.addField("Alive", (STAT_OUT.alive) * mul);
        Status.addField("RSSI", (STAT_OUT.rssi));
        Status.addField("Retransmissions", (STAT_OUT.retx));
        if (!client.writePoint(Status))
        {
          self.COUNT_IFDBWRITEFAIL++;
        }
        self.COUNT_TOTALTXNFROMSTART++;
        Serial.print("[IFDB] TXN ");
        Serial.print(self.COUNT_TOTALTXNFROMSTART);
        Serial.println(" STAT COMPLETED");
      }
    }

    if (uxQueueMessagesWaiting(batt_queue) > 0)
    {
      struct batt_struct BATT_OUT;
      if (xQueueReceive(batt_queue, (void *)&BATT_OUT, 1) == pdPASS)
      {
        Battery.clearFields();
        Battery.clearTags();
        Battery.addTag("UID", (BATT_OUT.uid));
        Battery.addField("Voltage", (BATT_OUT.volt));
        if (!client.writePoint(Battery))
        {
          self.COUNT_IFDBWRITEFAIL++;
        }
        self.COUNT_TOTALTXNFROMSTART++;
        Serial.print("[IFDB] TXN ");
        Serial.print(self.COUNT_TOTALTXNFROMSTART);
        Serial.println(" BATT COMPLETED");
      }
    }

    if (uxQueueMessagesWaiting(env_queue) > 0)
    {
      struct env_struct ENV_OUT;
      if (xQueueReceive(env_queue, (void *)&ENV_OUT, 1) == pdPASS)
      {
        Environment.clearFields();
        Environment.clearTags();
        Environment.addTag("UID", (ENV_OUT.uid));
        Environment.addField("Temperature", (ENV_OUT.temp));
        Environment.addField("Humidity", (ENV_OUT.hum));
        Environment.addField("Pressure", (ENV_OUT.press));
        Environment.addField("Light", (ENV_OUT.light));
        if (!client.writePoint(Environment))
        {
          self.COUNT_IFDBWRITEFAIL++;
        }
        self.COUNT_TOTALTXNFROMSTART++;
        Serial.print("[IFDB] TXN ");
        Serial.print(self.COUNT_TOTALTXNFROMSTART);
        Serial.println(" ENV COMPLETED");
      }
    }

    if (uxQueueMessagesWaiting(mot_queue) > 0)
    {
      struct mot_struct MOT_OUT;
      if (xQueueReceive(mot_queue, (void *)&MOT_OUT, 1) == pdPASS)
      {
        Motion.clearFields();
        Motion.clearTags();
        Motion.addTag("UID", (MOT_OUT.uid));
        Motion.addField("X-axis", (MOT_OUT.x));
        Motion.addField("Y-axis", (MOT_OUT.y));
        Motion.addField("Z-axis", (MOT_OUT.z));
        Motion.addField("Impact counter", (MOT_OUT.shock_count));
        Motion.addField("Duration of impacts", (MOT_OUT.shock_dur));
        Motion.addField("Step counter", (MOT_OUT.step_count));
        if (!client.writePoint(Motion))
        {
          self.COUNT_IFDBWRITEFAIL++;
        }
        self.COUNT_TOTALTXNFROMSTART++;
        Serial.print("[IFDB] TXN ");
        Serial.print(self.COUNT_TOTALTXNFROMSTART);
        Serial.println(" MOT COMPLETED");
      }
    }

    if (uxQueueMessagesWaiting(det_queue) > 0)
    {
      struct det_struct DET_OUT;
      if (xQueueReceive(det_queue, (void *)&DET_OUT, 1) == pdPASS)
      {
        Serial.print(DET_OUT.cal_point);
        Serial.print(DET_OUT.cal_tolerance);
        Detector.clearFields();
        Detector.clearTags();
        Detector.addTag("UID", (DET_OUT.uid));
        Detector.addField("Distance", (DET_OUT.distance));
        Detector.addField("Max. Tolerance", (DET_OUT.cal_point) + (DET_OUT.cal_tolerance));
        Detector.addField("Min. Tolerance", (DET_OUT.cal_point) - (DET_OUT.cal_tolerance));
        Detector.addField("Mode", (DET_OUT.range_mode));
        Detector.addField("Counter", (DET_OUT.count));
        if (!client.writePoint(Detector))
        {
          self.COUNT_IFDBWRITEFAIL++;
        }
        self.COUNT_TOTALTXNFROMSTART++;
        Serial.print("[IFDB] TXN ");
        Serial.print(self.COUNT_TOTALTXNFROMSTART);
        Serial.println(" DET COMPLETED");
      }
    }

    if (uxQueueMessagesWaiting(co2_queue) > 0)
    {
      struct co2_struct CO2_OUT;
      if (xQueueReceive(co2_queue, (void *)&CO2_OUT, 1) == pdPASS)
      {
        CO2.clearFields();
        CO2.clearTags();
        CO2.addTag("UID", (CO2_OUT.uid));
        CO2.addField("CO2", (CO2_OUT.co2));
        if (!client.writePoint(CO2))
        {
          self.COUNT_IFDBWRITEFAIL++;
        }
        self.COUNT_TOTALTXNFROMSTART++;
        Serial.print("[IFDB] TXN ");
        Serial.print(self.COUNT_TOTALTXNFROMSTART);
        Serial.println(" CO2 COMPLETED");
      }
    }

    if (uxQueueMessagesWaiting(als_queue) > 0)
    {
      struct als_struct ALS_OUT;
      if (xQueueReceive(als_queue, (void *)&ALS_OUT, 1) == pdPASS)
      {
        ALS.clearFields();
        ALS.clearTags();
        ALS.addTag("UID", (ALS_OUT.uid));
        ALS.addField("ALS1", (ALS_OUT.lux));
        ALS.addField("ALS2", (ALS_OUT.lux2));
        ALS.addField("W", (ALS_OUT.w));
        ALS.addField("UVI", (ALS_OUT.uvi));
        if (!client.writePoint(ALS))
        {
          self.COUNT_IFDBWRITEFAIL++;
        }
        self.COUNT_TOTALTXNFROMSTART++;
        Serial.print("[IFDB] TXN ");
        Serial.print(self.COUNT_TOTALTXNFROMSTART);
        Serial.println(" ALS COMPLETED");
      }
    }
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
void loop() {}

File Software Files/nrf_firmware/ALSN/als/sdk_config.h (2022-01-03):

/**
 * Copyright (c) 2017 - 2018, Nordic Semiconductor ASA
 * 
 * All rights reserved.
 * 
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
 * 3. Neither the name of Nordic Semiconductor ASA nor the names of its
 *    contributors may be used to endorse or promote products derived from this
 *    software without specific prior written permission.
 * 
 * 4. This software, with or without modification, must only be used with a
 *    Nordic Semiconductor ASA integrated circuit.
 * 
 * 5. Any software provided in binary form under this license must not be reverse
 *    engineered, decompiled, modified and/or disassembled.
 * 
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
 */



#ifndef SDK_CONFIG_H
#define SDK_CONFIG_H
// <<< Use Configuration Wizard in Context Menu >>>\n
#ifdef USE_APP_CONFIG
#include "app_config.h"
#endif

// <h> Application

// <e> CLOCKS_CONFIG_LOG_ENABLED - Enables logging in the module.
//==========================================================
#ifndef CLOCKS_CONFIG_LOG_ENABLED
#define CLOCKS_CONFIG_LOG_ENABLED 0
#endif
// <o> CLOCKS_CONFIG_LOG_LEVEL  - Default Severity level
 
// <0=> Off 
// <1=> Error 
// <2=> Warning 
// <3=> Info 
// <4=> Debug 

#ifndef CLOCKS_CONFIG_LOG_LEVEL
#define CLOCKS_CONFIG_LOG_LEVEL 3
#endif

// </e>


// <e> BME_CONFIG_LOG_ENABLED - Enables logging in the module.
//==========================================================
#ifndef BME_CONFIG_LOG_ENABLED
#define BME_CONFIG_LOG_ENABLED 0
#endif
// <o> BME_CONFIG_LOG_LEVEL  - Default Severity level
 
// <0=> Off 
// <1=> Error 
// <2=> Warning 
// <3=> Info 
// <4=> Debug 

#ifndef BME_CONFIG_LOG_LEVEL
#define BME_CONFIG_LOG_LEVEL 4
#endif

// </e>

// <e> MESH_CONFIG_LOG_ENABLED - Enables logging in the module.
//==========================================================
#ifndef MESH_CONFIG_LOG_ENABLED
#define MESH_CONFIG_LOG_ENABLED 0
#endif
// <o> MESH_CONFIG_LOG_LEVEL  - Default Severity level
 
// <0=> Off 
// <1=> Error 
// <2=> Warning 
// <3=> Info 
// <4=> Debug 

#ifndef MESH_CONFIG_LOG_LEVEL
#define MESH_CONFIG_LOG_LEVEL 3
#endif

// </e>

// <e> MAX_CONFIG_LOG_ENABLED - Enables logging in the module.
//==========================================================
#ifndef MAX_CONFIG_LOG_ENABLED
#define MAX_CONFIG_LOG_ENABLED 0
#endif
// <o> MAX_CONFIG_LOG_LEVEL  - Default Severity level
 
// <0=> Off 
// <1=> Error 
// <2=> Warning 
// <3=> Info 
// <4=> Debug 

#ifndef MAX_CONFIG_LOG_LEVEL
#define MAX_CONFIG_LOG_LEVEL 4
#endif


// </e>

// <o> TWI_DEFAULT_CONFIG_FREQUENCY  - Frequency
 
// <26738688=> 100k 
// <67108864=> 250k 
// <104857600=> 400k 

#ifndef TWI_DEFAULT_CONFIG_FREQUENCY
#define TWI_DEFAULT_CONFIG_FREQUENCY 26738688
#endif

// <e> BAT_CONFIG_LOG_ENABLED - Enables logging in the module.
//==========================================================
#ifndef BAT_CONFIG_LOG_ENABLED
#define BAT_CONFIG_LOG_ENABLED 0
#endif
// <o> BAT_CONFIG_LOG_LEVEL  - Default Severity level
 
// <0=> Off 
// <1=> Error 
// <2=> Warning 
// <3=> Info 
// <4=> Debug 

#ifndef BAT_CONFIG_LOG_LEVEL
#define BAT_CONFIG_LOG_LEVEL 4
#endif

// </e>


// </h> 
//==========================================================

// <h> nRF_Drivers 
//==========================================================
// <e> CLOCK_ENABLED - nrf_drv_clock - CLOCK peripheral driver
//==========================================================
#ifndef CLOCK_ENABLED
#define CLOCK_ENABLED 1
#endif
#if  CLOCK_ENABLED
    // <o> CLOCK_CONFIG_XTAL_FREQ  - HF XTAL Frequency
    
    // <0=> Default (64 MHz) 

    #ifndef CLOCK_CONFIG_XTAL_FREQ
    #define CLOCK_CONFIG_XTAL_FREQ 1
    #endif

    // <o> CLOCK_CONFIG_LF_SRC  - LF Clock Source
    
    // <0=> RC
    // <1=> XTAL 
    // <2=> Synth 

    #ifndef CLOCK_CONFIG_LF_SRC
    #define CLOCK_CONFIG_LF_SRC 1
    #endif

    // <o> CLOCK_CONFIG_IRQ_PRIORITY  - Interrupt priority
    

    // <i> Priorities 0,2 (nRF51) and 0,1,4,5 (nRF52) are reserved for SoftDevice
    // <0=> 0 (highest) 
    // <1=> 1 
    // <2=> 2 
    // <3=> 3 
    // <4=> 4 
    // <5=> 5 
    // <6=> 6 
    // <7=> 7 

    #ifndef CLOCK_CONFIG_IRQ_PRIORITY
    #define CLOCK_CONFIG_IRQ_PRIORITY 0
    #endif

    // <e> CLOCK_CONFIG_LOG_ENABLED - Enables logging in the module.
    //==========================================================
    #ifndef CLOCK_CONFIG_LOG_ENABLED
    #define CLOCK_CONFIG_LOG_ENABLED 0
    #endif
    #if  CLOCK_CONFIG_LOG_ENABLED
        // <o> CLOCK_CONFIG_LOG_LEVEL  - Default Severity level
        
        // <0=> Off 
        // <1=> Error 
        // <2=> Warning 
        // <3=> Info 
        // <4=> Debug 

        #ifndef CLOCK_CONFIG_LOG_LEVEL
        #define CLOCK_CONFIG_LOG_LEVEL 3
        #endif

        // <o> CLOCK_CONFIG_INFO_COLOR  - ANSI escape code prefix.
        
        // <0=> Default 
        // <1=> Black 
        // <2=> Red 
        // <3=> Green 
        // <4=> Yellow 
        // <5=> Blue 
        // <6=> Magenta 
        // <7=> Cyan 
        // <8=> White
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

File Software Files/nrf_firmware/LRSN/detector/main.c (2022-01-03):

#include <stdbool.h>
#include <stdint.h>
#include <string.h>
#include "sdk_common.h"
#include "nrf.h"
#include "nrf_error.h"
#include "nrf_delay.h"
#include "nrf_gpio.h"
#include "boards.h"
#include "app_util.h"
#include "nrf_drv_clock.h"
#include "nrf_drv_twi.h"
#include "nrf_drv_rtc.h"
#include "nrf_pwr_mgmt.h"
#include "VL53L1X_api.h"
#include "vl53l1_platform.h"
#include "uicr_user_defines.h"

//log
#include "nrf_log.h"
#include "nrf_log_ctrl.h"
#include "nrf_log_default_backends.h"
//drivers

#include "clocks.h"
#include "battery.h"
#include "twi.h"
#include "mesh.h"

/* TWI instance. */
static const nrf_drv_twi_t m_twi = NRF_DRV_TWI_INSTANCE(TWI_INSTANCE_ID);
uint16_t dev = 0x52;

/* Calibration parameters */
uint16_t WINDOW_LOW = 0;
uint16_t WINDOW_HIGH = 0;
uint16_t WINDOW_AVG = 0;
uint16_t WINDOW_RADIUS = 0;
uint8_t MODE = 0;

/* Global variables */
static bool react = false;
static uint32_t cycle_count = 0;
static const uint32_t period_bat = 6;
static uint32_t count = 0;
static uint8_t warn_count = 0;

volatile static uint32_t trig_th = 0;
volatile static bool trig_flag = false;
void recalibration();

void app_mesh_handler(message_t *msg) {
	NRF_LOG_INFO("app_mesh_handler()");
}

void app_rtc_handler() {

	*(volatile uint32_t*) 0x40000EE4 = (*(volatile uint32_t*) 0x10000258
			& 0x0000004F);
	clocks_restart();
	twi_restart();
	nrf_gpio_pin_set (STAT_LED);
	/* Measure battery voltage and transmit message if bat period */
	if ((cycle_count % period_bat) == 0) {

		uint16_t v_bat_mili = get_battery();
		mesh_tx_battery(v_bat_mili);
		mesh_wait_tx();
	} else {
		mesh_tx_alive();
		mesh_wait_tx();
	}
	trig_th = 0;
	trig_flag = false;

	nrf_gpio_pin_clear(STAT_LED);
	cycle_count++;
	twi_stop();
	clocks_stop();

}
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

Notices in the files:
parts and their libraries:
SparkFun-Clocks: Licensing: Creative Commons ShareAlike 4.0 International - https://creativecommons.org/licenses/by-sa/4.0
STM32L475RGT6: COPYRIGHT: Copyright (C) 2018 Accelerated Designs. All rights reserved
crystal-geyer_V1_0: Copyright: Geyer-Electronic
